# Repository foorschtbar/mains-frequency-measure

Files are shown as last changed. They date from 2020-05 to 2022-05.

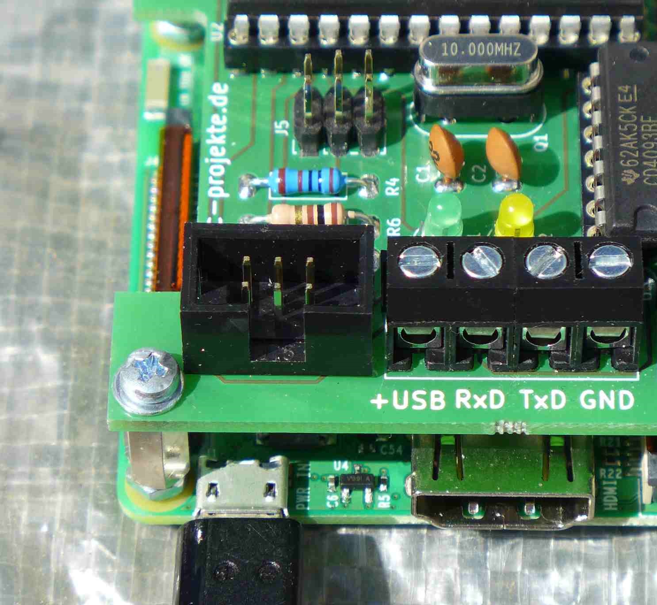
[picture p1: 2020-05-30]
Picture/Pic028.jpg

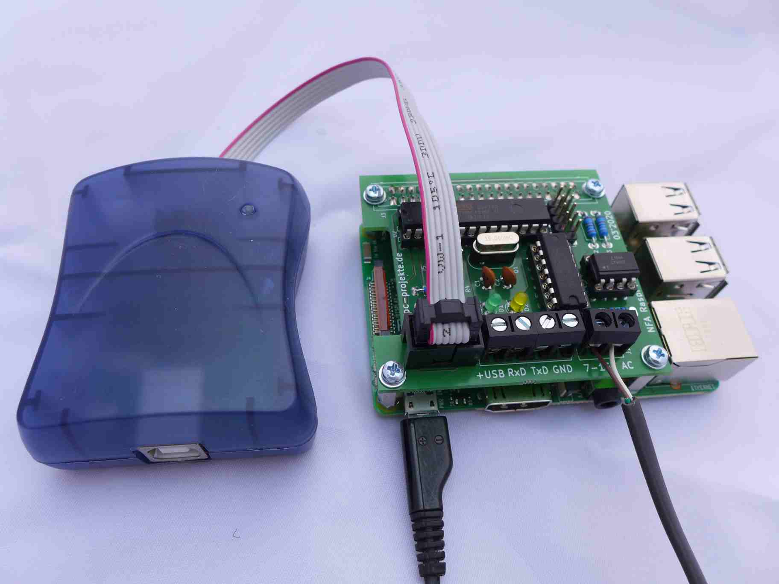
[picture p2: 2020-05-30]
Picture/Pic006.jpg

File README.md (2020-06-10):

# mains frequency measurement unit
for the RaspebrryPi or USB(TTL)Converter.

Simple electronics as a basis for measuring the mains frequency of power networks.
Use in industry, science, education or hobby.

mains frequency measure for RPi and USB mfm base board

## EN
Mains frequency measurement Base board for the RaspberryPi and USB-TTL converter

The circuit board presented here enables the exact mains frequency measurement of the power supply system (50 Hz and 60Hz). It is universally constructed and can be operated with a RaspberryPi 3/4 as well as with a USB-TTL converter.
The output of the measurement data is done via the serial interface of the used ATMega328. The µC software is programmed with the Arduino IDE. The program can be easily extended or adapted. 
The reproduction is very simple.

## DE
Netzfrequenz-Messung Basisplatine für den RaspberryPi und USB-TTL-Konverter

Die hier vorgestelle Platine ermöglicht die genaue Netzfrequenzmessung des Stromnetzes (50 Hz und 60Hz). Sie ist universell aufgebaut und kann sowohl mit einem RaspberryPi 3/4 als auch mit einem USB-TTL-Konverter betrieben werden.
Die Ausgabe der Messdaten erfolgt über die serielle Schnittstelle des verwendetet ATMega328. Die µCSoftware ist programmiert mit der Arduino-IDE. Das Programm lässt sich problemlos erweitern oder anpassen. 
Der Nachbau ist sehr einfach.

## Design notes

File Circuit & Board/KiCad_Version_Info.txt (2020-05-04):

Application: kicad
Version: (5.0.0), release build
Libraries:
    wxWidgets 3.0.3
    libcurl/7.54.1 OpenSSL/1.0.2l zlib/1.2.11 libssh2/1.8.0 nghttp2/1.23.1 librtmp/2.3
Platform: Windows 7 (build 7601, Service Pack 1), 32 bit, Little endian, wxMSW
Build Info:
    wxWidgets: 3.0.3 (wchar_t,wx containers,compatible with 2.8)
    Boost: 1.60.0
    OpenCASCADE Community Edition: 6.8.0
    Curl: 7.54.1
    Compiler: GCC 7.1.0 with C++ ABI 1011

Build settings:
    USE_WX_GRAPHICS_CONTEXT=OFF
    USE_WX_OVERLAY=OFF
    KICAD_SCRIPTING=ON
    KICAD_SCRIPTING_MODULES=ON
    KICAD_SCRIPTING_WXPYTHON=ON
    KICAD_SCRIPTING_ACTION_MENU=OFF
    BUILD_GITHUB_PLUGIN=ON
    KICAD_USE_OCE=ON
    KICAD_USE_OCC=OFF
    KICAD_SPICE=ON

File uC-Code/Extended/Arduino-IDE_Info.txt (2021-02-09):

Information:

the µcontroller software is written in the Arduino IDE and can be easily adapted. 
But for the transmission of the hex file the integrated ISP port must be used, 
because serial communication via the Arduino IDE was abandoned in favour of 
hardware simplification (3.3V µC operating voltage). A detailed description of 
the program transfer can be found in the documentation.

Information:

die µcontroller-Software ist geschrieben in der Arduino-IDE und kann problemlos 
angepasst werden. Zur Übertragung des Hex-Files muss aber der integrierte ISP-
Port verwendet werden, da auf serielle Kommunikation über die Arduino-IDE 
zugunsten der Hardware-vereinfachung (3,3V µC Betriebsspannung) verzichtet wurde. 
Eine detaillierte Beschreibung der Programm-Übertragung finden Sie in der 
Dokumentation.

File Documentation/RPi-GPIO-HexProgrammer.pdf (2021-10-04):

### µController-Programmierung mit dem RaspberryPi (GPIO-Schnittstelle) 5.2.2021

### GPIO - Vorbereitung des RaspberryPi (Raspian)

Raspi-Konsolenfenster öffnen:
Kommandos und Befehle eintragen

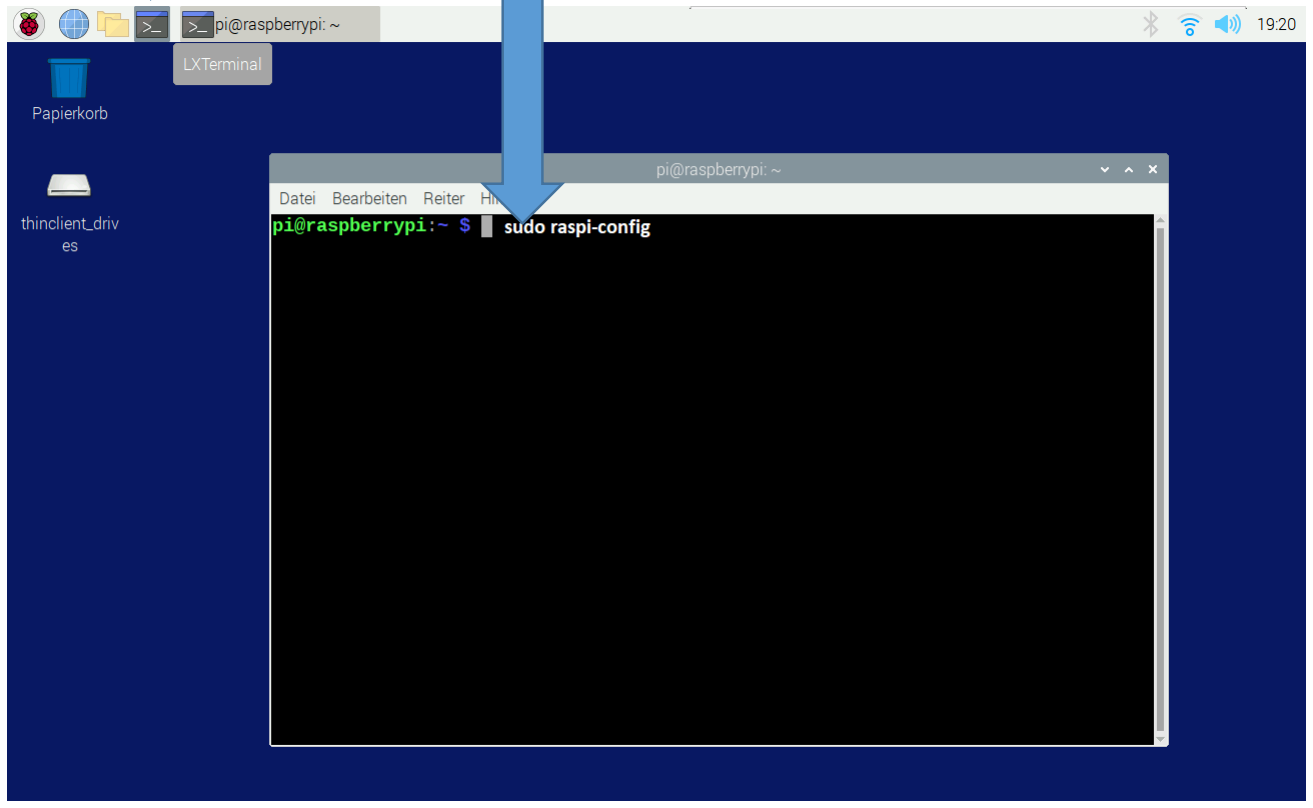
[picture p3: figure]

Diese Beschreibung gibt es auch als Videoanleitung.

Siehe www.pc-projekte.de

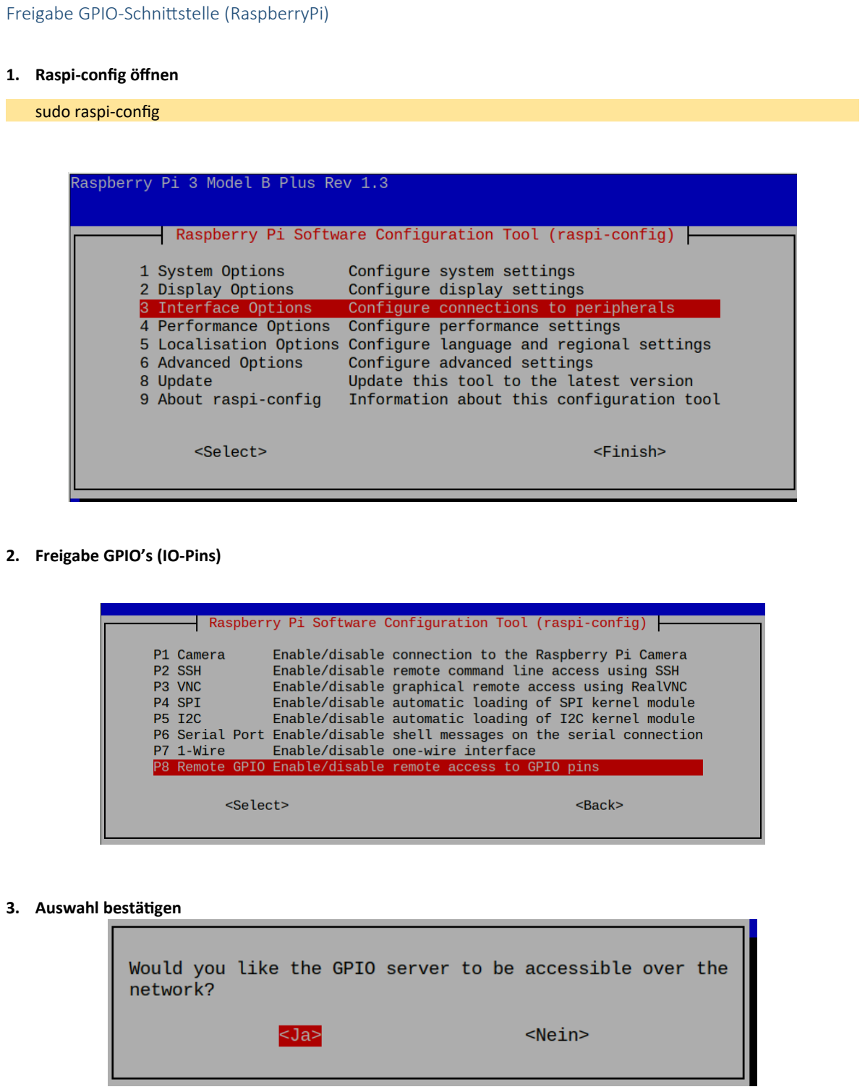
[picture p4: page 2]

Freigabe GPIO-Schnittstelle (RaspberryPi)

### 1. Raspi-config öffnen

sudo raspi-config

### 2. Freigabe GPIO’s (IO-Pins)

### 3. Auswahl bestätigen

### SerialPort - Vorbereitung des RaspberryPi (Raspian)

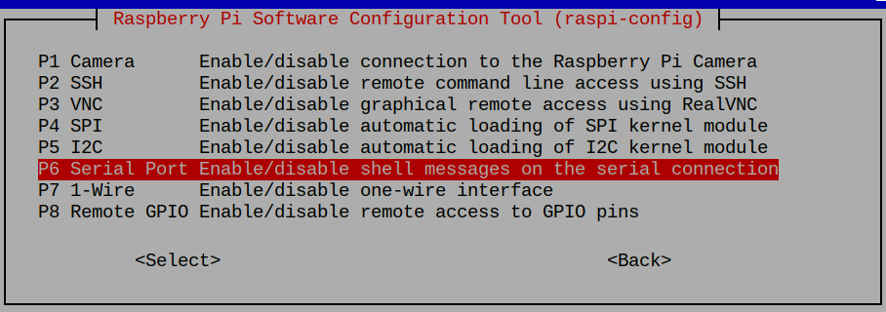
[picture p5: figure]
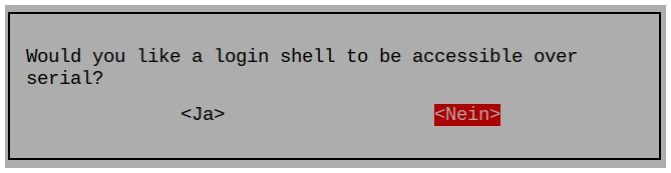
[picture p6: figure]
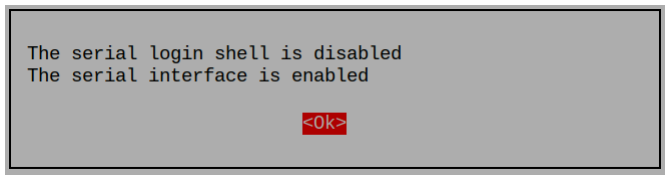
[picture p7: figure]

4. „raspi-config“ schliessen

sudo reboot

Der RaspberryPi ist nach dem Neustart nun für die GPIO (SPI)-Kommunikation und die serielle Datenübertragung vorbereitet.

Zur Übertragung der Software auf den ATMega328P muss nun das Tool „avrdude“ installiert werden.

Übertragung über den RaspberryPi mit AVRDude (HexFile -SPI-Programmer über Raspi GPIO-Port)

### 5. Installation AVRDude auf dem RaspberryPi

sudo apt-get install avrdude

### 6. Anpassung der Einstellungen AVRDude an benötigte Hardwarepins

Öffne AVRDude Konfiguration:
sudo nano /etc/avrdude.conf
Suche Zeile:
# PROGRAMMER DEFINITION

Füge unterhalb folgende Zeilen ein:

#-------------------------------------------------------------------------programmer

id = "spi_mfm";
desc = "Use RPi GPIO for mains frequency monitor unit"; type = "linuxgpio";
reset = 25;
sck = 11;
mosi = 10;
miso = 9;
;

Speichere die geänderten Einstellungen

### 7. Test AVRDude / Auslesen der Fuses

sudo avrdude -c spi_mfm -p m328p -P /dev/spidev0.0 -U lfuse:r:-:b

### 8. Setzen der benötigten Fuses mit folgenden Kommandozeilen:

sudo avrdude -c spi_mfm -p m328p –P /dev/spidev0.0 -U lfuse:w:0b11111111:m

sudo avrdude -c spi_mfm -p m328p –P /dev/spidev0.0 -U hfuse:w:0b11011010:m

sudo avrdude -c spi_mfm -p m328p –P /dev/spidev0.0 -U efuse:w:0b11111111:m

### 9. Übertrage das aktuelle HEX-Programm (z.B. mfm_2.hex)

(aktualisiert mit Arduino-IDE oder als Download von der Projektseite)

sudo avrdude -p m328p -c spi_mfm -P /dev/spidev0.0 -U flash:w:mfm_2.hex

Hexprogramm z.B. „mfm_2.hex“ , oder eigener/neuer Quellcode

Getestet mit dem RaspberryPi 3

This document is part of the project description

MAINS FREQUENCY MONITORING UNIT

Mains frequency measurement and monitoring for the RaspberryPi (and USB-TTL), extended documentation

www.pc-projekte.de

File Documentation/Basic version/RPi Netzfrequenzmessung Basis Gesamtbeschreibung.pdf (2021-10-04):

# MAINS FREQUENCY MONITORING UNIT Netzfrequenzmessung für den RaspberryPi (und USB-TTL) Basisdokumentation

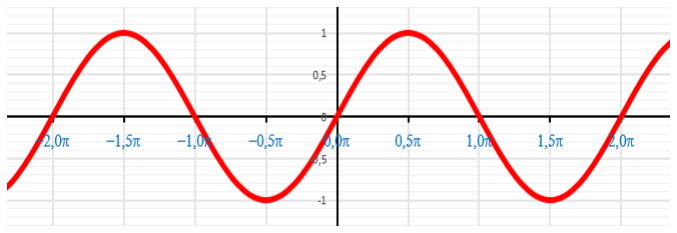
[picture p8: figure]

## Der Blick in unser Stromnetz

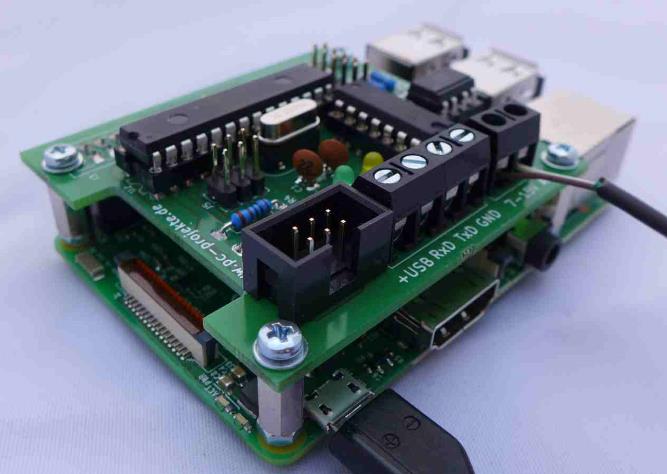
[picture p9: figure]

### Mueller, Jens, www.pc-projekte.de

pc_projekte.de@arcor.de

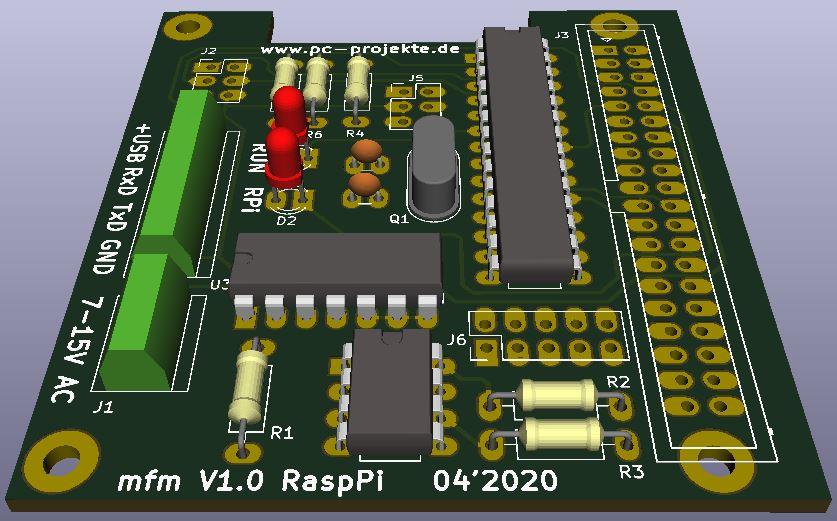
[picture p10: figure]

### Projektbeschreibung MAINS FREQUENCY MONITORING V1.0a

Messen und beobachten Sie Ihre Netzfrequenz. Die Abweichung vom Sollwert stellt einen direkten Qualitätsindikator über die angebotene Momentanleistung der Kraftwerke und die Abnahme der Verbraucher dar. Die Netzfrequenz ist somit ein Garant der Netzstabilität und zeigt Effekte des Intraday- Stromhandels

04.10.2021

Inhaltsverzeichnis

## Lizenz

### Dokumentation

### Creative-Commons-Lizenz

Diese Projektdokumentation steht unter der Creative-Commons-Lizenz Namensnennung - Weitergabe unter gleichen Bedingungen 4.0 International. Um eine Kopie dieser Lizenz zu sehen, besuchen Sie
http://creativecommons.org/licenses/by-sa/4.0/

Dieses Dokument ist ein Basis-Dokument und gehört zur die Veröffentlichung OSHWA Openhardware

Eine Projekt-Extended-Version mit aktuellen Features und Erweiterungen steht in Kürze zum Download bereit.

### OpenHardware (OSHWA)

Die Hardware ist unter einer CERN-Lizenz veröffentlicht als OpenHardware (Open-Source-Hardware)

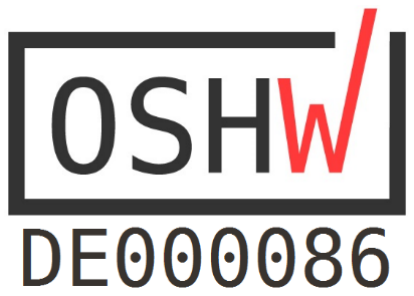
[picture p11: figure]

Das Projekt ist OSHWA- zertifiziert unter Nr. DE000086.

Gesamte Projektdokumentation und alle Lizenzen unter

https://gitlab.com/jm_wtal/mains-frequency-measure

Infos zu Oshwa: https://www.oshwa.org/definition/german

Software / Quellcode

Der Quellcode steht unter der GNU GPL 3-Lizenz:

- Freiheit das Programm für jeden Zweck auszuführen
- Freiheit den Quellcode zu studieren und anzupassen
- Freiheit, das Programm zu kopieren
- Freiheit, das veränderte Programm zu kopieren

Diese Freiheiten sollten auch langfristig sichergestellt werden. Zu diesem Zweck enthält die GPL zwei wesentliche Klauseln:

- Jedes Derivat muss ebenfalls vollständig unter der GPL lizenziert werden.
- Bei Weitergabe des Programmes in Binärform muss der Quellcode des gesamten Programms mitgeliefert oder auf Anfrage ausgehändigt werden.

### Hintergrund

Unser Stromnetz
Die Netzfrequenz in Europa beträgt 50Hz. Eine Abweichung vom Nennwert ist ein direktes Fenster der elektrischen Erzeugung und dem Verbrauch. Der abgegebenen Leistung muss zu jedem Zeitpunkt eine gleich große Leistungsaufnahme gegenüberstehen.

Kommt es zu Abweichungen, führt das zu einer Veränderung der Netzfrequenz: Bei einem Überangebot von elektrischer Leistung kommt es zu einer Steigerung der Netzfrequenz, bei einem Unterangebot zu einer Absenkung. Normalerweise sind diese Abweichungen im westeuropäischen Verbundnetz minimal und bewegen sich im Bereich von 49,80Hz - 50,20Hz. Die Aufgabe der so genannten Leistungsregelung im Stromnetz ist es, die Lastschwankungen auszugleichen und so die Netzfrequenz auf konstantem Nennwert zu halten.

In Europa, Asien, Australien, dem Großteil von Afrika und Teilen von Südamerika wird für das allgemeine Stromnetz, in sogenannten Verbundnetzen, eine Netzfrequenz von 50 Hz verwendet. In Nordamerika verwendet man im öffentlichen Stromnetz eine Netzfrequenz von 60 Hz. Die Unterschiede sind durch die historische Entwicklungsgeschichte der ersten Stromnetze in den 1880er und 1890er Jahren bedingt und haben heute keinen technischen Grund.

Einige Eisenbahnen wie die ÖBB, SBB und die Deutsche Bahn nutzen für ihre Bahnstromversorgung eine nominale Frequenz von 16,7 Hz. Früher betrug die nominale Bahnnetzfrequenz 16 ²
⁄3 Hz, was genau
einem Drittel der im Verbundnetz verwendeten 50 Hz entspricht. Einige Eisenbahnen und auch industrielle Abnehmer in Nordamerika werden aus historischen Gründen mit einer Netzfrequenz von 25 Hz versorgt. Die vergleichsweise niedrigen Netzfrequenzen resultieren aus der technologischen Entwicklung der ersten elektrischen Maschinen: Anfang des 20. Jahrhunderts konnte man elektrische Maschinen größerer Leistung nur mit diesen niedrigen Frequenzen bauen. Wegen des großen Umstellungsaufwandes werden jedoch die damals eingeführten niedrigen Netzfrequenzen auch noch heute beibehalten.

In speziellen Bereichen, z. B. im Bordnetz von Flugzeugen, sind höhere Netzfrequenzen üblich, z. B. 400 Hz, da sich dafür kleinere und leichtere Transformatoren bauen lassen und die Leitungslängen kurz sind.

### Netzfrequenz als Qualitätsindikator

Die Netzfrequenz und deren Abweichung vom Nennwert ist ein direkter Qualitätsindikator über die Relation der über Erzeuger wie Kraftwerke angebotenen elektrischen Momentanleistung und der Abnahme der elektrischen Momentanleistung durch Verbraucher. Elektrische Energie kann in Verbundnetzen kaum gespeichert, sondern nur zwischen Erzeuger und Verbraucher verteilt werden. Der abgegebenen Leistung muss, bis auf die Blindleistung bei Wechselstrom, zu jedem Zeitpunkt eine gleich große Leistungsaufnahme gegenüberstehen.

Kommt es zu Abweichungen, führt das in Wechselspannungsnetzen zu einer Veränderung der Netzfrequenz: Bei einem Überangebot von elektrischer Leistung kommt es zu einer Steigerung der Netzfrequenz, bei einem Unterangebot zu einer Absenkung. Im Normalfall sind diese Abweichungen im westeuropäischen Verbundnetz minimal und bewegen sich unter 0,2 Hz. Eine Frequenzabweichung von 0,2 Hz entspricht im europäischen Verbundsystem einer Leistungsdifferenz von ca. 3 GW, welche auch gleich dem sogenannten Referenzausfall aus dem Continental Europe Operation Handbook entspricht und ca. dem ungeplanten Ausfall von zwei größeren Kraftwerksblöcken entspricht. Die Aufgabe der Leistungsregelung in Verbundnetzen ist es, die zeitlichen Schwankungen auszugleichen und so die

Netzfrequenz auf konstantem Nennwert zu halten. Je kleiner ein Stromversorgungsnetz ist und je schlechter die Netzregelung funktioniert, desto stärkere Schwankungen treten bei der Netzfrequenz auf.

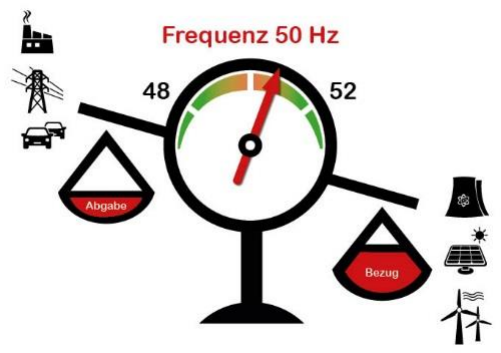
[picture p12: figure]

Unterangebot der Energie | Überangebot der Energie

Diese Schwankung kann man messen:

Ich möchte mit meinem Projekt die Dynamik des Stromnetzes sichtbar machen. Die Elektronik erfasst die Netzfrequenz und ermöglicht, abgeleitet über eine mathematische Funktion, die Anzeige der Netzlastdifferenz in MW (Megawatt). Diese Netzlastdifferenz entspricht der primären Regelleistung.

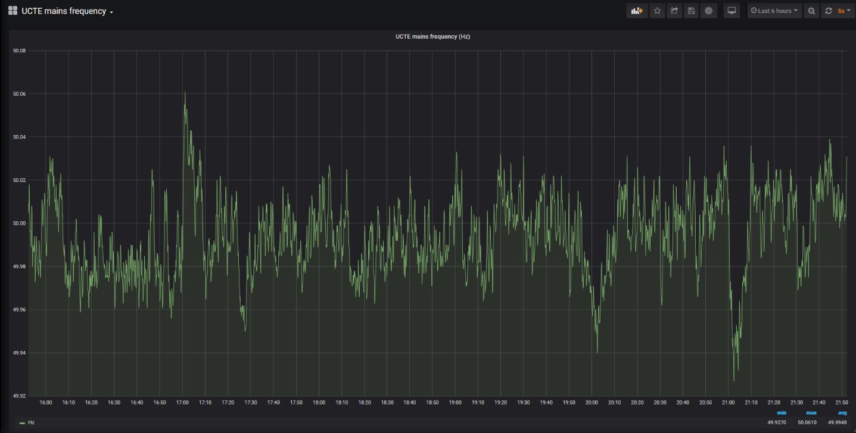
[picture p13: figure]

Bild: Netzfrequenzmessung (Beispiel grafische Auswertung mit Grafana®)

Es handelt sich um ein privates, nicht kommerzielles Projekt. Die Elektronik, µController- und Projektsoftware ist von mir entwickelt (siehe auch Creativ-Commons-Lizenz).

Platinen, Programmierservice und Bauteile siehe Bestellmöglichkeit.

Einsatz der Netzfrequenzplatine

Messplatine zur Aufzeichnung, Informations-, Meldungs-, Alarmierungs-und Beobachtungszwecken der Netzfrequenz

Das Gerät kann flexibel an die Kenndaten eines Stromnetzes angepasst werden (z.B. 60Hz-Netz). Eine Berechnung und Ausgabe der Netzlastdifferenz (primäre Regelleistung) ist in Vorbereitung.

Die Ausgabe erfolgt über die serielle Schnittstelle. Die Platine ist für den RaspberryPi konzipiert, kann aber alternativ auch mit einen USB-TTL-Wandler verwendet werden.

Außerdem sind Output-Ausgaben für Alarmierungs- und Meldesysteme vorbereitet.

Eine Bereitstellung der Messwerte über eine Modbus-TCP-Software steht in Kürze zur Verfügung, weitere Protokolle z.B. MQTT (IoT), IEC60870-4-104 FW-Protokoll oder als Logic-Device einer IEC61850-Anlage sind geplant.

Bauteile (Info)

Es ist keine smd-Technik verwendet, um die Nachbaubarkeit so einfach wie möglich zu gestalten. Die entsprechenden Nachbauanleitungen und Bauteillisten sind ab Seite 20 zu finden (Bestellmöglichkeit der Platine und der Bauteile siehe Seite 27). Eine teilbestückte Platine mit SMD ist in Vorbereitung.

Software
(µController ATMEGA328-16PU DIP-28 8-Bit 10 MHz (Arduino - Kompatibel)

Die aktuelle Software kann auf der Gitlab-Seite oder unter www.pc-projekte.de bzw. http://www.netzfrequenzanzeige.de heruntergeladen werden.

Messspannung

Warnung: Verwenden Sie NIEMALS direkte 230V Netzspannung zur Netzfrequenzmessung!

Messspannung: Netzteil (oder Trafo) mit Wechselspannungsausgang

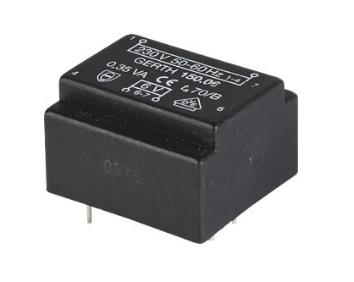
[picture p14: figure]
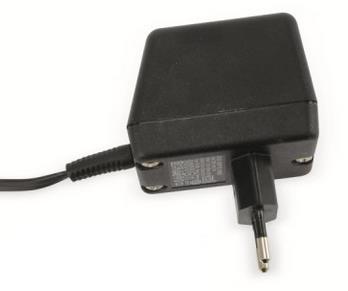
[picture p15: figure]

Bild: | Beispiele für Klingeltrafos | Bild: | Steckernetzteil (AC-AC) | Bild: Printtrafo

Siehe auch Hinweis / Gewährleistungsausschluss.

### Frequenzmessung

Kurzbeschreibung Messablauf

Die Frequenzmessung erfolgt über eine Flankenauswertung des Wechselspannungssignals. Das Signal wird über zwei Optokoppler und einem RS-FlipFlop (4093-Nand-Gatter als RS-FlipFlop) dem µController zugeführt und mit dem 10MHz-Quarz-Takt und des Timer1 (als Counter) des µControllers ausgewertet.

Genauigkeit

Die Messgenauigkeit der Netzfrequenzmessung ist auch ohne Kalibrierung sehr hoch. Ausschlaggebend ist die Genauigkeit des Quarz Q1 (und die korrekte Größe C1 und C2 , abgestimmt auf den Q1 ). Der Messfehler der Frequenzmessung (ohne Kalibrierung oder Netzfrequenztrigger-Vorschaltplatine) liegt unter ± 1 mHz.

Eine Kalibrierung der Messung ist über eine Quellcode-Einstellung möglich.

Temperaturbereich

Die Netzfrequenzanzeige sollte bei Raumtemperatur verwendet werden. Direkte Sonneneinstrahlung auf das Gehäuse oder die Platine und die damit verbundene Temperatureinwirkung können das Messergebnis verfälschen.

Netzrückwirkungen

Die Netzfrequenzanzeige ist im Normalfall unempfindlich gegenüber in der EN50160 beschriebenen Netzrückwirkungen.

Sehr starke elektrische Impulse in der Umgebungen, ungewöhnlich hohe Oberwellenanteile (Netzrückwirkung) oder Rundsteuersignale in der Messspannung können das Messergebnis verfälschen.

Siehe auch Messdatenaufbereitung

Messbereichserkennung bei Programmstart
Beim Programmstart wird eine automatische Netzfrequenzerkennung durchgeführt.

Nach der erfolgreichen Erkennung werden die entsprechenden Grenzbereiche der erkannten Netzfrequenz in den Filterstufen verwendet.

Min/Max | 50Hz-Netz | 60Hz-Netz | 16,7 Hz*
Max f | 45 Hz | 55 Hz | 22 Hz
Min f | 55 Hz | 65 Hz | 12 Hz

*) 16,7 Hz-Netze

Bahnnetzfrequenz z.B. Deutschland, Österreich und Schweiz (Normalspur)

16,7 Hz-Messung ist grundsätzlich möglich, ist aber momentan nicht integriert

Durch die manuelle Einstellung kann die entsprechende Netzfrequenz vorgegeben werden

Automatische Erkennung | 50 Hz / 60 Hz (16,6 Hz) | FA = 0
50 Hz-Netz | 45,000 Hz – 55,000 Hz | FA = 50
60 Hz-Netz | 55,000 Hz – 65,000 Hz | FA = 60
Eine Version für 16,7 Hz ist vorbereitet | 12,000 Hz – 22,000 Hz | FA = 16

### Einstellungen für das Prescale-Messverfahren

Für das Messverfahren können einige Einstellungen vorgenommen werden, um Messdauer und Messperioden an den µController anzupassen bzw. zu optimieren.

Dazu können im µController-Programm einige Parameter einstellt oder geändert werden.

Einstellungen im Arduino-Quellcode:

Einstellung | Voreinstellung (Empfehlung) | Funktion
Prescaler | 64 | Interner Teiler des µC-Taktes (ATMega328-Takt)
Messperiode | 18 | Maximale Periodenzählung (Flankenzähler bis nächste Frequenzberechnung)
Dividend | 2812500 | Konstanter Wert für Frequenzumrechnung (ergibt sich aus dem Prescaler und der Messperiode)
Sperr | 2400 | Sperrzeit nach erkannter Eingangsflanke zur Unterdrückung von Signalprellung
UBRR | 0X40 | Korrekturwert für serielle Schnittstelle (Anpassung der Baud-Rate an den 10MHz-Takt)
DiffMAX | 60 | Maximalwert der zulässigen Frequenzänderung (siehe Differenz-Komperator-Filter)
FA | 0 | Automatische oder manuelle Frequenzbereicheinstellung (Automatische Netzfrequenzerkennung bei Programmstart)
Calibration | 0 | Messwert-Kalibrierung, falls benötigt

Auf den nachfolgenden Seiten sind die Einstellungen detailliert beschrieben.

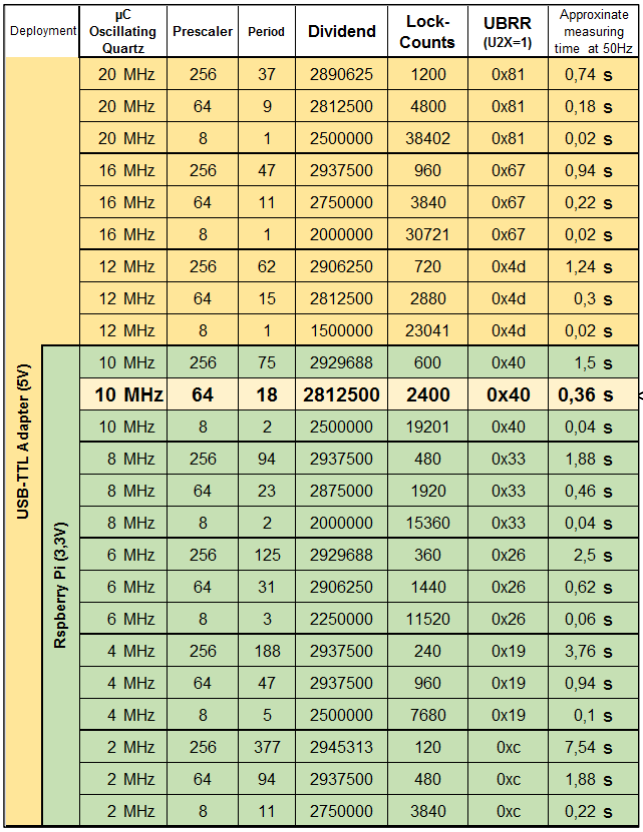
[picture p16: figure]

Tabelle: Übersicht optimierte Einstelldaten für die Netzfrequenzmessung

Einstellungen im Arduino-Programmcode (Basisquellcode):

// Settings / Einstellungen

// ***************************************************************************************************

#define F_CPU 10000000

const word Prescaler = 64; | // Prescaler (0,8,64,256,1024)
const byte Messperiode = 18; | // Period
const unsigned long Dividend = 2812500; | // DIVIDEND Calculation constant
const word Sperr = 2400; | // Lock-Counts
const int UBRR = 0x40; | // Correction serial baud/clock
const int DiffMAX = 60; | // DifferenzMAX
byte FA = 0; | // Selection 0 = Auto, 50=50Hz, 60=60Hz
const short Calibration = 0; | // MeasureCalibration

// ***************************************************************************************************

Alle Programmeinstellungen sind in den Zeilen 10 – 20 im Arduino-Quellcode (Basiscode) zu finden.

<== Empfohlene Einstellung Raspberry Pi

- | Quarz | 10MHz
- | Prescaler | 64
- | Period | 18
- | Dividend | 2812500
- | Lock-Counts | 2400
- | UBRR | 0x40
(Programmierung über ISP-Port)

### Messung der Netzfrequenz

Grundprinzip ist der Timer1 des µControllers, der ohne weitere Verarbeitung mit dem Start des µControllers den festen Takt 10MHz DIV 64 eingestellt ist. Der Timer1 wird mit dieser Einstellung der Referenztakt, aus dem die Netzfrequenz nun abgeleitet wird. Die zeitliche Gesamtlänge des durchlaufenden Timer1 (0… 65535) beträgt 423ms. Die dadurch optimierte Periodenanzahl der Netzfrequenzmessung (für 45 Hz) beträgt 18.

Berechnung
Der Timer 1 läuft im eingestellten Prescaleverfahren mit dem (geteilten) Takt des µControllers als Counter.

Die Netzfrequenz wird über den Optokoppler und dem Schmitt-Trigger dem INT0 des µController zugeführt. Ein erkanntes Triggerereignis führt zum internen Hochzählen des Periodenzählers.

Die Trigger-Sperrzeit (Sperr/ LockCounts 2400) verhindert dabei eine zu schnelle Mehrfachauswertung der Flanke (z.B. durch ein Störsignal).

Ist der maximale Periodenzählwert erreicht, erfolgt die Übernahme des Zählwerts aus Timer1.

Der Counterwert des Timer1 wird als Divisor mit dem konstanten Dividend (2812500) die Berechnungsgrundlage für die Netzfrequenz. Zusätzlich wird noch der Faktor 1000 multipliziert. Die Ausgabe der Netzfrequenz erfolgt dann in mHz. Das hat den Vorteil, dass sämtliche Netzfrequenzberechnungen bis zu diesem Zeitpunkt ausschließlich in Festkomma-Arithmetik ausgeführt werden. Dieser Vorgang wird daher im µC sehr schnell ausgeführt (dadurch sogar lauffähig auf einem ATTiny).

Berechnung:

fMess (Variablenbezeichnung im Quellcode) in mHz (Bsp. 50021 = 50,021 Hz)

Der vorläufige Frequenzwert (fMess) wird nun über einige Filterstufen geführt.

Die Ausgabe (Frequenz) erfolgt als serielles Protokoll auf dem TxD-Port des µControllers

UBRR

Um die 19200Bd-Ausgabe der seriellen Schnittstelle auf den 10MHz-Quarz anzupassen, muss über die Eingabe der UBRR-Registerwert angepasst werden.

Für einen 10MHz-Quarz muss UBRR = 0x40 eingestellt werden.

### Detaillierte Beschreibung der Messung

### Eingangsbeschaltung Schmitt-Trigger

Die Eingangsbeschaltung (Netzfrequenz-Messeingang) ist über 2 Optokoppler galvanisch getrennt. Die Messspannung wird über ein Trafo zugeführt und sollte zwischen 7V- 15 V ~ AC liegen. Der Strom der verwendeten Messspannung beträgt nicht mehr als 20mA. Zur Messung sollte ein kurzschlussfester Trafo oder ein Klingeltrafo verwendet werden. Die Eingangsbeschaltung der Optokoppler U1 (U1a/U1b) wird durch R1 strombegrenzt (siehe auch Informationen Bauteile Seite 20).

Die Optokoppler steuern über ein NAND-Gatter aufgebauten Schmitt-Trigger an (CMOS 4093, IC U3), der dann das Messsignal als Rechtecksignal dem INT0-Eingang des µControllers weiterleitet.

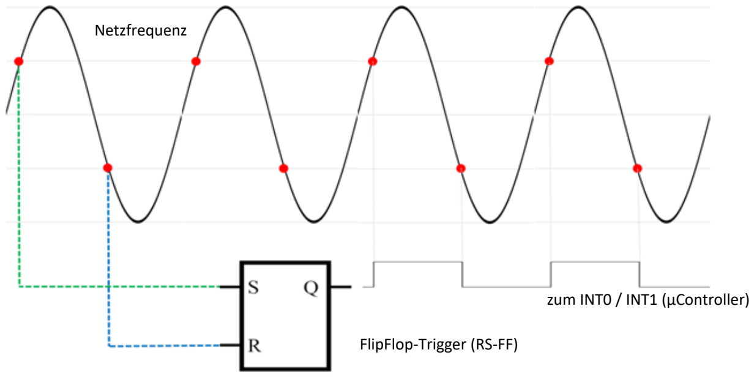
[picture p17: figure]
Netzfrequenz; zum INT0 / INT1 (µController); FlipFlop-Trigger (RS-FF)

Bild: Schematische Darstellung der Flankenauswertung (Schmitt-Trigger)

Vorteil dieser Messdatenaufbereitung ist, dass auch ein sehr verrauschtes Eingangssignal sicher erfasst wird.

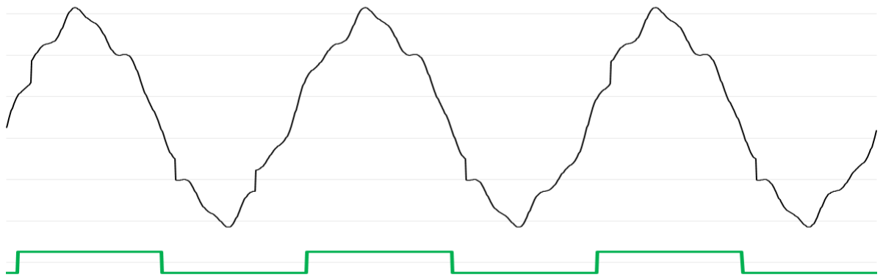
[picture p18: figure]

Bild: Schematische Darstellung eines verrauschtes Eingangssignal und mit Ausgangssignal (hinter dem Schmitt-Trigger)

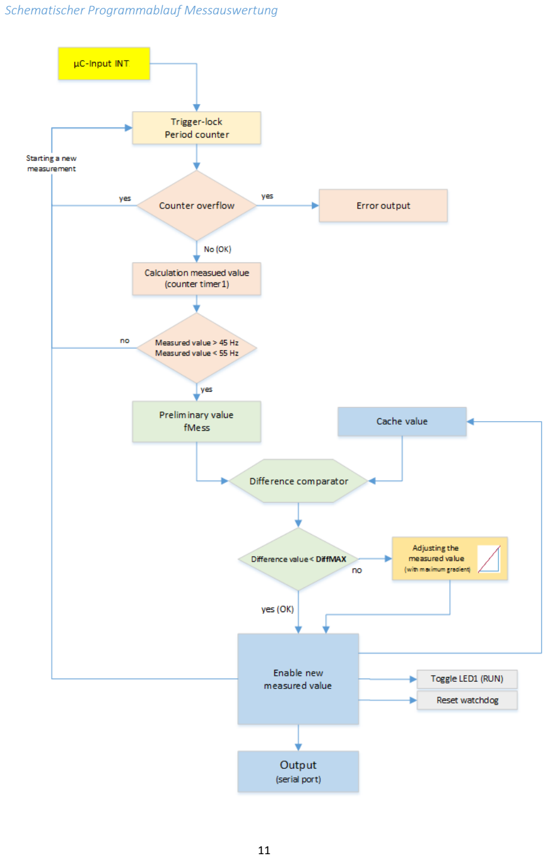
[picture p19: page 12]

Schematischer Programmablauf Messauswertung

Auswertung mit dem µController INT0

Flankenerkennung und Triggersignal-Sperre:

Erkennt der µController eine Flanke, wird sofort eine Sperrzeit (ca. 15ms) gestartet, um nachfolgende Messspitzen zu unterdrücken. Eine mögliche zu frühe Flanke wird durch die nachfolgende Stufe sofort kompensiert, da nun eine Mittelwertbildung folgt.

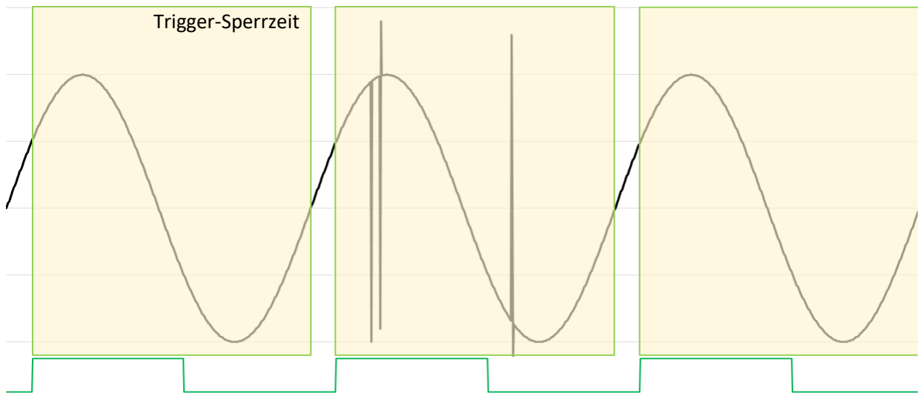
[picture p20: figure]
Trigger-Sperrzeit

Bild: Schematische Darstellung der Trigger-Sperrzeit

Sperrzeit / Lock-Counts

Die Sperrzeit nach einem Impuls ist so gewählt, dass das nächste Triggersignal nur mit einer Frequenz unter 65 Hz passen würde.

Auswertung der Messcounts

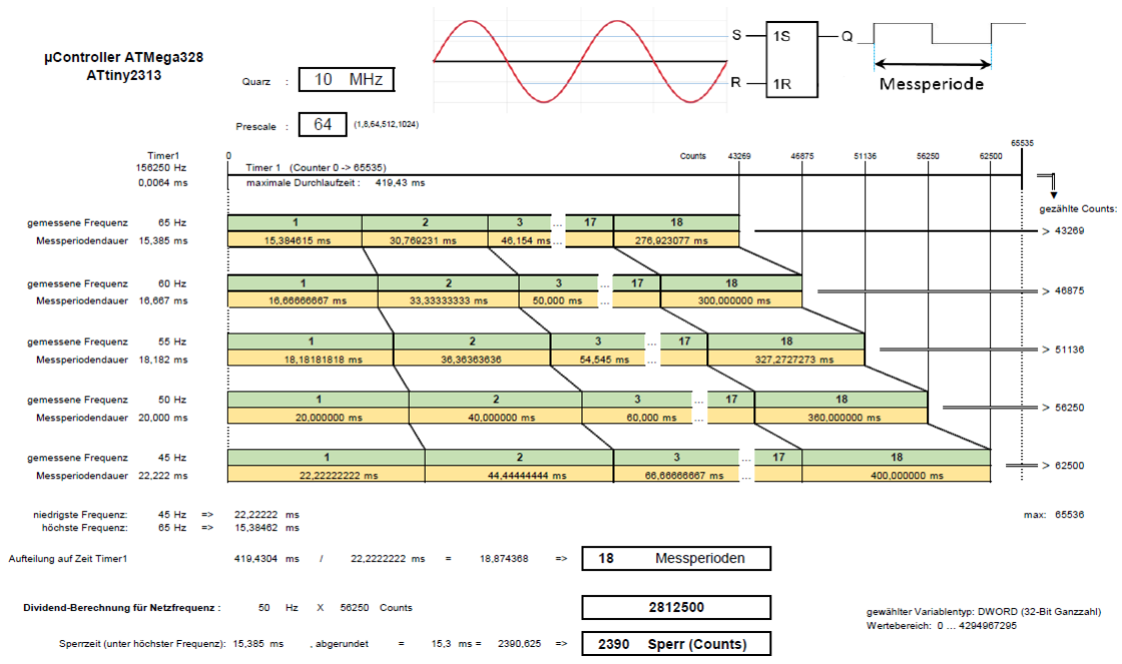
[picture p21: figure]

Plausibilitätsfilter

Bevor der gemessene Netzfrequenzwert weiterverarbeitet wird, durchläuft der vorläufige neue Messwert noch eine zweistufige Prüfung: Dabei wird festgestellt, ob der gemessene Netzfrequenzwert grundsätzlich im zulässigen Bereich liegt:

Messung | 50 Hz-Messung | 60Hz-Messung | 16,7 Hz*
Prüfung f> | f > 45 Hz | f > 55 Hz | 22 Hz
Prüfung f< | f < 55 Hz | f < 65 Hz | 12 Hz

Nach dieser ersten Überprüfung, der unplausible Messwerte ausschließt, geht es weiter zum Differenz-Filter

Differenz-Komperator-Filter

Funktionsweise des Differenz-Komperator-Filters:

Der Differenz-Komperator-Filter verwendet prinzipiell die Vorgabe der maximalen Netzgradiente. Eine Netzfrequenzänderung über der maximalen Netzgradiente wird nur bedingt berücksichtig.
Sollten aber zwei aufeinanderfolgende Messungen die Gültigkeitsprüfung passieren, wird auch eine sehr schnelle Änderung sofort übernommen.

Ablauf: Der vorläufige (neue) Messwert wird mit dem letzten gültigen Messwert verglichen.
Durch die Differenzbildung der beiden Messwerte wird die Differenzgröße ermittelt.

Diff = ABS (fpreliminary − fMess )

Ist die Differenz (Absolutwert) kleiner der Voreinstellung DiffMAX, wird der neue Wert (Preliminary Value) zum gültigen Messwert fMess.

Ist die Differenz größer, wird der aktuelle Messwert fMess in Höhe der Voreinstellung DiffMAX dem neue Wert (Preliminary Value) nachgeführt.

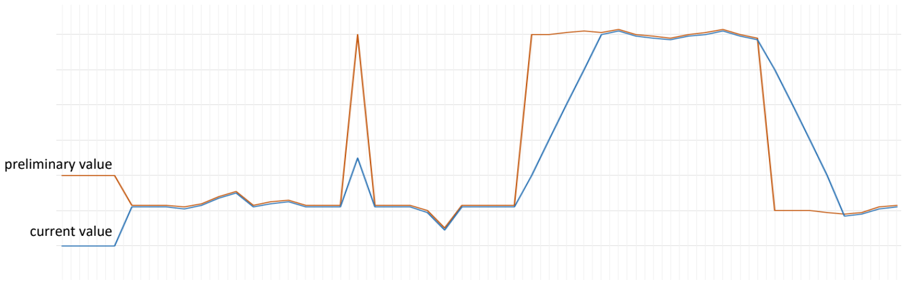
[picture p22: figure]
preliminary value; current value

Bild: schematische Darstellung Verlauf Messdaten Differenz-Komperator-Filter

Die Netzgradiente hängt von vielen Netz-Schaltungszuständen, Einspeisungen, Netzlastsituationen und des Messortes ab. Deshalb ist der nachfolgende DiffMAX-Wert eine Einstellungsempfehlung für das UCTE-Netz.

Die Voreinstellung des DiffMAX-Filters beträgt 60mHz/s (Empfehlung).

Programm Diff-Filter (Arduino-Programm)

word Diff_filter(word filter_wert) | // Messdaten in mHz im WORD-Format
{
int Diff = filter_wert - Cachewert;
if ( abs(Diff) > DiffMAX ) | // bei Überschreitung DiffMAX
{
if ( Diff > 0) filter_wert = Cachewert + DiffMAX; | // Änderung (positive Steigung) max
if ( Diff < 0) filter_wert = Cachewert - DiffMAX; | // Änderung (negative Steigung) max
}
Cachewert = (int)filter_wert;
return filter_wert;
}

Kalibrierung

Normalerweise braucht die Netzfrequenzplatine keine Kalibrierung.

Sollte aber eine Kalibrierung doch erforderlich sein, kann in der Einstellung ein Kalibrierungswert beigefügt werden. In Kürze können verschiedene Einstellungen ein Softwaretool (über eine EEP-Datei) geänderte Einstellung ins EEProm des ATMega328 übertragen werden. Nach einen Neustart werden die geänderten Einstellungen verwendet.

### Frequenz + Calibration → Ausgabe zur seriellen Schnittstelle

Serielles Protokoll

Einstellung der seriellen Schnittstelle

Baudrate: 19200 Baud | Parity: None | Stoppbit: 1 | Handshake: None

UBRR = 0x40

Um die Ausgabe der seriellen Schnittstelle auf den 10MHz-Quarz anzupassen, muss über die Eingabe der UBRR-Registerwert angepasst werden. Für einen 10MHz-Quarz muss UBRR = 0x40 eingestellt werden.

Auswahl der Protokolle

In der Basisversion ist diese Möglichkeit noch nicht realisiert. In der extendend Version können über die Jumperstellung der J5-Schnittstelle die Ausgabeprotokolle ausgewählt werden.

Basisprotokoll 6-Byte-Protokoll (5+1)

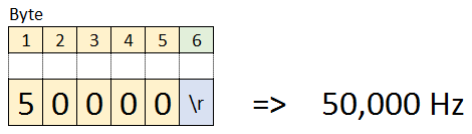
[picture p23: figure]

Bild: Aufbau und Telegrammverlauf 6-Byte-Protokoll

Aus Ausgabe des Basisprotokolls auf der seriellen Schnittstelle erfolgt in mHz.

LEDs

LED 1: RUN-LED

LED1 (RUN) Zustandswechsel (toggle) bei jedem erfolgreichen Filterdurchlauf.

(toggle= wechselt den binären Zustand)

Arduino-Ausgabe : 4 (=Pin6, PD4)

LED 2: RPi-Led

Die LED 2 kann durch ein Programm auf dem RaspberryPi angesteuert werden.

RaspberryPi Ausgabe : GPIO5 (=Pin12)

### Verwendung mit einem USB-TTL-Konverter

Die Netzfrequenzplatine kann auch ohne einem RaspberryPi zur Netzfrequenzmessung verwendet werden. Die Datenausgabe und die Stromversorgung ist dann über die die USB-Schnittstelle (USB-TTL-Konverter) realisiert.

Für diese Betriebsart ist der Anschluss J4 vorbereitet.

JP4: | Dieser Port stellt das serielle Telegramm bereit (Details siehe „serielles Protokoll“)
Pin | Bezeichnung | Funktion | Hinweis
1 | GND | Masse / GND
2 | RxD | Empfangsrichtung (zur USB), TTL-Pegel* | Vom µC (TxD)
3 | TxD | Empfangsrichtung (von USB), TTL-Pegel* | Zum µC (RxD)
4 | +5V | Versorgungsspannung 5V DC

*) siehe TTL-Pegel

Sonstiges / Erweiterungen:

Stiftleiste J5

J5 vorbereitet für Protokollauswahl (serielle Schnittstelle)

Stiftleiste J6

J6 vorbereitet als universelle IO-Schnittstelle (z.B. Relaisausgabe)

## Nachbau

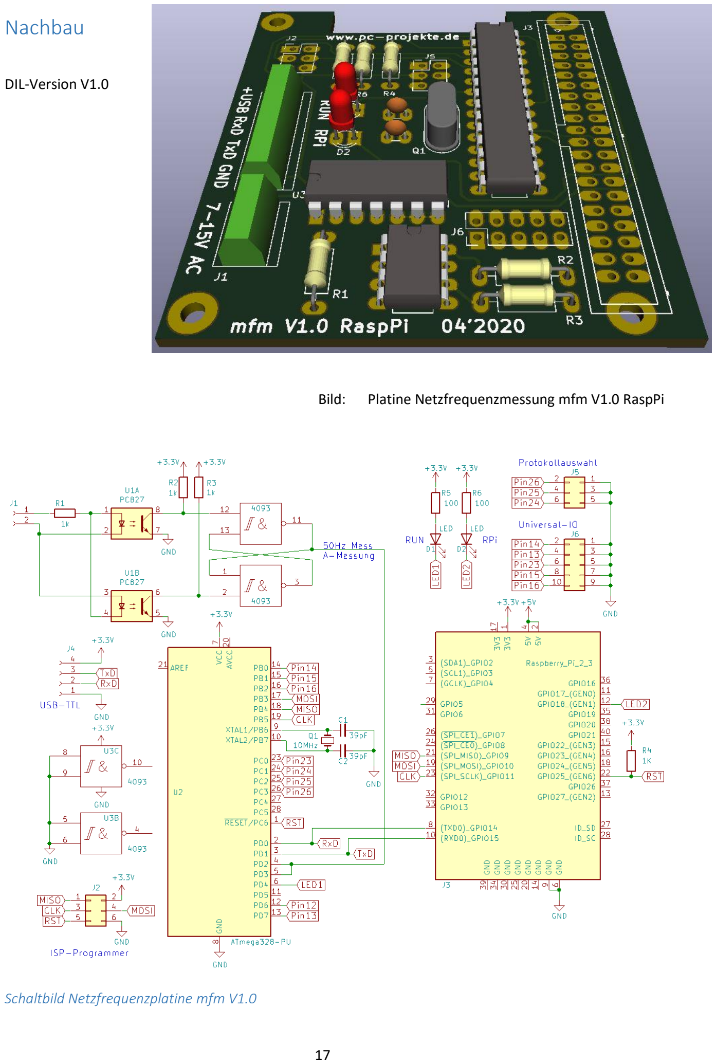
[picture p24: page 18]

DIL-Version V1.0

Bild: Platine Netzfrequenzmessung mfm V1.0 RaspPi

Schaltbild Netzfrequenzplatine mfm V1.0

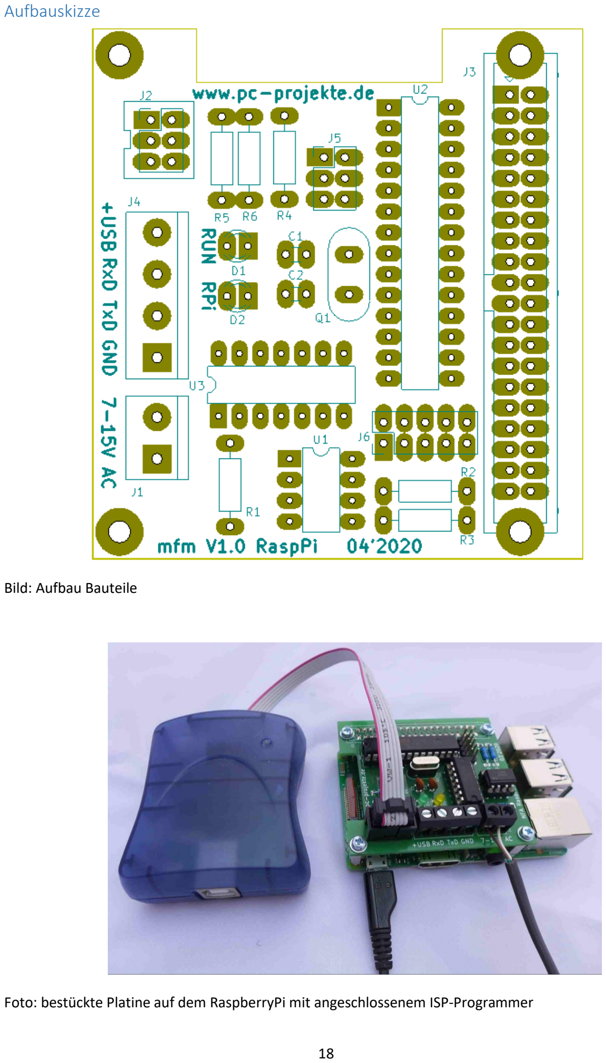
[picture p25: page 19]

### Aufbauskizze

Bild: Aufbau Bauteile

Foto: bestückte Platine auf dem RaspberryPi mit angeschlossenem ISP-Programmer

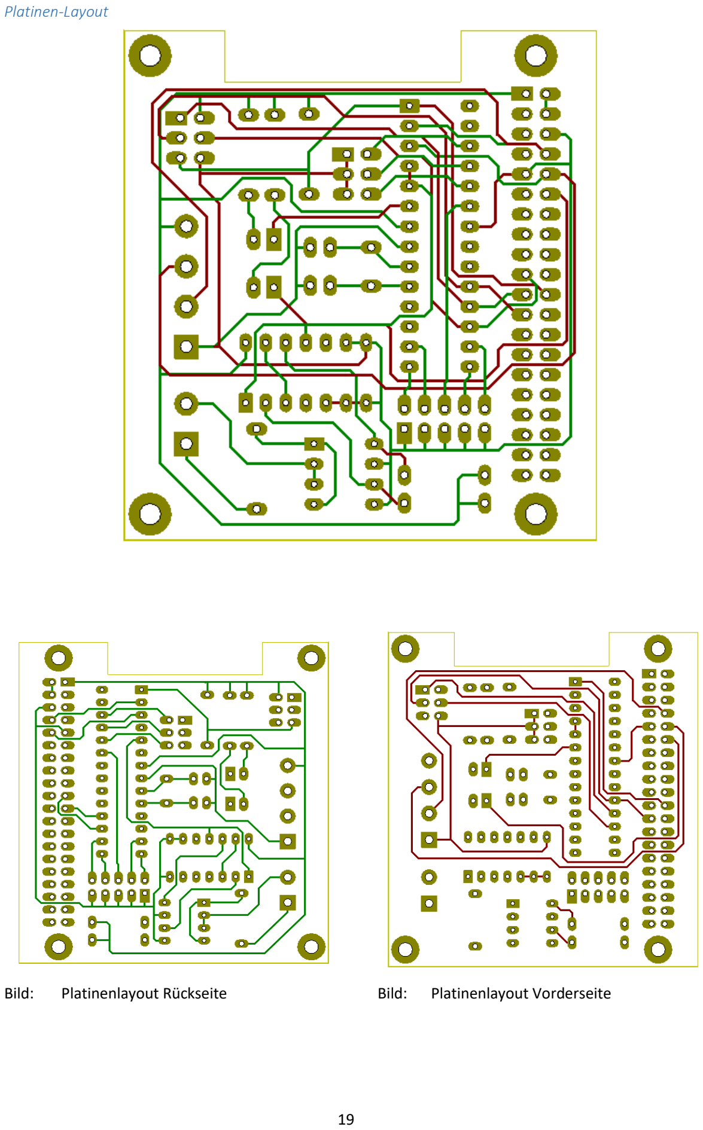
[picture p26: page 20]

Platinen-Layout

Bild: | Platinenlayout Rückseite | Bild: | Platinenlayout Vorderseite

Bauteile:
Bauteile | Wert | Funktion | Info
C1,C2 | 22pF | Kondensator | siehe auch Quarz und C1 / C2
D1,D2 | LED | LowCurrent-LED
R1* | 1k (1000 Ω) | Widerstand siehe Unten | Anpassung an Eingangsspannung
R2,R3,R4 | 1k (1000 Ω) | Widerstand
R5,R6 | R100 (100 Ω) | Widerstand
U1 | PC827 | Optokoppler | Alternativ: 2 Stk. PC817
U2 | ATMega328 | Atmel µController | (Arduino - Kompatibel)
U3 | CMOS4093 | SchmittTrigger (NAND-Gatter)
Q1 | 10MHz | Quarz (HC49U) | Q-Lastkapazität: 30pF
J1 | 2-Pol Schraubklemme | Klemme | Lötbare Schraubklemme 5mm
J2 | Wannenstecker 6-Pol | ISP-Port für ISP-Programmer | WSL 6G gerade (2X3-Pol)
J3 * | Buchsenleiste 2X12 Pol | RaspberrPi Buchsenleiste | RaspPi Connector Pin 1-24
(U1) | IC-Sockel 8-polig | IC-Sockel für U1 | Empfohlenes Zubehör für U1
(U2) | IC-Sockel 28-polig | IC-Sockel für U2 | Empfohlenes Zubehör für U2
(U3) | IC-Sockel 14-polig | IC-Sockel für U3 | Empfohlenes Zubehör für U3
Trafo | 7 – 15 V AC ~ | Netzteil / Trafo
J4 | 4-Pol Schraubklemme | Klemme (2X2 Schraubklemme) | Bei USB-TTL-Verwendung
J5 | Stiftleiste 2X3-Pol | Jumper | Universelle Eingabe-Erweiterung
J6 | Stiftleiste 2X5Pol | Relais-OUT | Universelle Ausgabe-Erweiterung
*) bei der Anwendung für den RaspberryPi

Außerdem

- RaspberryPi 3 oder 4 oder USB-TTL-Konverter
- Abstandshalter für die Netzfrequenzplatine: M2,5 X 12mm, Female-Female + Schrauben 2,5mm X 5
- Gehäuse

*) Empfehlung / Berechnung Eingangswiederstand R1

R1 ≈

(U~) − ULed

ILed

=

UMess − 2V
10mA
Eingangsspannung (AC) | Empfohlene Größe: R1
5V ~ - 7V ~ | 470 Ω
7V ~ - 15V ~ | 1k Ω
15V ~ - 25V ~ | 1,5k Ω


Bei Verwendung mit USB (ohne RPi)

- USB zu TTL serieller UART-Wandler mit 5V (oder 3,3V)
Bild: USB-TTL-Konverter | Bild: Anschlussbeispiel USB-TTL-Konverter (ohne RPi)

Bild: Anschlussschema USB-TTL-Konverter

USB-TTL-Konverter

7-15 V AC ~ Netzfrequenz

Einbauhinweise:; U1 Optokoppler; Bild:; alternative Bestückung 2 Stk. PC817 statt 1 Stk. PC827; Einbaulage J2

Statt eines PC827 (U1) können auch zwei PC817 (U1a, U1b)
verwendet werden.

Die Bestückung muss dann erfolgen wie in auf dem Bild:

Einbaulage LED 1 und LED 2

Die Bestückung / Einbaulage der LEDs muss
wie im Bild rechts angegeben erfolgen.

Infos zum Quarz

Abstand des Quarz zur Platine

Beim Bestücken unbedingt Abstand zur Platine halten, um Kurzschlüsse zu vermeiden

Bild: Quarzabstand zur Platine

Bauteilinformation: Quarz und C1 / C2

10,0000-HC49U-S, Standardquarz im Gehäuse HC49/U-S.

- Frequenz: 10,0000 MHz
- Cl: 32 pF | ==> | C1 / C2 = 22pF | Lastkapazität im Datenblatt beachten!
- Rsmax: 50 Ohm
- Temperaturkoeffizient: ± 30 ppm
- Frequenztoleranz: ± 30 ppm

Gehäuseempfehlung

Die Netzfrequenz-Platine ist für den Einsatz in einem Hutschienengehäuse vorbereitet


Bild: Hutschienengehäuse für RaspberryPi 4 und RaspberryPi 3

### Software / Quellcode

Das Basisprogramm steht in der Arduino-IDE –Variante (C / C++) und als HEX-Code zum Download bereit:

Die Basisversion beinhaltet das einfache Grundprogramm der Netzfrequenzmessung und kann für eigene Projekte verwendet bzw. angepasst werden. Die Erweiterungen sind in Kürze erhältlich (ebenfalls unter den GNU GLP3 Lizenzen).

Wichtiger Hinweis zur Arduino-Kompatiblität:

Die Netzfrequenzplatine arbeitet mit 3,3V (RaspberryPi). Durch die 3,3V kann nur ein maximaler Quarz von 10MHz verwendet werden. Deshalb müssen einige Controller-Fuses umgestellt werden. Eine direkte Arduino-Programmierung über die serielle Schnittstelle ist deshalb in dieser Hardware-Version nicht möglich.

Ein 100% kompatibles Arduino-„Netzfrequenzboard“ (mit serieller Übertragung) ist in Vorbereitung.

µController-Fusebits

Die „System Clock“ und „Clock Otions“ - Fusebits des ATMega328 müssen folgende Einstellungen haben:

LOW Fuses = 0xFF | HIGH Fuses = 0xDA | EXTENDED Fuses = 0xFF

Die korrekten Fusebits können mit AVRDude oder Atmel AVR-Studio eingestellt und übertragen werden. Ohne die korrekte Einstellung läuft das Netzfrequenz-Programm mit 3,3V Betriebsspannung nicht.

Übertragung / Programmierung
Die Übertragung des Quellcodes kann über mehrere Wege erfolgen.

### Information: Aktualisierte Dokumentation zur Programmierung siehe Webseite

Programmierservice
Wer nicht selbst programmieren möchte, für den biete ich einen Programmierservice an.

ISP Port
(RaspberryPi)

ISP Port

Serial Port (USB/TTL)

Messung / Ausgabetest

Überprüfung der Funktion mit einem Terminalprogramm:

Öffnen sie ein Terminalprogramm z.B. PUTTY

Überprüfen Sie die Einstellungen der Serial-Schnittstelle

Serial Line: | /dev/ttyS0 (oder /dev/ttyAMA0)
Baud: 19200 Bd | Databits: 8 | Stopbits: 1 | Parity: NONE Flow Control: NONE

Das Terminalprogramm zeigt nach dem Öffnen den Datenfluss der Netzfrequenzmessung.


### Kommunikation der Netzfrequenzplatine

Das Konsolenprogramm mfmServerTool ermöglicht die Aufzeichnung und die Bereitstellung der Netzfrequenzmessdaten für leittechnische Anbindung z.B. OPC-Server.
Das Konsolenprogramm ist lauffähig auf Windows und Linux (RaspberryPi).

Die Daten können auf dem Web-Server des ioBrockers, dem OpenHAB (Open Home Automation Bus) oder dem OpenMUC (Web-Interface zur Systemkonfiguration und Visualisierung) problemlos visualisiert werden.

Details zur Projekterweiterung finden Sie auf der Webseite www.netzfrequenzanzeige.de. (https://pc-projekte.lima-city.de/netzfrequenzanzeige.html)


Bild: Schema Netzfrequenzmessung und Anbindung an eine Leittechnik

### Infos / Bestellmöglichkeit

- weitere Informationen unter www.netzfrequenzanzeige.de (https://pc-projekte.lima-city.de/nfa_rpi.html)
- Anfrage privater Verkauf Platinen und Wechselspannungsnetzteile (Restposten) pc_projekte.de@arcor.de
- Privater Programmierservice für µController
- | Link für aktuelle Bauteileliste (bei Reichelt) | https://www.reichelt.de/my/1689769

### Hinweis / Gewährleistungsausschluss

Projekthinweis: Das gesamte Projekt ist ein privates, nicht kommerzielles Projekt.

Der Autor übernimmt keinerlei Gewähr für Funktionalität der vorgestellten Hard- und Software. Haftungsansprüche gegen den Autor, welche sich auf Schäden materieller oder ideeller Art beziehen, sind grundsätzlich ausgeschlossen. Die Inhalte der Homepage, der Projektbeschreibung oder der Software werden ohne Anspruch auf Richtigkeit veröffentlicht. Alle Angaben sind ohne Gewähr. Die Verwendung der Texte, Grafiken, Bilder und Programme sind im Rahmen der zum Projekt gehörenden OpenSource-Lizenzen erlaubt. Der Autor behält es sich ausdrücklich vor, Teile der Seiten ohne gesonderte Ankündigung zu verändern, zu ergänzen oder zu löschen.

- Verwendung der Soft- und Hardware auf eigene Verantwortung
- Jegliche Produkthaftung durch die Verwendung der Soft- und Hardware wird ausgeschlossen

Haftungsausschluss nach §1 Abs.2 Z.3 ProdHaftG , (BGBl. I S. 1474 m.W.v. 08.09.2015 der Bundesrepublik Deutschland )

### Information zur Spannungsversorgung

Die Spannungsversorgung muss der Beschreibung entsprechen, da es sonst zu Zerstörung von Bauteilen kommen kann.

### Jens Müller, 04‘2020 www.pc-projekte.de

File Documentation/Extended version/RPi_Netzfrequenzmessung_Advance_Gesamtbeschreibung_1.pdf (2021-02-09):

# MAINS FREQUENCY MONITORING UNIT Netzfrequenzmessung- und Überwachung für den RaspberryPi (und USB-TTL) erweiterte Dokumentation

# (Extendend Version)

## Der Blick in unser Stromnetz


### Mueller, Jens, www.pc-projekte.de

pc_projekte.de@arcor.de


### Projektbeschreibung MAINS FREQUENCY MONITORING V2.0 Extended Version

Messen und beobachten Sie Ihre Netzfrequenz. Die Abweichung vom Sollwert stellt einen direkten Qualitätsindikator über die angebotene Momentanleistung der Kraftwerke und die Abnahme der Verbraucher dar. Die Netzfrequenz ist somit ein Garant der Netzstabilität und zeigt Effekte des Intraday- Stromhandels

09.02.2021

Inhaltsverzeichnis

## Lizenz

### Dokumentation

### Creative-Commons-Lizenz

Diese Projektdokumentation steht unter der Creative-Commons-Lizenz Namensnennung - Weitergabe unter gleichen Bedingungen 4.0 International. Um eine Kopie dieser Lizenz zu sehen, besuchen Sie http://creativecommons.org/licenses/by-sa/4.0/

### OpenHardware (OSHWA)

Die Hardware ist unter einer CERN-Lizenz veröffentlicht als OpenHardware (Open-Source-Hardware)

Das Projekt ist OSHWA- zertifiziert unter Nr. DE000086.

Gesamte Projektdokumentation und alle Lizenzen unter

https://gitlab.com/jm_wtal/mains-frequency-measure

Infos zu Oshwa: https://www.oshwa.org/definition/german

Software / Quellcode

Der Quellcode steht unter der GNU GPL 3-Lizenz:

- Freiheit das Programm für jeden Zweck auszuführen
- Freiheit den Quellcode zu studieren und anzupassen
- Freiheit, das Programm zu kopieren
- Freiheit, das veränderte Programm zu kopieren

Diese Freiheiten sollten auch langfristig sichergestellt werden. Zu diesem Zweck enthält die GPL zwei wesentliche Klauseln:

- Jedes Derivat muss ebenfalls vollständig unter der GPL lizenziert werden.
- Bei Weitergabe des Programmes in Binärform muss der Quellcode des gesamten Programms mitgeliefert oder auf Anfrage ausgehändigt werden.

### Hintergrund

Unser Stromnetz
Die Netzfrequenz in Europa beträgt 50Hz. Eine Abweichung vom Nennwert ist ein direktes Fenster der elektrischen Erzeugung und dem Verbrauch. Der abgegebenen Leistung muss zu jedem Zeitpunkt eine gleich große Leistungsaufnahme gegenüberstehen.

Kommt es zu Abweichungen, führt das zu einer Veränderung der Netzfrequenz: Bei einem Überangebot von elektrischer Leistung kommt es zu einer Steigerung der Netzfrequenz, bei einem Unterangebot zu einer Absenkung. Normalerweise sind diese Abweichungen im westeuropäischen Verbundnetz minimal und bewegen sich im Bereich von 49,80Hz - 50,20Hz. Die Aufgabe der so genannten Leistungsregelung im Stromnetz ist es, die Lastschwankungen auszugleichen und so die Netzfrequenz auf konstantem Nennwert zu halten.

In Europa, Asien, Australien, dem Großteil von Afrika und Teilen von Südamerika wird für das allgemeine Stromnetz, in sogenannten Verbundnetzen, eine Netzfrequenz von 50 Hz verwendet. In Nordamerika verwendet man im öffentlichen Stromnetz eine Netzfrequenz von 60 Hz. Die Unterschiede sind durch die historische Entwicklungsgeschichte der ersten Stromnetze in den 1880er und 1890er Jahren bedingt und haben heute keinen technischen Grund.

Einige Eisenbahnen wie die ÖBB, SBB und die Deutsche Bahn nutzen für ihre Bahnstromversorgung eine nominale Frequenz von 16,7 Hz. Früher betrug die nominale Bahnnetzfrequenz 16 ²
⁄3 Hz, was genau
einem Drittel der im Verbundnetz verwendeten 50 Hz entspricht. Einige Eisenbahnen und auch industrielle Abnehmer in Nordamerika werden aus historischen Gründen mit einer Netzfrequenz von 25 Hz versorgt. Die vergleichsweise niedrigen Netzfrequenzen resultieren aus der technologischen Entwicklung der ersten elektrischen Maschinen: Anfang des 20. Jahrhunderts konnte man elektrische Maschinen größerer Leistung nur mit diesen niedrigen Frequenzen bauen. Wegen des großen Umstellungsaufwandes werden jedoch die damals eingeführten niedrigen Netzfrequenzen auch noch heute beibehalten.

In speziellen Bereichen, z. B. im Bordnetz von Flugzeugen, sind höhere Netzfrequenzen üblich, z. B. 400 Hz, da sich dafür kleinere und leichtere Transformatoren bauen lassen und die Leitungslängen kurz sind.

### Netzfrequenz als Qualitätsindikator

Die Netzfrequenz und deren Abweichung vom Nennwert ist ein direkter Qualitätsindikator über die Relation der über Erzeuger wie Kraftwerke angebotenen elektrischen Momentanleistung und der Abnahme der elektrischen Momentanleistung durch Verbraucher. Elektrische Energie kann in Verbundnetzen kaum gespeichert, sondern nur zwischen Erzeuger und Verbraucher verteilt werden. Der abgegebenen Leistung muss, bis auf die Blindleistung bei Wechselstrom, zu jedem Zeitpunkt eine gleich große Leistungsaufnahme gegenüberstehen.

Kommt es zu Abweichungen, führt das in Wechselspannungsnetzen zu einer Veränderung der Netzfrequenz: Bei einem Überangebot von elektrischer Leistung kommt es zu einer Steigerung der Netzfrequenz, bei einem Unterangebot zu einer Absenkung. Im Normalfall sind diese Abweichungen im westeuropäischen Verbundnetz minimal und bewegen sich unter 0,2 Hz. Eine Frequenzabweichung von 0,2 Hz entspricht im europäischen Verbundsystem einer Leistungsdifferenz von ca. 3 GW. Diese 3 GW Leistungspuffer sind als Referenzausfall (dem Continental Europe Operation Handbook) als Richtwert vorgegeben und beschreibt den ungeplanten Ausfall von zwei größeren Kraftwerksblöcken im europäischen Verbundnetz RG-CE (vormals UCTE). Die Aufgabe der Leistungsregelung in Verbundnetzen ist es, die zeitlichen Schwankungen auszugleichen und so die Netzfrequenz auf konstantem Nennwert zu halten. Je kleiner ein Stromversorgungsnetz ist und je schlechter die Netzregelung funktioniert, desto stärkere Schwankungen treten bei der Netzfrequenz auf.

Unterangebot der Energie | Überangebot der Energie

Diese Schwankung kann man messen:

Ich möchte mit meinem Projekt die Dynamik des Stromnetzes sichtbar machen. Die Elektronik erfasst die Netzfrequenz und ermöglicht, abgeleitet über eine mathematische Funktion, die Anzeige der Netzlastdifferenz in MW (Megawatt). Diese Netzlastdifferenz entspricht der primären Regelleistung.

Bild: Netzfrequenzmessung (Beispiel grafische Auswertung mit Grafana®)

Es handelt sich um ein privates, nicht kommerzielles Projekt. Die Elektronik, µController- und Projektsoftware ist von mir entwickelt (siehe auch Creativ-Commons-Lizenz).

Platinen, Programmierservice und Bauteile siehe Bestellmöglichkeit.

Einsatz der Netzfrequenzplatine

Messplatine zur Aufzeichnung, Informations-, Meldungs-, Alarmierungs-und Beobachtungszwecken der Netzfrequenz.

Das Gerät kann flexibel an die Kenndaten eines Stromnetzes angepasst werden (z.B. 60Hz-Netz). Eine Berechnung und Ausgabe der Netzlastdifferenz (primäre Regelleistung) ist vorbereitet (ENTSO-E RG-CE).

Die Ausgabe erfolgt über die serielle Schnittstelle. Die Platine ist für den RaspberryPi konzipiert, kann aber alternativ auch problemlso mit einen USB-TTL-Wandler verwendet werden.

Außerdem sind Output-Ausgaben für Alarmierungs- und Meldesysteme vorbereitet.

Eine Bereitstellung der Messwerte über eine Modbus-TCP-Software steht in Kürze zur Verfügung, weitere Protokolle z.B. MQTT (IoT), WebAPI (Influx-DB), IEC60870-4-104 FW-Protokoll oder als Logic-Device einer IEC61850-Anlage sind geplant.

Bauteile (Info)

Es ist keine smd-Technik verwendet, um die Nachbaubarkeit so einfach wie möglich zu gestalten. Die entsprechenden Nachbauanleitungen und Bauteillisten sind ab Seite 34 zu finden (Bestellmöglichkeit der Platine und der Bauteile siehe Seite 44). Eine teilbestückte Platine mit SMD ist in Vorbereitung.

Software
(µController ATMEGA328p-16PU DIP-28 8-Bit 10 MHz (Arduino - Kompatibel)

Die aktuelle Software steht auf der Gitlab-Seite als Download bereit.

Weitere Infos unter www.pc-projekte.de bzw. http://www.netzfrequenzanzeige.de.

Messspannung

Warnung: Verwenden Sie NIEMALS direkte 230V Netzspannung zur Netzfrequenzmessung!

Messspannung: Netzteil (oder Trafo) mit Wechselspannungsausgang


Bild: | Beispiele für Klingeltrafos | Bild: | Steckernetzteil (AC-AC) | Bild: Printtrafo

Siehe auch Hinweis / Gewährleistungsausschluss.

### Frequenzmessung

Kurzbeschreibung Messablauf

Die Frequenzmessung erfolgt über eine Flankenauswertung des Wechselspannungssignals. Das Signal wird über zwei Optokoppler und einem RS-FlipFlop (4093-Nand-Gatter als RS-FlipFlop) dem µController zugeführt und mit dem 10MHz-Quarz-Takt und des Timer1 und Timer2 (als Counter) des µControllers ausgewertet.

Genauigkeit

Die Messgenauigkeit der Netzfrequenzmessung ist auch ohne Kalibrierung sehr hoch. Ausschlaggebend ist die Genauigkeit des Quarz Q1 (und die korrekte Größe C1 und C2 , abgestimmt auf den Q1 ). Der Messfehler der Frequenzmessung (ohne Kalibrierung oder Netzfrequenztrigger-Vorschaltplatine) liegt unter ± 1 mHz.

Eine Kalibrierung der Messung ist über eine Quellcode-Einstellung möglich.

Temperaturbereich

Die Netzfrequenzanzeige sollte bei Raumtemperatur verwendet werden. Direkte Sonneneinstrahlung auf das Gehäuse oder die Platine und die damit verbundene Temperatureinwirkung können das Messergebnis verfälschen.

Netzrückwirkungen

Die Netzfrequenzanzeige ist im Normalfall unempfindlich gegenüber in der EN50160 beschriebenen Netzrückwirkungen.

Sehr starke elektrische Impulse in der Umgebungen, ungewöhnlich hohe Oberwellenanteile oder Rundsteuersignale in der Messspannung (Netzrückwirkung) können das Messergebnis verfälschen.

Siehe auch Messdatenaufbereitung

Messbereichserkennung bei Programmstart
Beim Programmstart wird eine automatische Netzfrequenzerkennung durchgeführt.

Nach der erfolgreichen Erkennung werden die entsprechenden Grenzbereiche der erkannten Netzfrequenz in den Filterstufen verwendet.

Min/Max | 50Hz-Netz | 60Hz-Netz | 16,7 Hz*
Max f | 45 Hz | 55 Hz | 22 Hz
Min f | 55 Hz | 65 Hz | 12 Hz

*) 16,7 Hz-Bahnnetzfrequenz z.B. Deutschland, Österreich und Schweiz (Normalspur)

16,7 Hz-Messung ist grundsätzlich möglich, ist aber momentan nicht integriert

Durch die manuelle Einstellung kann die entsprechende Netzfrequenz vorgegeben werden

Automatische Erkennung | 50 Hz / 60 Hz (16,6 Hz) | FA = 0
50 Hz-Netz | 45,000 Hz – 55,000 Hz | FA = 50
60 Hz-Netz | 55,000 Hz – 65,000 Hz | FA = 60
Eine Version für 16,7 Hz ist vorbereitet | 12,000 Hz – 22,000 Hz | FA = 16

### Einstellungen für das Prescale-Messverfahren

Für das Messverfahren können einige Einstellungen vorgenommen werden, um Messdauer und Messperioden an den µController anzupassen bzw. zu optimieren.

Dazu können im µController-Programm einige Parameter einstellt oder geändert werden.

Grundeinstellungen im Arduino-Quellcode:

Einstellung | Voreinstellung (Empfehlung) | Funktion
Prescaler | 64 | Interner Teiler des µC-Taktes (ATMega328-Takt)
Messperiode | 18 | Maximale Periodenzählung (Flankenzähler bis nächste Frequenzberechnung)
Dividend | 2812500 | Konstanter Wert für Frequenzumrechnung (ergibt sich aus dem Prescaler und der Messperiode)
Sperr | 2400 | Sperrzeit nach erkannter Eingangsflanke zur Unterdrückung von Signalprellung
UBRR | 0X40 | Korrekturwert für serielle Schnittstelle (Anpassung der Baud-Rate an den 10MHz-Takt)
DiffMAX | 60 | Maximalwert der zulässigen Frequenzänderung (siehe Differenz-Komperator-Filter)
FA | 0 | Automatische oder manuelle Frequenzbereichseinstellung (Automatische Netzfrequenzerkennung bei Programmstart)
Calibration | 0 | Messwert-Kalibrierung, falls benötigt

Auf den nachfolgenden Seiten sind die Einstellungen detailliert beschrieben.


Tabelle: Übersicht optimierte Einstelldaten für die Netzfrequenzmessung

Einstellungen im Arduino-Programmcode (Basisquellcode):

// Basic-Settings / Grundeinstellungen

// ***************************************************************************************************

#define F_CPU 10000000

const word Prescaler = 64; | // Prescaler (0,8,64,256,1024)
const byte Messperiode = 18; | // Period
const unsigned long Dividend = 2812500; | // DIVIDEND Calculation constant
const word Sperr = 2400; | // Lock-Counts
const int UBRR = 0x40; | // Correction serial baud/clock
const int DiffMAX = 60; | // DifferenzMAX
byte FA = 0; | // Selection 0 = Auto, 50=50Hz, 60=60Hz
const short Calibration = 0; | // MeasureCalibration

// ***************************************************************************************************

Alle Programmeinstellungen sind in den Zeilen 10 – 80 im Arduino-Quellcode (Basiscode und Extenden Version) zu finden.

<== Empfohlene Einstellung Raspberry Pi

- | Quarz | 10MHz
- | Prescaler | 64
- | Period | 18
- | Dividend | 2812500
- | Lock-Counts | 2400
- | UBRR | 0x40
(Programmierung über ISP-Port)

### Messung der Netzfrequenz

Grundprinzip sind die Timer T1 und T2 (T2 als virtueller 16-Bit-Counter) des µControllers, die ohne weitere Verarbeitung mit dem Start des µControllers auf den festen Takt 10MHz DIV 64 eingestellt sind. Die Timer werden mit dieser Einstellung der Referenztakt, aus dem die Netzfrequenz nun abgeleitet wird. Die zeitliche Gesamtlänge eines durchlaufenden Timers (0… 65535) beträgt ca 360ms (bei 50Hz). Die dadurch optimierte Periodenanzahl der Netzfrequenzmessung (für 45 Hz) beträgt 18. Durch die alternierende Auswertung wird eine serielle Ausgabe der Netzfrequenz von ca. 180ms erreicht.

Berechnung der Netzfrequenz
Die Timer laufen im eingestellten Prescale-Verfahren mit dem (geteilten) Takt des µControllers als Counter.

Die Netzfrequenz wird über den Optokoppler und dem Schmitt-Trigger dem INT0 und INT1 des µController zugeführt. Ein erkanntes Triggerereignis führt zum internen Hochzählen des zugehörigen Periodenzählers.

Die Trigger-Sperrzeit (Sperr/ LockCounts 2400) verhindert dabei eine zu schnelle Mehrfachauswertung der Flanke (z.B. durch ein Störsignal).

Ist der maximale Periodenzählwert erreicht, erfolgt die Übernahme des Zählwerts aus Timer1 oder Timer2 (T2 als virtueller 16Bit-Counter)

Der Counterwert der Timer wird als Divisor mit dem konstanten Dividend (2812500) die Berechnungsgrundlage für die Netzfrequenz. Zusätzlich wird noch der Faktor 1000 multipliziert. Die Ausgabe der Netzfrequenz erfolgt dann in mHz. Das hat den Vorteil, dass sämtliche Netzfrequenzberechnungen bis zu diesem Zeitpunkt ausschließlich in Festkomma-Arithmetik ausgeführt werden. Dieser Vorgang wird daher im µC sehr schnell ausgeführt (dadurch ist das Grundprogramm sogar lauffähig auf einem ATTiny).

Berechnung:

fMess (Variablenbezeichnung im Quellcode) in mHz (Bsp. 50021 = 50,021 Hz)

Der vorläufige Frequenzmesswert fMess (MessA / MessB) wird nun über einige Filterstufen geführt.

Die Ausgabe (Frequenz) erfolgt als serielles Protokoll auf dem TxD-Port des µControllers als alternierende Ausgabe der Ergebnisse T1 und T2.

UBRR (Anpassung an 10MHz)

Um die 19200Bd-Ausgabe der seriellen Schnittstelle auf den 10MHz-Quarz anzupassen, muss über die Eingabe der UBRR-Registerwert angepasst werden.

Für einen 10MHz-Quarz muss UBRR = 0x40 eingestellt werden.

### Detaillierte Beschreibung der Messung

### Eingangsbeschaltung Schmitt-Trigger

Die Eingangsbeschaltung (Netzfrequenz-Messeingang) ist über 2 Optokoppler galvanisch getrennt. Die Messspannung wird über ein Trafo zugeführt und sollte zwischen 7V- 15 V ~ AC liegen. Der Strom der verwendeten Messspannung beträgt nicht mehr als 20mA. Zur Messung sollte ein kurzschlussfester Trafo oder ein Klingeltrafo verwendet werden. Die Eingangsbeschaltung der Optokoppler U1 (U1a/U1b) wird durch R1 strombegrenzt (siehe auch Informationen Bauteile Seite 34).

Die Optokoppler steuern über ein NAND-Gatter aufgebauten Schmitt-Trigger an (CMOS 4093, IC U3), der dann das Messsignal als Rechtecksignal dem INT0- und INT1- Eingang des µControllers weiterleitet.

Netzfrequenz; zum INT0 / INT1 (µController); FlipFlop-Trigger (RS-FF)

Bild: Schematische Darstellung der Flankenauswertung (Schmitt-Trigger)

Vorteil dieser Messdatenaufbereitung ist, dass auch ein sehr verrauschtes Eingangssignal sicher erfasst wird.


Bild: Schematische Darstellung eines verrauschtes Eingangssignal und mit Ausgangssignal (hinter dem Schmitt-Trigger)


Schematischer Programmablauf Messauswertung

Arduino-Programm Ablauf (extended Version)

Auswertung mit dem µController INT0 und INT1

Flankenerkennung und Triggersignal-Sperre eines Timers:

Erkennt der µController eine Flanke, wird sofort eine Sperrzeit (ca. 15ms) gestartet, um nachfolgende Messspitzen zu unterdrücken. Eine mögliche zu frühe Flanke wird durch die nachfolgende Stufe sofort kompensiert, da nun eine Mittelwertbildung folgt.

Trigger-Sperrzeit

Bild: Schematische Darstellung der Trigger-Sperrzeit (T1)

Sperrzeit / Lock-Counts

Die Sperrzeit nach einem Impuls ist so gewählt, dass das nächste Triggersignal nur mit einer Frequenz unter 65 Hz passen würde.

Counter T2 als virtueller 16Bit-Counter

Der Counter T2 des ATMega328p ist ein 8-Bit-Counter. Über eine erweiterte Zählfunktion, bei dem die Überlaufereignisse des Counters T2 gezählt und in einem virtuellen T2-Zählerspeicher addiert werden, steht ein weiterer 16Bit-Counter zur Verfügung.

Bild: Schematische Darstellung „virtueller 16-Bit-Counter T2“

Auswertung der Messcounts T1 und T2 (virtuell)


Plausibilitätsfilter

Bevor der gemessene Netzfrequenzwert weiterverarbeitet wird, durchläuft der vorläufige neue Messwert noch eine zweistufige Prüfung: Dabei wird festgestellt, ob der gemessene Netzfrequenzwert grundsätzlich im zulässigen Bereich liegt:

Messung | 50 Hz-Messung | 60Hz-Messung | 16,7 Hz*
Prüfung f> | f > 45 Hz | f > 55 Hz | 22 Hz
Prüfung f< | f < 55 Hz | f < 65 Hz | 12 Hz

Nach dieser ersten Überprüfung, der unplausible Messwerte ausschließt, geht es weiter zum Differenz-Filter

Differenz-Komparator-Filter
Funktionsweise des Differenz-Komparator-Filters:

Der Differenz-Komparator-Filter verwendet prinzipiell die Vorgabe der maximalen Netzgradiente. Eine Netzfrequenzänderung über der maximalen Netzgradiente wird nur bedingt berücksichtig.
Sollten aber zwei aufeinanderfolgende Messungen an der Gültigkeitsprüfung auflaufen, wird auch eine sehr schnelle Änderung sofort übernommen. Die Voreinstellung DiffMAX (100mHz/s) ist zugleich auch die maximale Frequenzausgabeänderung.
Beim letzten großen Frequenzeinbruch am 8.1.2021 lag die Frequenzänderung von 50,020 Hz auf 49.739 Hz innerhalb 13s bei ca. 22mHz/s.

Ablauf: Der vorläufige (neue) Messwert wird mit dem letzten gültigen Messwert verglichen.
Durch die Differenzbildung der beiden Messwerte wird die Differenzgröße ermittelt.

Diff = ABS (fpreliminary − fMess )

Ist die Differenz (Absolutwert) kleiner der Voreinstellung DiffMAX, wird der neue Wert (Preliminary Value) zum gültigen Messwert fMess.

Ist die Differenz größer, wird der aktuelle Messwert fMess in Höhe der Voreinstellung DiffMAX dem neue Wert (Preliminary Value) nachgeführt.

preliminary value; current value

Bild: schematische Darstellung Verlauf Messdaten Differenz-Komparator-Filter

Die Netzgradiente hängt von vielen Netz-Schaltungszuständen, Einspeisungen, Netzlastsituationen und des Messortes ab. Deshalb ist der DiffMAX-Wert vom 100mHz/s eine Einstellungsempfehlung für das RG-CE (UCTE)-Netz.

Die Voreinstellung des DiffMAX-Filters beträgt 100mHz/s (Empfehlung).

Programm Diff-Filter (Arduino-Programm)

word Diff_filter(word filter_wert) | // Messdaten in mHz im WORD-Format
{
int Diff = filter_wert – Cachewert;
if ( abs(Diff) > DiffMAX ) | // bei Überschreitung DiffMAX
{
if ( Diff > 0) filter_wert = Cachewert + DiffMAX; | // Änderung (positive Steigung) max
if ( Diff < 0) filter_wert = Cachewert – DiffMAX; | // Änderung (negative Steigung) max
}
Cachewert = (int)filter_wert;
return filter_wert;
}

Kalibrierung

Normalerweise braucht die Netzfrequenzplatine keine Kalibrierung.

Sollte aber eine Kalibrierung doch erforderlich sein, kann in der Einstellung ein Kalibrierungswert beigefügt werden. In Kürze können verschiedene Einstellungen ein Softwaretool (über eine EEP-Datei) geänderte Einstellung ins EEProm des ATMega328 übertragen werden. Nach einen Neustart werden die geänderten Einstellungen verwendet.

### Frequenz + Calibration → Ausgabe zur seriellen Schnittstelle

Einstrellung serielle Schnittstelle

Einstellung der seriellen Schnittstelle

Baudrate: 19200 Baud | Parity: None | Stoppbit: 1 | Handshake: None

UBRR = 0x40

Um die Ausgabe der seriellen Schnittstelle auf den 10MHz-Quarz anzupassen, muss über die Eingabe der UBRR-Registerwert angepasst werden. Für einen 10MHz-Quarz muss UBRR = 0x40 eingestellt werden.


### Netzfrequenzmessung Extended-Version

Alternierende Messdatenausgabe A- und B-Messung
Die Ausgabe der Messdaten der A- und B-Messung erfolgt alternierend. Während die A-Messung die Berechnung und Ausgabe ausführt, misst die B-Messung bereits im Hintergrund den nächsten Messwert.

Beide Messungen kontrollieren sich gegenseitig und überwachen somit die messfehlerfreie Ausgabe. Zu große Abweichungen im Messdatenvergleich A-Messung/B-Messung blockiert die Ausgabe zur weiteren Verarbeitung.

Erweiterte Einstellungen im Arduino-Quellcode

Einstellung | Variable (Name) | Voreinstellung (Empfehlung) | Funktion
Kennlinientyp | Typ | 1 | Auswahl Kennlinientyp für die Ausgabe der Netzlastdifferenz
Netzlastdifferenz λ | Lamda | 15,333 | Steigung Netzlastdiffernz-Kennlinie
Offset (in mHz) | Offset | 10 (±) | Offset Netzlastdifferenz-Kennlinie
Negierung Kennlinie | Neg | false | Vorzeichennegierung Ausgabe Netzlastdifferenz
f1 > (in mHz) | f1g | 50100 | Frequenzalarm 1 (=> 50,100 Hz)
f1 < (in mHz) | f1k | 49900 | Frequenzalarm 1 (=> 49,900 Hz)
f1 Haltezeit nach Rückfall (in s) | tf1 | 10 | Haltezeit Alarmausgabe nach Anrege-Rückfall Alarm f1
f2 > (in mHz) | f2g | 50200 | Frequenzalarm 2
f2 < (in mHz) | f2k | 49800 | Frequenzalarm 2
f2 Haltezeit nach Rückfall (in s) | tf2 | 10 | Haltezeit Alarmausgabe nach Anrege-Rückfall Alarm f2
f3 > (in mHz) | f3g | 51000 | Frequenzalarm 3
f3 < (in mHz) | f3k | 49000 | Frequenzalarm 3
f3 Haltezeit nach Rückfall (in s) | tf3 | 10 | Haltezeit Alarmausgabe nach Anrege-Rückfall Alarm f3
f4 > (in mHz) | f4g | 52000 | Frequenzalarm 4
f4 < (in mHz) | f4k | 48000 | Frequenzalarm 4
f4 Haltezeit nach Rückfall (in s) | tf4 | 10 | Haltezeit Alarmausgabe nach Anrege-Rückfall Alarm f4
LowAktiv | LowAktiv | true | Änderungsmöglichkeit für eine HighAkive Meldungsausgabe (Binärausgabe J6)
BlinkON | BlinkON | false | Ausgangssignale J6 werden als Blinksignale ausgeführt (z.B. für eine Warnmeldung /Warnlampe usw.)

Auf den nachfolgenden Seiten sind die Einstellungen detailliert beschrieben.

Ausgabe der Netzlastdifferenz

MW-Funktion
Funktionsgleichung MW / mHz mit oder

Unempfindlichkeitsbereich (Offset)

Die Funktion entspricht einer linearen Gleichung, allerdings mit einem Unempfindlichkeitsbereich (Offset / Totbereich), der ebenfalls eingestellt werden kann. Zur besseren Übersicht und Einstellung ist die Kennlinie als Grafik sichtbar.

Kennlinientyp

Die Voreinstellung ist Kennlinientyp 1, λ = 15,333 (Europa)

### 1. Unempfindlichkeitsbereich I / offset range I:

Die lineare Funktion startet außerhalb des Unempfindlichkeitsbereichs (Tot-Bereich) und verläuft parallel zur

λ =

Δ P(MW)
Δf (mHz) ± Offset(mHz)

### in Vorbereitung, noch nicht integriert:

### 2. Unempfindlichkeitsbereich II / offset range II:

Die lineare Funktion startet außerhalb des Unempfindlichkeitsbereichs (Tot-Bereich)

λ =

Δ P(MW)
Δf (mHz) ± Offset(mHz)

(frequency offset / sensitivity range or step behave).


### 3. Rampenfunktion / step behave:

Die Lineare Funktion enthält eine Rampe. Der Offset-Bereich wird nicht zur Berechnung verwendet.

λ =

ΔP (MW)
Δf(mHz)

, Rampe im Offset-Bereich

Kennlinieninvertierung / Invert characteristic

Bei der Aktivierung wird die Leistungskennlinie invertiert, auf der Anzeige wird das Vorzeichen invertiert. Leistungen unter 50 Hz werden negativ dargestellt, über 50Hz positiv.


Diese Art der Darstellung zeigt die Erzeugersicht bzw. die Anforderung an die Erzeugung.

- | Kennlinientyp | 1 | Auswahl Kennlinientyp für die Ausgabe der Netzlastdifferenz
- | Netzlastdifferenz λ | 15,333 Steigung Netzlastdiffernz-Kennlinie
- | Offset (in mHz) ± | 10 | Offset Netzlastdifferenz-Kennlinie
- | Negierung Kennlinie | false | Vorzeichennegierung Ausgabe Netzlastdifferenz

Einstellungen im Arduino-Programm:

// | mains load differenz / Netzlastdifferenz

byte Typ = 1;

float Lamda = 15.33333333;

float Offset = 10;

bool Neg = false;

Tabelle Warnstufen Netzfrequenz

Reaktionen / Meldungen: Netzfrequenz (UCTE Continental Europe, 50Hz)

Hz

55,00 | x
52,00 | | x
51,00 | | | x
50,20 | | | | x
50,10 | | | | | x
50,02 | | | | | | x
50,00 | | | | | | | x
49,98 | | | | | | | | x
49,90 | | | | | | | | | x
49,80 | | | | | | | | | | x
49,00 | | | | | | | | | | | x
48,00 | | | | | | | | | | | | x
45,00 | | | | | | | | | | | | | x

Messbereichsende Netzfrequenzanzeige

Stabilitätsgrenze überschritten

Warnmel

dung Netzfrequenzanzeige Stufe 3

Warnmel

dung Netzfrequenzanzeige Stufe 2

Warnmel

dung Netzfrequenzanzeige Stufe 1

Beginn Einspeiseabwurf EEG

positive primäre Regelleistung (Netzsicht)

Nennfrequenz

negative primäre Regelleistung (Netzsicht)

Warnmel

dung Netzfrequenzanzeige Stufe 1
Warnmeldung Stromnetze (ÜNBs / VNBs)

Warnmel

dung Netzfrequenzanzeige Stufe 2
Lastabwurf nach Frequenzabwurfplan
Stabilitätsgrenze unterschritten

Warnmel

dung Netzfrequenzanzeige Stufe 3
Messbereichsende Netzfrequenzanzeige
Alarmausgabe Netzfrequenzmessung

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
Einstellung Frequenzmeldungen

Alarm | Einstellung *) | Alarm-Byte | Relaisausgabe
f1 > | 50,100 Hz | Bit 0 | Relais 1
f1 < | 49,900 Hz
f2 > | 50,200 Hz | Bit 1 | Relais 2
f2 < | 49,800 Hz
f3 > | 51,000 Hz | Bit 2 | Relais 3
f3 < | 49,000 Hz
f4 > | 52,000 Hz | Bit 3 | Relais 4
f4 < | 48,000 Hz
Res. | Vorbereitet für Alarm Netzfrequenzsprung | Bit 4
Res. | Vorbereitet für Alarm Netzfrequenzpendelung | Bit 5
Res. | | Bit 6
Sammelalarm | Sammelalarm (alle Meldungen) | Bit 7 | Relais 5
// Alert mains frequency / Frequenzalarme | *)
word f1g = 50020; | // fmax Alert
word f1k = 49980; | // fmin Alter
word tf1 = 10; | // Alert RelapseTime
…

Alarmausgabe im Protokoll

Byte | Sammelalarm | Res. | Res. | Res. | Alarm f4 | Alarm f3 | Alarm f2 | Alarm f1
| Bit 7 | Bit 6 | Bit 5 | Bit 4 | Bit 3 | Bit 2 | Bit 1 | Bit 0
Wert | 2^7 = 128 | 64 | 32 | 16 | 8 | 4 | 2 | 1
0 | - | | - | | - | - | - | -
129 | X | | | | | | | X
147 | X | | | X | | | X | X
135 | X | | | | | X | X | X
143 | X | | | | X | X | X | X
161 | X | | X | | | | | X
Tabelle: Berechnungsbeispiele für Alarmmeldungen

*) 60 Hz Trigger :

Die Anpassungen der Trigger-Einstellungen für 60Hz-Netze erfolgt im Unterprogramm „Settings_60Hz()“.

Alarmausgabe J6

J6 vorbereitet als universelle Ausgabe-Schnittstelle (Low-Aktiv, z.B. Relaisausgabe)

Einsatz als Melde/Alarmierungssystem
Die Ausgabe sollte ausschließlich zu Meldungs- oder Alarmierungszwecken dienen. Netzschutzfunktionalitäten (z.B. Unterfrequenzabwurf) sollte nicht über die Netzfrequenzmessung ausgeführt werden.

Funktion der Schnittstelle J6:

Ausgänge:

SP1 als Ausgang.

Im Einstellprogramm sind die Alarmausgänge aktiviert. Alarme werden als Binärinformation an den Ausgängen bereitgestellt. Angeschlossene Relais, LED’s oder Optokoppler können die Alarme an Meldesysteme übergeben.

f <> Alarmausgabe mit Rückfallverhalten (J6 und Protokoll)


Skizze: Beispielhafte Alarmausgabe mit Rückfallverhalten

Die Haltezeit (das Rückfallverhalten) verhindert ein „Meldungsflattern“ im Anregebereich z.B. bei angeschlossenen Relais.

J6 Ausgabeverhalten
Ausgabe High/Low-Aktiv
Die Voreinstellung LowAktiv = false negiert die Ausgabe, die Pins sind dann im Alarmzustand HighAktiv;

Blinkende Ausgabe
BlinkON = true erzeugt bei einer aktiven Meldung ein Blinksignal am Ausgangsport JP1 (für alle Ausgänge)

//Alert Output // Alarmausgaben

bool LowAktiv = true; // Output Alarmausgabe LowAktiv

bool BlinkON = true; // Blinkende Ausgabe z. B. LEDs

Alarm | J6 | Pin
f1 | Rel1 Pin14 (Port PB.0) | 2 | 1 | GND
f2 | Rel2 Pin13 (Port PD.7) | 4 | 3 | GND
f3 | Rel3 Pin23 (Port PC.0) | 6 | 5 | GND
f4 | Rel4 Pin15 (Port PB.1) | 8 | 7 | GND
SA | Rel5 Pin16 (Port PB.2) | 10 | 9 | GND


Ausgang mit LED-Beschaltung

Beispiel für den Anschluss von LowCurrent-LED’s an der Schnittstelle J6

Die Ausgabe der LED‘s in diesem Beispiel erfolgt LOW-Aktiv.

- „0“ => 0V Meldung Aktiv,
- „1“ => 5V Meldung nicht Aktiv

Beispiel: Ausgang mit Relais-Beschaltung

Die Ausgabe der Relais in diesem Beispiel erfolgt LOW-Aktiv (Voreinstellung).

- „0“ | => 0V Meldung Aktiv,
- „1“ | => 5V Meldung nicht Aktiv

Hinweis:

Ich empfehle, eine angeschlossene Relaisplatine über eine externe Stromversorgung zu versorgen.

RPi / USB

Relais Output

LEDs

LED 1: RUN-LED

LED1 (RUN) Zustandswechsel (toggle) bei jedem erfolgreichen Filterdurchlauf.

(toggle= wechselt den binären Zustand)

Arduino-Ausgabe : 4 (=Pin6, PD4)

LED 2: RPi-Led

Die LED 2 kann durch ein Programm auf dem RaspberryPi angesteuert werden.

RaspberryPi Ausgabe : GPIO5 (=Pin12)

### Verwendung mit einem USB-TTL-Konverter

Die Netzfrequenzplatine kann auch ohne einem RaspberryPi zur Netzfrequenzmessung verwendet werden. Die Datenausgabe und die Stromversorgung ist dann über die die USB-Schnittstelle (USB-TTL-Konverter) realisiert.

Für diese Betriebsart ist der Anschluss J4 vorbereitet.

JP4: | Dieser Port stellt das serielle Telegramm bereit (Details siehe „serielles Protokoll“)
Pin | Bezeichnung | Funktion | Hinweis
1 | GND | Masse / GND
2 | RxD | Empfangsrichtung (zur USB), TTL-Pegel* | Vom µC (TxD)
3 | TxD | Empfangsrichtung (von USB), TTL-Pegel* | Zum µC (RxD)
4 | +5V | Versorgungsspannung 5V DC

*) siehe TTL-Pegel

Auswahl der Protokolle

J5.1 und J5.2 vorbereitet für Protokollauswahl (serielle Schnittstelle)

Für die Protokollverarbeitung stehen in kürze einige Beispielprogramme bereit.

Protokoll | Frequenz | Netzlastdifferenz* | Alarm* f <> | Hardware | Netzfrequenz-Server-Tool*
1 : 7-Byte | Ja | Nein | Nein | RPi | Ja
2 : 17-Byte | Ja | Ja | Ja | RPi | Ja
3 : 24-Byte | Ja | Ja | Ja | RPi + NFA | Ja
4 : 29.Byte | Ja | Ja | Ja | RPi | Nein

*) Eine softwareseite Auswertung der Netzlastdifferenz, der Frequenzalarme und der Netzpendelerkennung ist mit dem gewählten Netzfrequenz-Protokoll auch auf dem Modbus/MQTT-Server möglich.

Basisprotokoll 7-Byte-Protokoll (5+2)

Protokollauswahl 1

Jumperstellung J5 :

Protokoll

Bild: Aufbau und Telegrammverlauf 6-Byte-Protokoll

(Byte 6 und 7 sind ASCII- bzw. C0-Steuerzeichen: \n = LineFeed \r = Carriage Return)

Aus Ausgabe des Basisprotokolls auf der seriellen Schnittstelle erfolgt in mHz.

Protokoll 17-Byte-Protokoll

Protokollauswahl 2

Jumperstellung J5:

Protokoll

Byte
1 | 2 | 3 | 4 | 5 | 6 | 7 | 8 | 9 | 10 | 11 | 12 | 13 | 14 | 15 | 16 | 17
5 | 0 | 0 | 0 | 0 | ; | ± | 9 | 9 | 9 | 9 | ; | 2 | 5 | 5 | \r | \n
f (mHz) | MW | Alarm
Bild: | Aufbau und Telegrammverlauf 17-Byte-Protokoll

Byte 7 :

f < 50000 mHz | f = 50000 mHz | f > 50000 mHz
Byte 7 = „-“ | Byte 7 = „0“ | Byte 7 = „+“

(Byte 16 und 17 sind ASCII- bzw. C0-Steuerzeichen: \n = LineFeed \r = Carriage Return)

Das 17-Byte-Protokoll benötigt die Angabe des Netzlastkoeffizienten, Energierichtung (Kennlinieninvertierung), Ptot und der Grenzwerte der Alarmierungsfunktion.

Das Protokoll ermöglicht die einfache Weiterverarbeitung (z.B. mit einem Zeitstempel) zur Speicherung in eine CSV-Datei und späteren Auswertung z.B. mit Excel.

Protokoll 24-Byte-Protokoll

Protokollauswahl 3

Jumperstellung J5:

Protokoll

Byte
1 | 2 | 3 | 4 | 5 | 6 | 7 | 8 | 9 | 10 | 11 | 12 | 13 | 14 | 15 | 16 | 17 | 18 | 19 | 20 | 21 | 22 | 23 | 24
N | F | A | 5 | 0 | 0 | 0 | 0 | f | ± | 9 | 9 | 9 | 9 | P | 2 | 5 | 5 | M | 2 | 5 | C | \r | \n
Header | Hz | f | ± MW | P | Alarm | M | Parity | C | \r | \n
| Parity Prüfsummenberechnung | | | | | | Partity
1 | 2 | 3 | 4 | 5 | 6 | 7 | 8 | 9 | 10 | 11 | 12 | 13 | 14 | 15 | 16
Bild: | Aufbau und Telegrammverlauf 24-Byte-Protokoll

Byte 10 :

f < 50000 mHz | f = 50000 mHz | f > 50000 mHz
Byte 10 = „-“ | Byte 10 = „0“ | Byte 10 = „+“

(Byte 23 und 24 sind ASCII- bzw. C0-Steuerzeichen: \n = LineFeed \r = Carriage Return)

Das 24-Byte-Protokoll benötigt die Angabe des Netzlastkoeffizienten, Energierichtung (Kennlinieninvertierung), Ptot und der Grenzwerte der Alarmierungsfunktion.

LED- 7-Seg Netzfrequenzanzeige V4

Das 24-Byte-Protokoll wird auch von der Netzfrequenzanzeige V4 Ausgabe unterstützt.

Protokoll 29-Byte-Protokoll

Protokollauswahl 4

Jumperstellung J5:

Protokoll

Byte 7 :

f < 50000 mHz | f = 50000 mHz | f > 50000 mHz
Byte 10 = „-“ | Byte 10 = „0“ | Byte 10 = „+“
f1 = Frequenzalarm 1 | (Zusätzlich auch Ausgabe Bin/Rel. 1)
f2 = Frequenzalarm 2 | (Zusätzlich auch Ausgabe Bin/Rel. 2)
f3 = Frequenzalarm 3 | (Zusätzlich auch Ausgabe Bin/Rel. 3)

f4 = Frequenzalarm 4

FS = Frequenzsprung (vorbereitet)

PA = Pendelalarm (vorbereitet)

SA = Sammelalarm

(Byte 28 und 29 sind ASCII- bzw. C0-Steuerzeichen: \n = LineFeed \r = Carriage Return)

Die Ausgabe der Alarmmeldungen im Protokoll erfolgt „High-Aktiv“

=> „1“ = Alarm aktiv, „0“ = kein Alarm

Dieses Protokoll ist für eine Aufzeichnung der Messdaten z.B. durch ein Terminalprogramm vorgesehen. Die Auswertung ist als CSV-Datei möglich.

HINWEIS: Zur weiteren genauen Verarbeitung muss ein zusätzlicher Zeitstempel eingefügt werden.

## Nachbau


DIL-Version V1.0

Bild: Platine Netzfrequenzmessung mfm V1.0 RaspPi

Eingang: Int0, Int1 = A/B-Messung


Schaltbild Netzfrequenzplatine mfm V1.0

### Aufbauskizze

Bild: Aufbau Bauteile

Foto: bestückte Platine auf dem RaspberryPi mit angeschlossenem ISP-Programmer


Platinen-Layout

Bild: | Platinenlayout Rückseite | Bild: | Platinenlayout Vorderseite

Bauteile:
Bauteile | Wert | Funktion | Info
C1,C2 | 22pF | Kondensator | siehe auch Quarz und C1 / C2
D1,D2 | LED | LowCurrent-LED
R1* | 1k (1000 Ω) | Widerstand siehe Unten | Anpassung an Eingangsspannung
R2,R3,R4 | 1k (1000 Ω) | Widerstand
R5,R6 | R100 (100 Ω) | Widerstand
U1 | PC827 | Optokoppler | Alternativ: 2 Stk. PC817
U2 | ATMega328P | Atmel µController | (Arduino - Kompatibel)
U3 | CMOS4093 | SchmittTrigger (NAND-Gatter)
Q1 | 10MHz | Quarz (HC49U) | Q-Lastkapazität: 30pF
J1 | 2-Pol Schraubklemme | Klemme | Lötbare Schraubklemme 5mm
J2 | Wannenstecker 6-Pol | ISP-Port für ISP-Programmer | WSL 6G gerade (2X3-Pol)
J3 * | Buchsenleiste 2X40 Pol | RaspberrPi Buchsenleiste | RaspPi Connector Pin 1-40
(U1) | IC-Sockel 8-polig | IC-Sockel für U1 | Empfohlenes Zubehör für U1
(U2) | IC-Sockel 28-polig | IC-Sockel für U2 | Empfohlenes Zubehör für U2
(U3) | IC-Sockel 14-polig | IC-Sockel für U3 | Empfohlenes Zubehör für U3
Trafo | 7 – 15 V AC ~ | Netzteil / Trafo | Messsignal-Trafo
J4 | 4-Pol Schraubklemme | Klemme (2X2 Schraubklemme) | Bei USB-TTL-Verwendung
J5 | Stiftleiste 2X3-Pol | Jumper | Universelle Eingabe-Erweiterung
J5.1, J5.2 | Jumper | Jumper (Kurzschlussbrücke) | Für die Auswahl Protokollausgabe
J6 | Stiftleiste 2X5Pol | Relais-OUT | Universelle Ausgabe-Erweiterung
*) bei der Anwendung für den RaspberryPi

Außerdem

- RaspberryPi 3 oder 4 oder USB-TTL-Konverter
- Abstandshalter für die Netzfrequenzplatine: M2,5 X 12mm, Female-Female + Schrauben 2,5mm X 5
- Gehäuse

*) Empfehlung / Berechnung Eingangswiederstand R1

R1 ≈

(U~) − ULed

ILed

=

UMess − 2V
10mA
Eingangsspannung (AC) | Empfohlene Größe: R1
5V ~ - 7V ~ | 470 Ω
7V ~ - 15V ~ | 1k Ω
15V ~ - 25V ~ | 1,5k Ω


Bei Verwendung mit USB (ohne RPi)

- USB zu TTL serieller UART-Wandler mit 5V (oder 3,3V)
Bild: USB-TTL-Konverter | Bild: Anschlussbeispiel USB-TTL-Konverter (ohne RPi)

Bild: Anschlussschema USB-TTL-Konverter

USB-TTL-Konverter

7-15 V AC ~ Netzfrequenz

Einbauhinweise:; U1 Optokoppler; Bild:; alternative Bestückung 2 Stk. PC817 statt 1 Stk. PC827; Einbaulage J2

Statt eines PC827 (U1) können auch zwei PC817 (U1a, U1b)
verwendet werden.

Die Bestückung muss dann erfolgen wie in auf dem Bild:

Einbaulage LED 1 und LED 2

Die Bestückung / Einbaulage der LEDs muss
wie im Bild rechts angegeben erfolgen.

Infos zum Quarz

Abstand des Quarz zur Platine

Beim Bestücken unbedingt Abstand zur Platine halten, um Kurzschlüsse zu vermeiden

Bild: Quarzabstand zur Platine

Bauteilinformation: Quarz und C1 / C2

10,0000-HC49U-S, Standardquarz im Gehäuse HC49/U-S.

- Frequenz: 10,0000 MHz
- Cl: 32 pF | ==> | C1 / C2 = 22pF | Lastkapazität im Datenblatt beachten!
- Rsmax: 50 Ohm
- Temperaturkoeffizient: ± 30 ppm
- Frequenztoleranz: ± 30 ppm

Gehäuseempfehlung

Die Netzfrequenz-Platine ist für den Einsatz in einem Hutschienengehäuse vorbereitet


Bild: Hutschienengehäuse für RaspberryPi 4 und RaspberryPi 3

### Software / Quellcode

Das Basisprogramm und die extended-Version stehen in der Arduino-IDE –Variante (C / C++) und als HEX-Code zum Download bereit:

Wichtiger Hinweis zur Arduino-Kompatiblität:

Die Netzfrequenzplatine V1.0 arbeitet mit 3,3V (RaspberryPi). Durch die 3,3V kann der ATMega328p nur ein maximaler Quarz von 10MHz verwenden. Deshalb müssen einige Controller-Fuses umgestellt werden. Eine direkte Arduino-Programmierung über die serielle Schnittstelle (USB) ist deshalb in dieser Hardware-Version nicht möglich. Eine Programmierung des ATMega328p ist über den vorbereiteten ISP-Port oder über den RaspberryPi (ISP-Schnittstelle) möglich.

Ein 100% kompatibles Arduino-„Netzfrequenzboard“ (mit serieller Übertragung) ist in Vorbereitung.

µController-Fusebits

Die „System Clock“ und „Clock Otions“ - Fusebits des ATMega328 müssen folgende Einstellungen haben:

LOW Fuses = 0xFF | HIGH Fuses = 0xDA | EXTENDED Fuses = 0xFF

Die korrekten Fusebits können mit AVRDude oder Atmel AVR-Studio eingestellt und übertragen werden. Ohne die korrekte Einstellung läuft das Netzfrequenz-Programm mit 3,3V Betreibspannung nicht.

Übertragung / Programmierung
Die Übertragung des Quellcodes kann über mehrere Wege erfolgen. Ich beschreibe auf der nächsten Seite eine beispielhafte Möglichkeit. Weitere Programmiermöglichkeiten siehe Projektseite.

Programmierservice
Wer nicht selbst programmieren möchte, für den biete ich einen Programmierservice an.

ISP (SPI) Port
(RaspberryPi)

ISP Port

Serial Port (USB/TTL)

Arduino Quellcode compilieren

Das aktuelle oder geänderte Arduino-Projekt (Quellcode) kann einfach als Hex-Datei kompiliert werden.

Im Arduino-Projektordner stehen nun (nach der fehlerfreien Comilierung) zwei kompilierte Hex-Files zur Verfügung.

Bitte verwenden Sie nicht das Hexfile mit dem vorbereiteten Arduino-Bootloader, sondern das File mit der Bezeichung „projektname.ino.standard.hex“.

Dieses Hexfile kann nun über die ISP-Schnittstelle auf den µController übertragen werden.

Zur Vereinfachung sollten sie das neue Arduino-Hexfile umbenennen z.B. „mfm_2.hex“

Die nächste Seite beschreibt die Vorbereitung der ISP(SPI)-Schnittstelle, Installation und Übertagung von AVRDude und dem RaspberryPi


SPI - Vorbereitung des RaspberryPi

### 1. Freigabe SPI-Schnittstelle (RaspberryPi)

Raspi-config öffnen

sudo raspi-config

2. Freigabe SPI-Schnittstelle
3. Auswahl bestätigen
4. „raspi-config“ schliessen

Der RaspberryPi ist nun für die SPI-Kommunikation vorbereitet.

Zur Übertragung der Software auf den ATMega328p muss noch das Tool „avrdude“ installiert werden.

Übertragung über den RaspberryPi mit AVRDude (Hex-File über Raspi ISP-Port)

### 1. Installation AVRDude auf dem RaspberryPi

sudo apt-get install avrdude

### 2. Anpassung der Einstellungen AVRDude an benötigte Hardwarepins

Öffne AVRDude Konfiguration:

sudo nano /etc/avrdude.conf

Suche Zeile:

# PROGRAMMER DEFINITION

Füge unterhalb folgende Zeilen ein:

#-------------------------------------------------------------------------programmer

id = "spi_mfm";
desc = "Use RPi SPI for mains frequency monitor unit"; type = "linuxspi";
reset = 25;
baudrate = 100000;
;

Speichere die geänderten Einstellungen

### 3. Test AVRDude / Auslesen der Fuses

sudo avrdude -c spi_mfm -p m328p –P /dev/spidev0.0 -U lfuse:r:-:b

### 4. Setzen der benötigten Fuses mit folgenden Kommandozeilen:

sudo avrdude -c spi_mfm -p m328p –P /dev/spidev0.0 -U lfuse:w:0b11111111:m

sudo avrdude –c spi_mfm -p m328p –P /dev/spidev0.0 -U hfuse:w:0b11011001:m

sudo avrdude -c spi_mfm -p m328p –P /dev/spidev0.0 -U efuse:w:0b11111111:m

### 5. Übertrage das aktuelle HEX-Programm

(aktualisiert mit Arduino-IDE oder als Download von der Projektseite)

sudo avrdude –p m328p –c spi_mfm –P /dev/spidev0.0 –U flash:w:“mfm_2.hex“

Hexprogramm „mfm_2.hex“ , oder eigener/neuer Quellcode

Getestet mit dem RaspberryPi 3 und einem ATMega328p

weitere Übertragungsmöglichkeiten finden Sie in Kürze auf der Projektseite…

Messung / Ausgabetest

Überprüfung der Funktion mit einem Terminalprogramm:

- Öffnen sie ein Terminalprogramm z.B. PUTTY
- Überprüfen Sie die Einstellungen der Serial-Schnittstelle
- | Serial Line: | /dev/ttyS0 (oder /dev/ttyAMA0)
Baud: 19200 Bd | Databits: 8 | Stopbits: 1 | Parity: NONE Flow Control: NONE

Das Terminalprogramm zeigt nach dem Öffnen den Datenfluss der Netzfrequenzmessung.

Protokollausgabe 1 | Protokollausgabe 2 | Protokollausgabe 3 | Protokollausgabe 4


Die Aufzeichnung habe ich an meinem Linux-Laptop und einem USB-TTL-Adapter mit der universellen Netzfrequenzmessung RPi/USB gemacht.

### Kommunikation der Netzfrequenzplatine

Das Konsolenprogramm mfmServerTool ermöglicht die Aufzeichnung und die Bereitstellung der Netzfrequenzmessdaten für leittechnische Anbindung z.B. OPC-Server.
Das Konsolenprogramm ist lauffähig auf Windows und Linux (RaspberryPi).

Die Daten können auf dem Web-Server des ioBrokers, dem OpenHAB (Open Home Automation Bus) oder dem OpenMUC (Web-Interface zur Systemkonfiguration und Visualisierung) problemlos visualisiert werden.

Das ServerTool-Programm steht in Kürze zur Verfügung.

Details zur Projekterweiterung finden Sie auf der Webseite www.netzfrequenzanzeige.de.


Bild: Schema Netzfrequenzmessung und Anbindung an eine Leittechnik

Sonstiges : Freigabe GPIOs

### Infos / Bestellmöglichkeit

### - weitere Informationen unter www.netzfrequenzanzeige.de

- Anfrage privater Verkauf Platinen und Wechselspannungsnetzteile (Restposten) pc_projekte.de@arcor.de
- Privater Programmierservice für µController
- | Link für aktuelle Bauteileliste (bei Reichelt) | https://www.reichelt.de/my/1689769

### Hinweis / Gewährleistungsausschluss

Projekthinweis: Das gesamte Projekt ist ein privates, nicht kommerzielles Projekt.

Der Autor übernimmt keinerlei Gewähr für Funktionalität der vorgestellten Hard- und Software. Haftungsansprüche gegen den Autor, welche sich auf Schäden materieller oder ideeller Art beziehen, sind grundsätzlich ausgeschlossen. Die Inhalte der Homepage, der Projektbeschreibung oder der Software werden ohne Anspruch auf Richtigkeit veröffentlicht. Alle Angaben sind ohne Gewähr. Die Verwendung der Texte, Grafiken, Bilder und Programme sind im Rahmen der zum Projekt gehörenden OpenSource-Lizenzen erlaubt. Der Autor behält es sich ausdrücklich vor, Teile der Seiten ohne gesonderte Ankündigung zu verändern, zu ergänzen oder zu löschen.

- Verwendung der Soft- und Hardware auf eigene Verantwortung
- Jegliche Produkthaftung durch die Verwendung der Soft- und Hardware wird ausgeschlossen

Haftungsausschluss nach §1 Abs.2 Z.3 ProdHaftG , (BGBl. I S. 1474 m.W.v. 08.09.2015 der Bundesrepublik Deutschland )

### Information zur Spannungsversorgung

Die Spannungsversorgung muss der Beschreibung entsprechen, da es sonst zu Zerstörung von Bauteilen kommen kann.

### Jens Müller, 02‘2021 www.pc-projekte.de

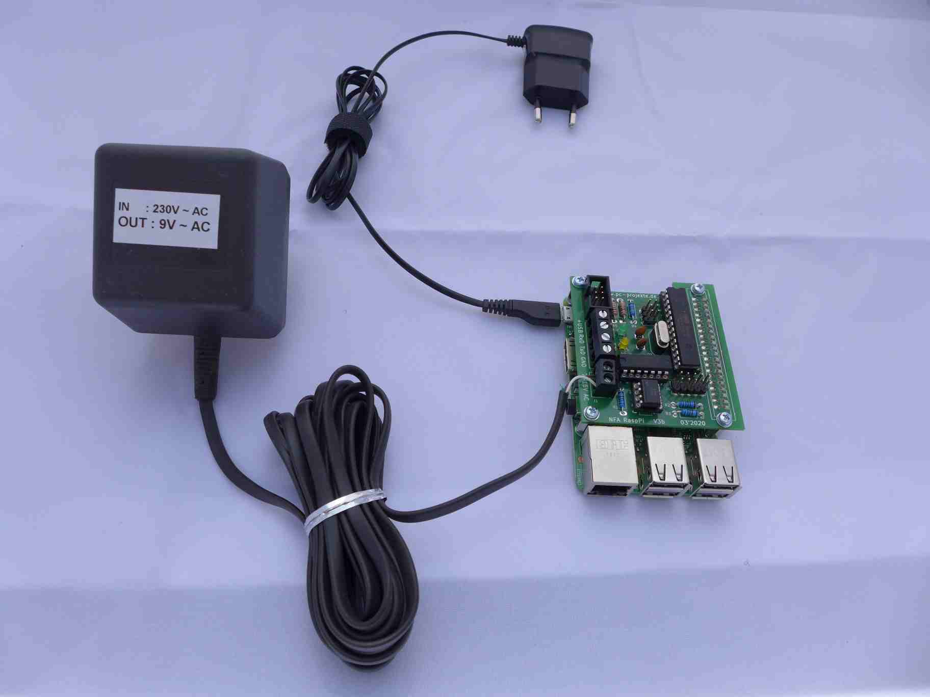
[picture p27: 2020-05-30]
Picture/Pic002.jpg

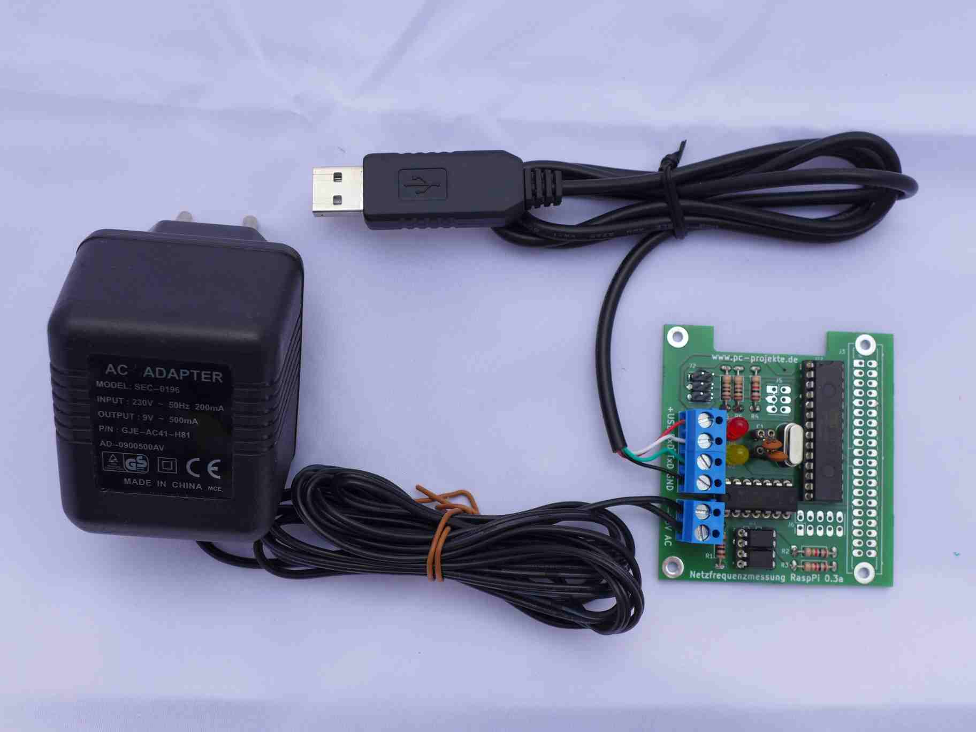
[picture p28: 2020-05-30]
Picture/Pic020.jpg

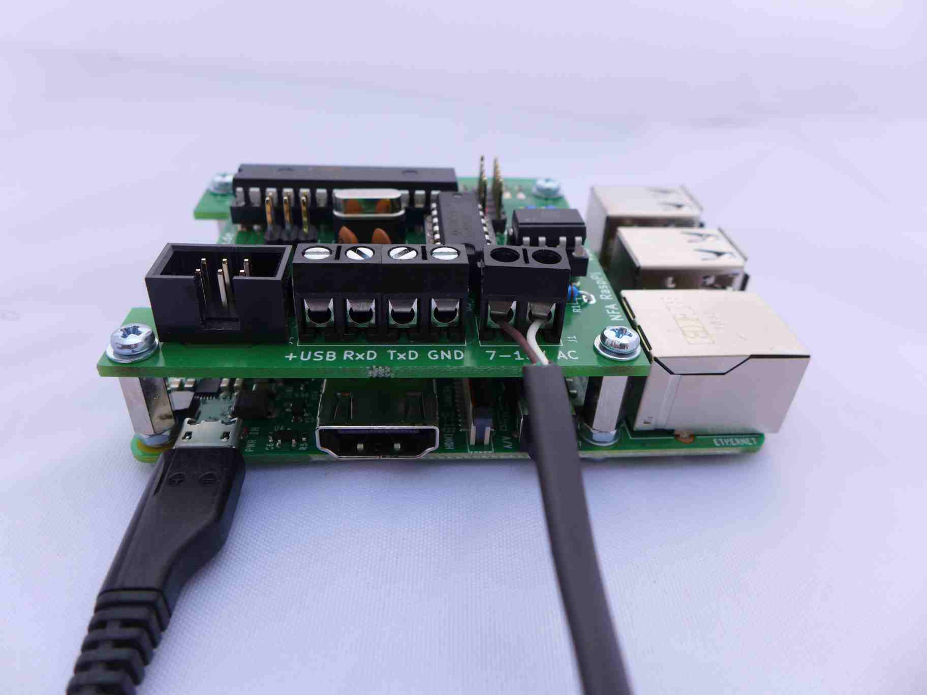
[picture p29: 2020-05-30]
Picture/Pic004.jpg

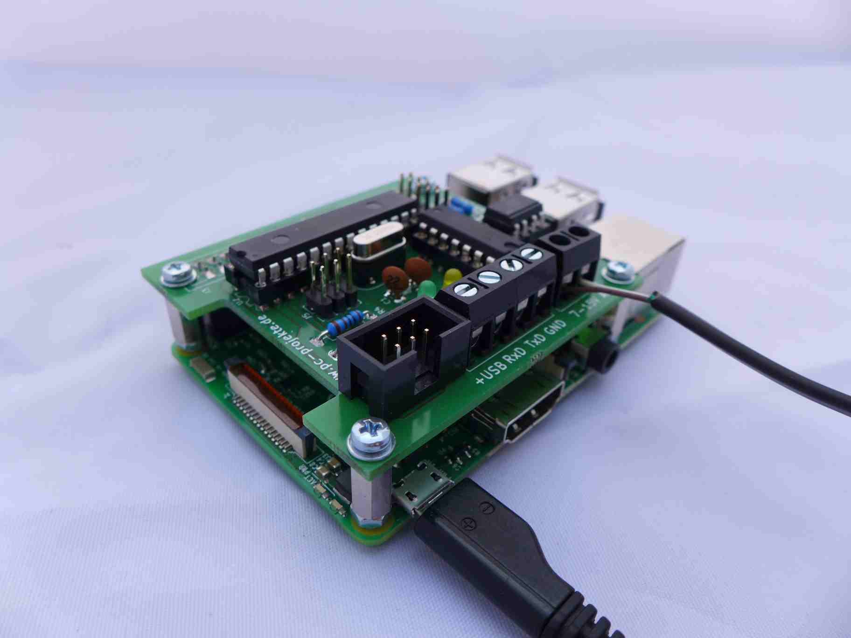
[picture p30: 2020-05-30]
Picture/Pic005.jpg

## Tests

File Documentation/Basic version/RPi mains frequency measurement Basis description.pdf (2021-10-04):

# MAINS FREQUENCY MONITORING UNIT Mains frequency measurement for the RaspberryPi (and USB-TTL converter) Basic documentation

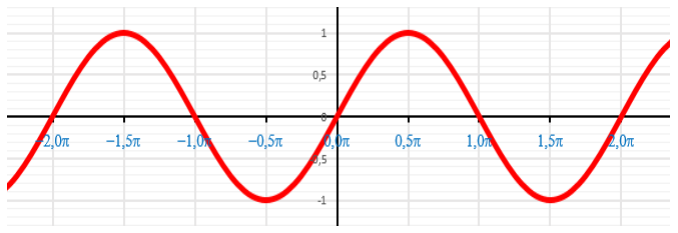
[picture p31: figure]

## The view into our power grid


### Mueller, Jens, www.pc-projekte.de

pc_projekte.de@arcor.de

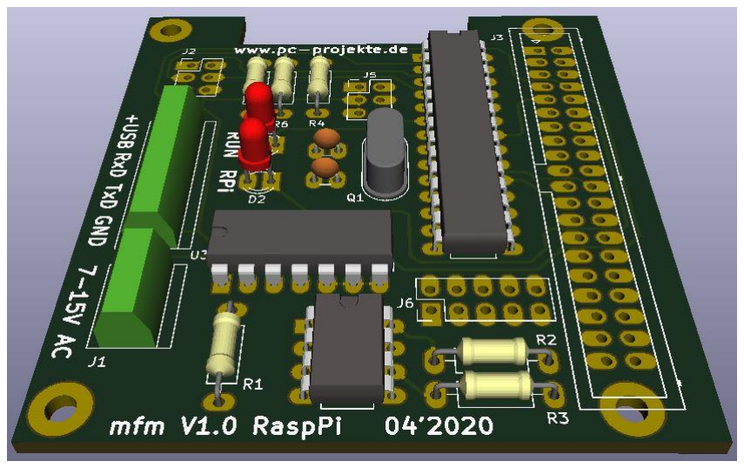
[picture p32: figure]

### Project description MAINS FREQUENCY MONITORING UNIT V1.0

Measure and monitor your mains frequency. The deviation from the Setpoint provides a direct quality indicator of the instantaneous power offered of the power plants and consumer demand. The grid frequency is therefore a Guarantor of grid stability and shows effects of intraday electricity trading

30.6.2020

Inhaltsverzeichnis

## License

### Documentation

### Creative-Commons-License

This project documentation is licensed under the Creative Commons Attribution - Distribution under Equal Conditions 4.0 International. To view a copy of this license, visit

http://creativecommons.org/licenses/by-sa/4.0/

This document is a base document and is part of the OSHWA Openhardware
release.

A project extended version with current features and extensions will be available for download soon.

### OpenHardware (OSHWA)

The hardware is published under a CERN license as OpenHardware (Open Source Hardware)

The project is OSHWA certified under no. DE000086.

Complete project documentation and all licenses under

https://gitlab.com/jm_wtal/mains-frequency-measure

Information about Oshwa: https://www.oshwa.org/definition

### Software / source code license

The source code is under the GNU GPL 3 license:

- Freedom to run the program for any purpose
- Freedom to study and adapt the source code
- Freedom to copy the program
- Freedom to copy the modified program

These freedoms should also be guaranteed in the long term. To this end, the GPL contains two essential clauses:

- Every derivative must also be fully licensed under the GPL.
- If the program is distributed in binary form, the source code of the entire program must be provided or handed over on request.

### Background

Our power grid
The mains frequency in Europe is 50Hz. A deviation from the nominal value is a direct window of electrical generation and consumption. The power output must be matched by an equal power consumption at all times.

If there are deviations, this leads to a change in the grid frequency: If there is an oversupply of electrical power, the grid frequency increases, if there is an undersupply, the frequency decreases. Normally, these deviations are minimal in the Western European interconnected grid and range from 49.80Hz - 50.20Hz. The task of the so-called power control in the electricity grid is to compensate for the load fluctuations and thus to keep the grid frequency at a constant nominal value.

In Europe, Asia, Australia, most of Africa and parts of South America, a grid frequency of 50 Hz is used for the general electricity grid, in so-called interconnected grids. In North America, a grid frequency of 60 Hz is used in the public power grid. The differences are due to the historical development history of the first power grids in the 1880s and 1890s and have no technical reason today.

Some railways, such as the ÖBB, SBB and Deutsche Bahn use a nominal frequency of 16.7 Hz for their traction power supply. In the past, the nominal railway network frequency was 16 2⁄3 Hz, which is exactly one third of the 50 Hz used in the interconnected network. Some railways and also industrial customers in North America are supplied with a grid frequency of 25 Hz for historical reasons. The comparatively low grid frequencies result from the technological development of the first electrical machines: At the beginning of the 20th century, it was only possible to build electrical machines of greater power with these low frequencies. However, due to the great effort involved in the conversion, the low mains frequencies introduced at that time are still used today.

In special areas, e.g. in the on-board power supply system of aircraft, higher mains frequencies are common, e.g. 400 Hz, as smaller and lighter transformers can be built for this purpose and the cable lengths are short.

Mains frequency as a quality indicator
The grid frequency and its deviation from the nominal value is a direct quality indicator of the relationship between the instantaneous electrical power offered by producers such as power plants and the decrease in instantaneous electrical power by consumers. Electrical energy can hardly be stored in interconnected networks, but only distributed between the producer and the consumer. With the exception of the reactive power of alternating current, the power output must be balanced by an equally high power consumption at all times.

If there are deviations, this leads to a change in the grid frequency in AC voltage grids: If there is an oversupply of electrical power, the grid frequency increases; if there is an undersupply, it decreases. Normally, these deviations are minimal in the Western European interconnected grid and are below 0.2 Hz. A frequency deviation of 0.2 Hz corresponds to a power difference of approx. 3 GW in the European interconnected system, which also corresponds to the so-called reference failure from the Continental Europe Operation Handbook and is approximately equivalent to the unplanned outage of two larger power plant units. The task of power control in interconnected grids is to balance out the temporal fluctuations and thus to keep the grid frequency at a constant nominal value. The smaller an electricity supply network is and the worse the network control functions, the greater the fluctuations in the network frequency.

Undersupply of energy | Oversupply of energy

This fluctuation can be measured:

With my project, I would like to make the dynamics of the power grid visible. The electronics record the grid frequency and, derived via a mathematical function, enables the grid load difference to be displayed in MW (megawatts). This grid load difference corresponds to the primary control power.


Picture: Mains frequency measurement (example graphic evaluation with Grafana®)

This is a private, non-commercial project. The electronics, µController and project software is developed by me (see also Creative Commons License).

Boards, programming service and components see ordering option (page 27).

Using the mains frequency board

Measuring board for recording, information, message, alarm and monitoring purposes of the mains frequency

The device can be flexibly adapted to the characteristics of a power grid (e.g. 60Hz grid). A calculation and output of the network load difference (primary control power) is in preparation.

The output is via the serial interface. The board is designed for the RaspberryPi, but can alternatively be used with a USB-TTL converter.

Furthermore, output outputs for alarm and message systems are prepared.

A provision of the measured values via a Modbus-TCP software will be available soon, further protocols e.g. MQTT (IoT), IEC60870-4-104 FW protocol or as logic device of an IEC61850 system are planned.

Components (Information)

No smd technology is used to make it as easy as possible to reproduce. The corresponding reproduction instructions and component lists can be found from page 20 onwards (for ordering the board and components, see page 26). A partially populated board with SMD is in preparation.

Software
µController ATMEGA328-16PU DIP-28 8-Bit 10 MHz (Arduino - compatible)

The latest software can be downloaded from the Gitlab site or from www.pc-projekte.de or http://www.netzfrequenzanzeige.de.

Measuring voltage

Warning: NEVER use direct 230V mains voltage for mains frequency measurement!

Measuring voltage: power supply unit (or transformer) with AC voltage

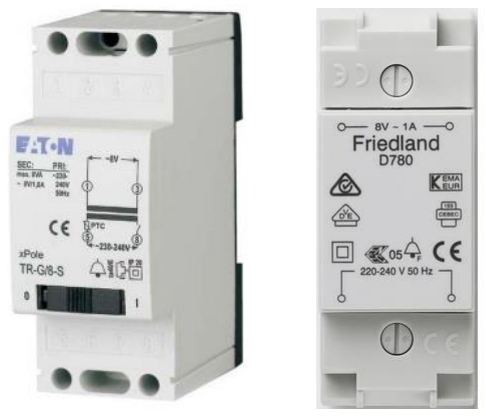
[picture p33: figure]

Picture: bell transformers | Plug-in power supply unit (AC-AC) | Print transformer

See also note / exclusion of warranty.

### Frequency measurement

Description of measuring procedure

The frequency measurement is carried out via an edge evaluation of the AC voltage signal. The signal is fed to the µController via two optocouplers and an RS-FlipFlop (4093-nand gate as RS-FlipFlop) and evaluated with the 10MHz quartz clock and the Timer1 (as counter) of the µController

Measurement accuracy

The accuracy of the mains frequency measurement is very high even without calibration. Decisive is the accuracy of the quartz Q1 (and the correct size C1 and C2, matched to Q1 ).

The measurement error of the frequency measurement (without calibration or mains frequency trigger circuit board) is less than ± 1 mHz.

A calibration of the measurement is possible via a source code setting.

Temperature range
The mains frequency display should be used at room temperature. Direct sunlight on the housing or the board and the associated temperature effect can falsify the measurement result.

Powerquality

The mains frequency display is normally insensitive to mains feedback described in EN50160.

Very strong electrical pulses in the environment, unusually high harmonic content or ripple control signals in the measurement voltage (mains feedback) can falsify the measurement result.

See also Measurement data preparation

Measuring range recognition at program start

An automatic mains frequency recognition is carried out when the program is started.

After successful detection, the corresponding limit ranges of the detected mains frequency are used in the filter stages.

Min/Max | 50Hz-Netz | 60Hz-Netz | 16,7 Hz*
Max f | 45 Hz | 55 Hz | 22 Hz
Min f | 55 Hz | 65 Hz | 12 Hz

*) 16.7 Hz networks

Rail network frequency e.g. Germany, Austria and Switzerland (standard gauge)

16.7 Hz measurement is basically possible, but is not integrated at the moment

The corresponding mains frequency can be set manually

automatic frequency detection | 50 Hz / 60 Hz (16,7 Hz ) | FA = 0
50 Hz mains frequency | 45,000 Hz – 55,000 Hz | FA = 50
60 Hz mains frequency | 55,000 Hz – 65,000 Hz | FA = 60
A version for 16.7 Hz is prepared | 12,000 Hz – 22,000 Hz | FA = 16

### Settings for the prescale measuring method

Some settings can be made for the measurement procedure in order to adapt or optimize the measurement duration and measurement periods to the µcontroller.

For this purpose some parameters can be set or changed in the µController program.

Settings in the Arduino source code:

Setting name | Default setting | Function
Prescaler | 64 | Internal divider of the µC clock (ATMega328 clock)
Messperiode | 18 | Maximum period count
Dividend | 2812500 | (edge counter until next frequency calculation)
Sperr | 2400 | Constant value for frequency conversion
UBRR | 0X40 | (results from the prescaler and the measuring period)
DiffMAX | 60 | Blocking time after detected input edge to suppress signal bounce
FA | 0 | Correction value for serial interface
Calibration | 0 | (adaptation of the baud rate to the 10MHz clock)

The settings are described in detail on the following pages.

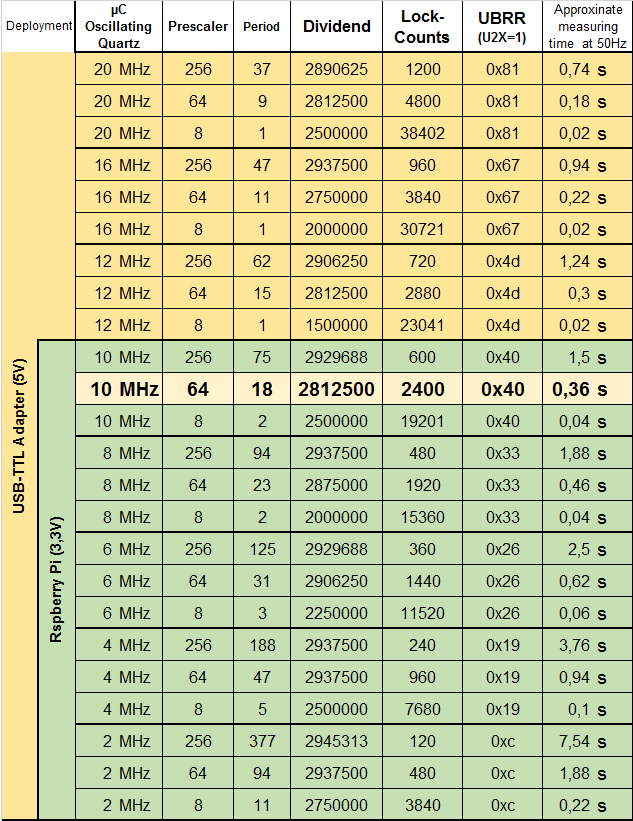
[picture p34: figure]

Table: optimized setting data for mains frequency measurement

Settings in the Arduino program code (basic source code):

// Settings / Einstellungen

// ***************************************************************************************************

#define F_CPU 10000000

const word Prescaler = 64; | // Prescaler (0,8,64,256,1024)
const byte Messperiode = 18; | // Period
const unsigned long Dividend = 2812500; | // DIVIDEND Calculation constant
const word Sperr = 2400; | // Lock-Counts
const int UBRR = 0x40; | // Correction serial baud/clock
const int DiffMAX = 60; | // DifferenzMAX
byte FA = 0; | // Selection 0 = Auto, 50=50Hz, 60=60Hz
const short Calibration = 0; | // MeasureCalibration

// ****************************************************************************************************

All program settings can be found in lines 10 - 20 in the Arduino source code (base code)

<== Recommended setting Raspberry Pi

- Crystal 10MHz
- Prescaler 64
- Period 18
- Dividend 2812500
- Lock counts 2400
- UBRR 0x40

Programming via ISP port

Measurement of the mains frequency

Basic principle is the timer1 of the µController, which is set to the fixed clock 10MHz DIV 64 without further processing when the µController is started. With this setting, Timer1 becomes the reference clock from which the mains frequency is now derived. The total time length of the passing Timer1 (0 ... 65535) is 423ms.

This optimizes the number of periods for mains frequency measurement (for 45 Hz) to 18.

Calculation

Timer 1 runs in the set prescale mode with the (divided) clock of the µcontroller as counter.

The mains frequency is fed to the INT0 of the µcontroller via the optocoupler and the Schmitt trigger. A recognized trigger event leads to an internal incrementing of the period counter.

The trigger inhibit time (inhibit/lockcounts 2400) prevents a too fast multiple evaluation of the edge (e.g. due to an interference signal).

When the maximum period counter value is reached, the counter value from Timer1 is taken over.

The counter value of Timer1 becomes the basis for calculating the grid frequency as a divisor with the constant dividend (2812500). In addition, the factor 1000 is multiplied. The mains frequency is then output in mHz. This has the advantage that all mains frequency calculations up to this point are performed exclusively in fixed-point arithmetic. This process is therefore carried out very quickly in the µC (thus even executable on an ATTiny).

Calculation:

fMess (variable name in source code) in mHz (Ex. 50021 = 50.021 Hz)

The preliminary frequency value (fMess) is now passed through several filter stages.

The output (frequency) is a serial protocol on the TxD port of the µController

UBRR

To adapt the 19200Bd output of the serial interface to the 10MHz crystal, the UBRR register value must be adjusted by input.

For a 10MHz crystal UBRR = 0x40 must be set.

### Detailed description of the measurement

### Input circuit Schmitt trigger

The input circuitry (mains frequency measuring input) is electrically isolated via 2 optocouplers. The measuring voltage is supplied via a transformer and should lie between 7V- 15 V ~ AC. The current of the used measuring voltage is not more than 20mA. A short-circuit-proof transformer or a bell transformer should be used for the measurement. The input circuitry of the optocouplers U1 (U1a/U1b) is current limited by R1 (see also Information Components page 20).

The optocouplers drive Schmitt triggers (CMOS 4093, IC U3) via a NAND gate, which then forwards the measurement signal as a square wave to the INT0 input of the µcontroller.

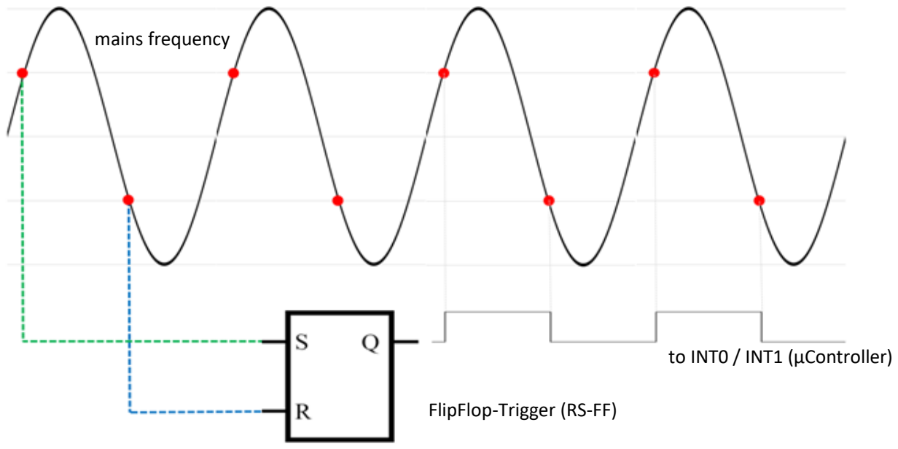
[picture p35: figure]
mains frequency; to INT0 / INT1 (µController); FlipFlop-Trigger (RS-FF)

Figure: Schematic representation of edge evaluation (Schmitt trigger)

The advantage of this measurement data processing is that even a very noisy input signal is reliably detected.


Figure: Schematic representation of a noisy input signal and with output signal (behind the Schmitt trigger)

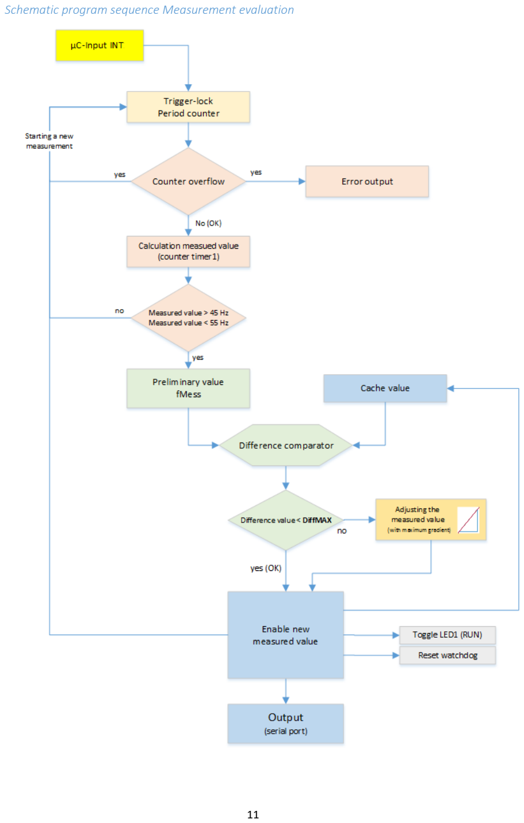
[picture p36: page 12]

Schematic program sequence Measurement evaluation

Evaluation with the µController INT0 / INT1

Edge detection and trigger signal inhibit:

If the µcontroller detects an edge, a blocking time (approx. 15ms) is immediately started to suppress subsequent measurement peaks. A possible too early edge is immediately compensated by the subsequent stage, since an averaging process now follows.

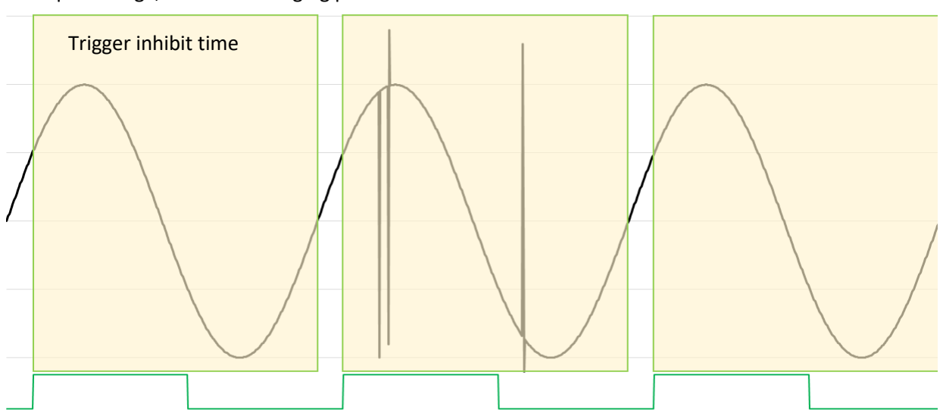
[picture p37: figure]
Trigger inhibit time

Figure: Schematic representation of the trigger inhibit time

Lock-Counts

The blocking time after a pulse is selected so that the next trigger signal would only fit with a frequency below 65 Hz.

Evaluation of the measurement counters


Plausibility filter

Before the measured mains frequency value is further processed, the preliminary new measured value is subjected to a two-stage test: This determines whether the measured mains frequency value is basically within the permissible range:

Measurement | 50 Hz measurement | 60 Hz measurement | 16.7 Hz*
Test f> | f > 45 Hz | f > 55 Hz | 22 Hz
Test f< | f < 55 Hz | f < 65 Hz | 12 Hz

After this first check, which excludes implausible measured values, it continues to the differential filter

Difference Comperator Filter

Functionality of the differential compensator filter:

The difference-comperator filter uses the default maximum mesh gradient. A mains frequency change above the maximum mains gradient is only partially taken into account.
However, if two consecutive measurements pass the validity check, even a very fast change is immediately accepted.

Procedure: The preliminary (new) measured value is compared with the last valid measured value. The difference between the two measured values is determined by calculating the difference.

Diff = ABS (fpreliminary − fMess )

If the difference (absolute value) is smaller than the default setting DiffMAX, the new value (Preliminary Value) becomes the valid measured value fMess.

If the difference is greater, the current measured value fMess is adjusted to the new value (Preliminary Value) at the level of the default setting DiffMAX.

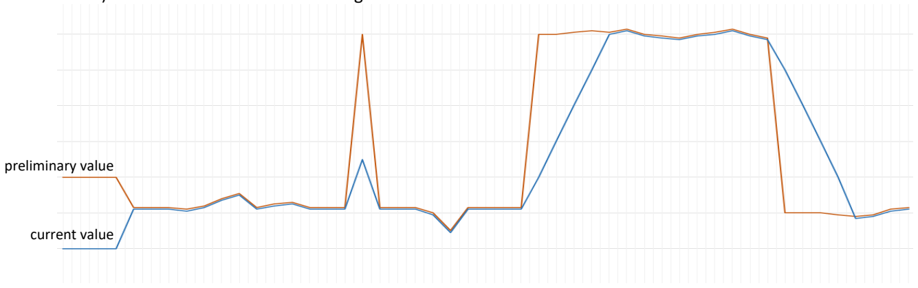
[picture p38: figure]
preliminary value; current value

Figure: Schematic representation of the course of measurement data Difference-comparator-filter

The network gradients depend on many network circuit states, feeders, network load situations and the measurement location. Therefore, the following DiffMAX value is a recommended setting for the UCTE network.

The default setting of the DiffMAX filter is 60mHz/s (recommendation).

Programm Diff-Filter (Arduino-Programm)

word Diff_filter(word filter_wert) | // Measurement data in mHz in WORD format
{
int Diff = filter_wert - Cachewert;
if ( abs(Diff) > DiffMAX ) | // if DiffMAX is exceeded
{
if ( Diff > 0) filter_wert = Cachewert + DiffMAX; | // Change (positive slope) max
if ( Diff < 0) filter_wert = Cachewert - DiffMAX; | // Change (negative slope) max
}
Cachewert = (int)filter_wert;
return filter_wert;
}

Calibration

Normally the mains frequency board does not need calibration.

However, if calibration is required, a calibration value can be added to the setting. Shortly different settings a software tool (via an EEP file) can transfer changed settings to the EEProm of the ATMega328. After a restart the changed settings are used.

### Frequency + Calibration → Output to serial interface

Serial protocol

serial interface settings

Baudrate: 19200 Baud | Parity: None | Stoppbit: 1 | Handshake: None

UBRR = 0x40

In order to adapt the output of the serial interface to the 10 MHz crystal, the UBRR register value must be adapted via the input. For a 10 MHz crystal UBRR = 0x40 must be set.

Selection of protocols

In the basic version this possibility is not yet realized. In the extendend version the output protocols can be selected via the jumper setting of the J5 interface.

Basic protocol 6-byte protocol (5+1)

Figure: Structure and telegram sequence 6-byte protocol

From Output of the basic protocol on the serial interface is in mHz.

LEDs
LED 1: RUN LED

LED1 (RUN) Status change (toggle) at each successful filter run.

(toggle= changes the binary state)

Arduino output : 4 (=Pin6, PD4)

LED 2: RPi-Led

LED 2 can be controlled by a program on the RaspberryPi.

RaspberryPi output : GPIO5 (=Pin12)

### Use with a USB-TTL converter

The mains frequency board can also be used without a RaspberryPi for mains frequency measurement. The data output and the power supply is then realized via the USB interface (USB-TTL converter).

For this operating mode the connector J4 is prepared.

JP4: This port provides the serial telegram (details see "serial protocol")

Pin | Bezeichnung | Funktion | Hinweis
1 | GND | Ground / GND
2 | RxD | Receive direction (to USB), TTL level* | Vom µC (TxD)
3 | TxD | Receive direction (from USB), TTL level* | Zum µC (RxD)
4 | +5V | Supply voltage 5V DC

*) see TTL level

Miscellaneous / Extensions:

Pin J5
J5 prepared for protocol selection (serial interface)

Pin J6
J6 prepared as universal IO interface (e.g. relay output)

## Elektronic kit

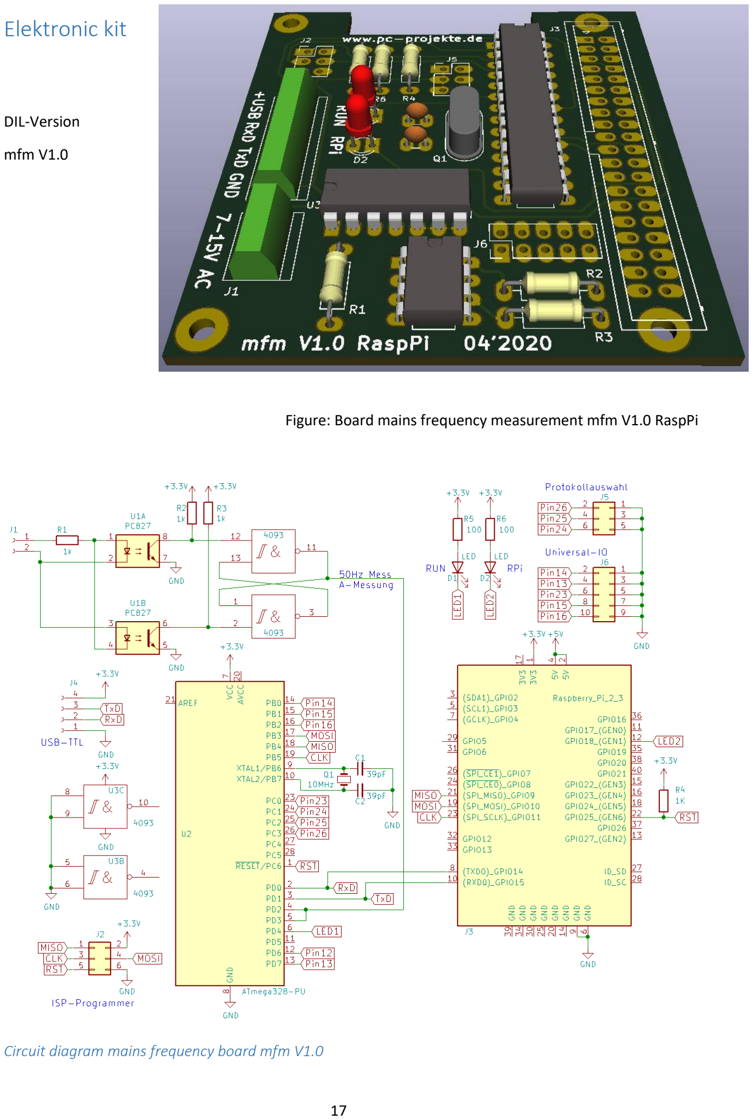
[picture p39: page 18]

DIL-Version

mfm V1.0

Figure: Board mains frequency measurement mfm V1.0 RaspPi

Circuit diagram mains frequency board mfm V1.0

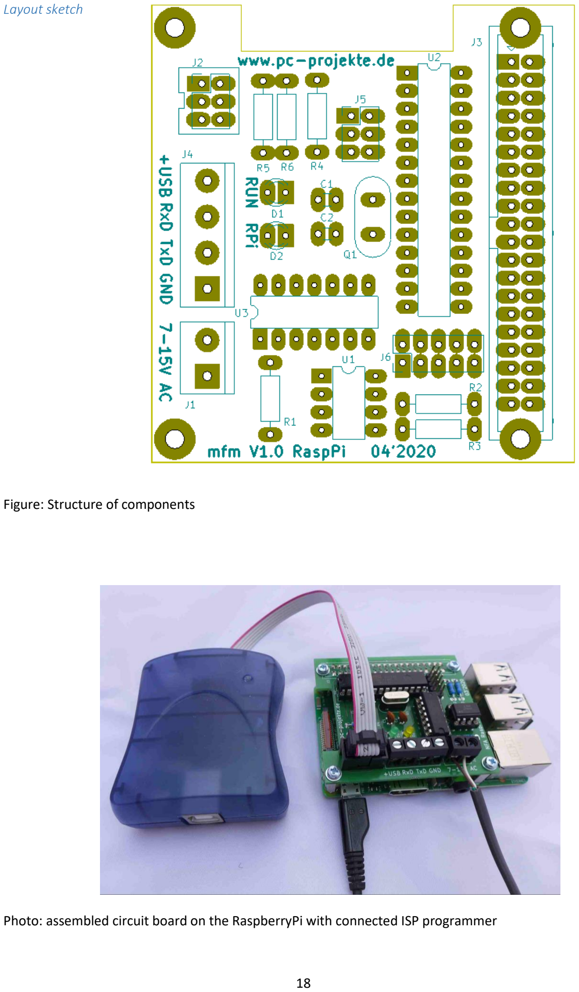
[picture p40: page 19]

Layout sketch

Figure: Structure of components

Photo: assembled circuit board on the RaspberryPi with connected ISP programmer


Board layout

Picture: Board layout back side | Picture: Board layout front

Components:
Components | Value | Function | Info
C1,C2 | 22pF | Capacitor | see also quartz and C1 / C2
D1,D2 | LED | LowCurrent-LED
R1* | 1k (1000 Ω) | Resistance see below | Adaptation to input voltage
R2,R3,R4 | 1k (1000 Ω) | Resistance
R5,R6 | R100 (100 Ω) | Resistance
U1 | PC827 | Optocoupler | Alternative: 2 pcs. PC817
U2 | ATMega328 | Atmel µController | (Arduino - Compatible)
U3 | CMOS4093 | SchmittTrigger (NAND gate)
Q1 | 10MHz | Quartz (HC49U) | Q-load capacity: 30pF
J1 | 2-Pol Schraubklemme | Terminal | Solderable screw terminal 5mm
J2 | Wannenstecker 6-Pol | ISP port for ISP programmers | WSL 6G straight (2X3-pin)
J3 * | Buchsenleiste 2X12 Pol | RaspberrPi female connector strip | RaspPi Connector Pin 1-24
(U1) | IC-Sockel 8-polig | IC Socket for U1 | Recommended accessories for U1
(U2) | IC-Sockel 28-polig | IC Socket for U2 | Recommended accessories for U2
(U3) | IC-Sockel 14-polig | IC Socket for U3 | Recommended accessories for U3
Trafo | 7 – 15 V AC ~ | Power supply unit / transformer
J4 | 4-Pol Schraubklemme | Terminal (2X2 screw terminal) | When using USB-TTL
J5 | Stiftleiste 2X3-Pol | Jumper | Universal input extension
J6 | Stiftleiste 2X5Pol | Function | Universal output extension
(*) in the case of the application for RaspberryPi

Also

- RaspberryPi 3 or 4 or USB-TTL converter
- Spacer for the mains frequency board: M2.5 X 12mm, female-female + screws 2.5mm X 5
- Housing

*) Recommendation / calculation Input resistance R1

R1 ≈

(U~) − ULed

ILed

=

UMess − 2V
10mA
Input voltage (AC) | Recommended size: R1
5V ~ - 7V ~ | 470 Ω
7V ~ - 15V ~ | 1k Ω
15V ~ - 25V ~ | 1,5k Ω

When used with USB (without RPi)

- USB to TTL serial UART converter with 5V (or 3.3V)


Figure: USB-TTL converter | Figure: Connection example USB-TTL converter (without RPi)


Figure: Connection diagram USB-TTL converter

USB-TTL-Converter

7-15 V AC ~ mains frequency

Installation instructions:; U1 Optocoupler; Mounting position J2

Two PC817 (U1a, U1b) can be used instead of one

In this case the assembly must be done as shown in
the following figure:

Picture: alternative assembly of 2 pcs. PC817 instead of 1 pc. PC827

Mounting position LED 1 and LED 2

The assembly/mounting position of the LEDs must
as shown in the picture on the right.

Information about the quartz

Distance of the quartz to the board

Picture: Quartz distance to the board

Component information: Quartz and C1 / C2

10.0000-HC49U-S, standard quartz in housing HC49/U-S.

- Frequency: 10.0000 MHz
- Cl: 32 pF | ==> C1 / C2 = 22pF | Note load capacitance in the data sheet!
- Rsmax: 50 Ohm
- Temperature coefficient: ± 30 ppm
- Frequency tolerance: ± 30 ppm

Housing recommendation

The mains frequency board is prepared for use in a DIN rail housing


Picture: DIN rail housing for RaspberryPi 4 and RaspberryPi 3

Always keep a distance from the board during assembly to avoid short circuits
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

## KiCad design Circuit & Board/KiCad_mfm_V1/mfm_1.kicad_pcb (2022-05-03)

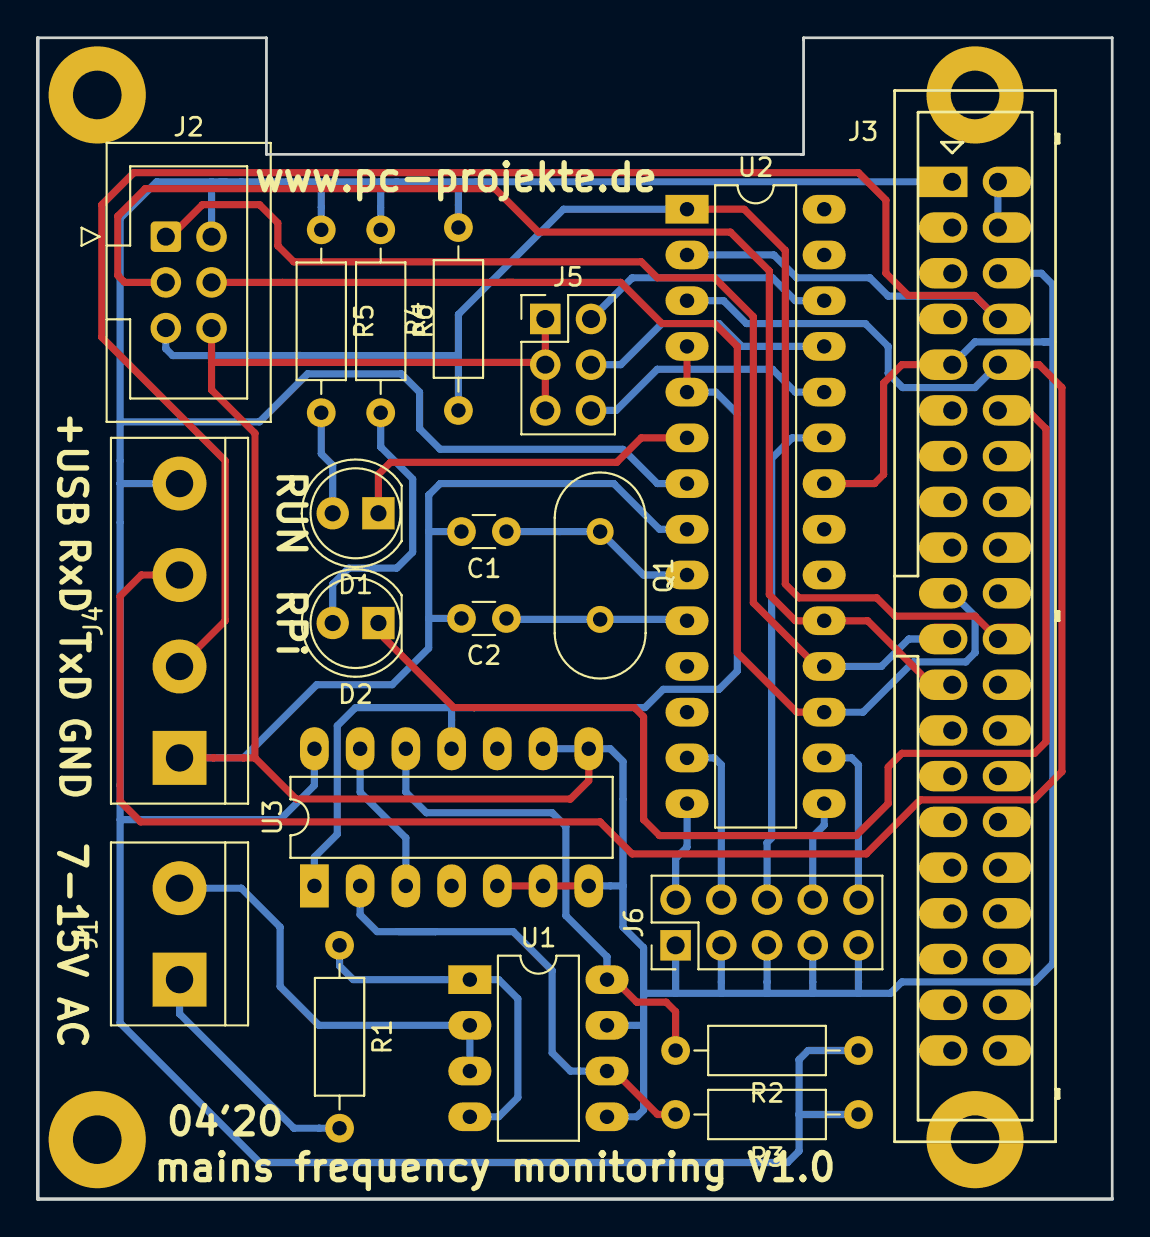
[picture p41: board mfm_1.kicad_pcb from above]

Board: 2 copper layers, 59.7 x 64.5 mm, 20 parts (0 on the bottom side), 30 nets.

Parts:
C1, C2: 39pF; C_Disc_D3.0mm_W1.6mm_P2.50mm
D1, D2: LED; LED_D5.0mm_Clear
J1: Conn_01x02_Female; TerminalBlock_bornier-2_P5.08mm
J2: Conn_02x03_Odd_Even; IDC-Header_2x03_P2.54mm_Vertical
J3: Raspberry_Pi_2_3; Multicomp_MC9A12-4034_2x20x2.54mm_Straight
J4: Conn_01x04_Female; TerminalBlock_bornier-4_P5.08mm
J5: Conn_02x03_Odd_Even; PinHeader_2x03_P2.54mm_Vertical
J6: Conn_02x05_Odd_Even; PinHeader_2x05_P2.54mm_Vertical
Q1: 10MHz; Crystal_HC49-4H_Vertical
R1, R2, R3: 1k; R_Axial_DIN0207_L6.3mm_D2.5mm_P10.16mm_Horizontal
R4: 1K; R_Axial_DIN0207_L6.3mm_D2.5mm_P10.16mm_Horizontal
R5, R6: 100; R_Axial_DIN0207_L6.3mm_D2.5mm_P10.16mm_Horizontal
U1: PC827; DIP-8_W7.62mm_LongPads
U2: ATmega328-PU; DIP-28_W7.62mm_LongPads
U3: 4093; DIP-14_W7.62mm_LongPads

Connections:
+3V3: J2.2, J3.1, J4.4, R2.1, R3.1, R4.2, R5.1, R6.1, U2.7, U3.14
+5V: J3.2, J3.4
CLK: J2.3, J3.23, U2.19
GND: C1.2, C2.2, J2.6, J3.6, J3.9, J4.1, J5.1, J5.3, J5.5, J6.1, J6.3, J6.5, J6.7, J6.9, U1.5, U1.7, U2.8, U2.22, U3.5, U3.6, U3.7, U3.8, U3.9
LED1: D1.1, U2.6
LED2: D2.1, J3.12
MISO: J2.1, J3.21, U2.18
MOSI: J2.4, J3.19, U2.17
unnamed: C1.1, Q1.1, U2.9
unnamed: C2.1, Q1.2, U2.10
unnamed: D1.2, R5.2
unnamed: D2.2, R6.2
unnamed: J1.1, R1.2
unnamed: J1.2, U1.2, U1.3
unnamed: R1.1, U1.1, U1.4
unnamed: R2.2, U1.8, U3.12
unnamed: R3.2, U1.6, U3.2
unnamed: U2.4, U2.5, U3.1, U3.11
unnamed: U3.3, U3.13
Pin13: J6.4, U2.13
Pin14: J6.2, U2.14
Pin15: J6.8, U2.15
Pin16: J6.10, U2.16
Pin23: J6.6, U2.23
Pin24: J5.6, U2.24
Pin25: J5.4, U2.25
Pin26: J5.2, U2.26
RST: J2.5, J3.22, R4.1, U2.1
RxD: J3.8, J4.2, U2.2
TxD: J3.10, J4.3, U2.3

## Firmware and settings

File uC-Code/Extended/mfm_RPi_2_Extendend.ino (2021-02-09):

/*
  lauffähiges Programm Netzfrequenzmessung Serial-Output RPi-Board oder USB-TTL-Konverter
  OpenSource Basisversion,  10'2020 J. Müller
  Software unter GNU GPL3-Lizenz
  freie Verwendung für kommerzielle und private Projekte unter gleichen Bedingungen
  Programming languange: Arduino IDE (1.8.12)
  www.netzfrequenzanzeige.de  
  www.pc-projekte.de
  Version mit Differenz-Filter
  erweiterte Version A- und B-Messung
  DeltaFilter
  Version mit Protokollauswahl
  Lastdifferenzanzeige
  bereinigte autom. Frequenzerkennung Start
  Protokoll 1,2,3,4
  Binärausgabe Low/HighAktiv
  Blinkfunktion
  erste finale Version für Dauertest mit Einstellungen
*/

/*
 * Wichtig ! Die µControler-Fuses müssen korrekt eingestellt sein!
   Low lfuse = 0xFF; (B11111111)
   High fuse = 0xDA; (B11011110)
   Extended fuse = 0xFF; (B00000101)
 */

// Settings / Einstellungen*****************************************************************************
#define F_CPU 10000000
const word          Prescaler = 64;        // Prescaler (0,8,64,256,1024)    Prescaler-Auswahl (0,8,64,256,1024)
const byte          Messperiode = 18;      // Period                         Periodendurchläufe
const unsigned long Dividend = 2812500;    // DIVIDEND Calculation constant  Dividend Berechnungskonstante
const word          Sperr = 2000;          // Lock-CountAs                    Vorgabe SperrCount
const int           UBRR = 0x40;           // Correction serial baud/clock   Anpassung Baud an Systemtakt
const int           DiffMAX = 100;          // DifferenzMAX                   maximal zulässiger Differenzwert zwischen den Messperioden
byte                FA = 0;                // Selection 0 = Auto, 50=50Hz, 60=60Hz     
const short         Calibration = 0;       // Korrekturwert                  Kalibrierung,Angaben in mHz.

// *****************************************************************************************************

// ********** Settings /Einstellungen ****************

//mains load differenz / Netzlastdifferenz
byte  Typ = 1;
float Lamda = 15.33333333;
float Offset = 10;
bool Neg = false;

// Alert mains frequency / Frequenzalarme
word f1g = 50070;       // fmax Alert
word f1k = 49930;       // fmin Alter
word tf1 = 10;          // Alert RelapseTime in s

word f2g = 50100;       // fmax Alert
word f2k = 49900;       // fmin Alter
word tf2 = 10;          // Alert RelapseTime in s

word f3g = 50200;       // fmax Alert
word f3k = 49800;       // fmin Alter
word tf3 = 10;          // Alert RelapseTime in s

word f4g = 51000;       // fmax Alert
word f4k = 49000;       // fmin Alter
word tf4 = 10;          // Alert RelapseTime in s


//Alert Output / Alarmausgaben
bool LowAktiv = true;   // Output Alarmausgabe LowAktiv
bool BlinkON = true;    // Blinkende Ausgabe z. B. LEDs


// ********** Settings /Einstellungen ****************


// *****************************************************************************************************


word FrequenzA;                             // mains frequency as WORD (mHz)  Netzfrequenz-Messwert als WORD in mHz A-Messung
word FrequenzB;                             // mains frequency as WORD (mHz)  Netzfrequenz-Messwert als WORD in mHz B-Messung
word Frequenz = 0;                      // mains frequency as WORD (mHz)  Netzfrequenz-Messwert als WORD in mHz
word MessA;                                 // preliminary measurement        vorläufiger Messwert
word MessB;                                 // preliminary measurement        vorläufiger Messwert
//double f;
//int Diff;                                 // Difference measurement         Differenzmesswert
word TriggersperrA = Sperr;                 // Lockout-Counter (presetting)   Trigger-SperrCount mit Vorgabe
word TriggersperrB = Sperr;                 // Lockout-Counter (presetting)   Trigger-SperrCount mit Vorgabe

bool AuswertungA = false;                   // Evaluation                     starte Auswertung aus Rohdaten AMessung
bool AuswertungB = false;                   // Evaluation                     starte Auswertung aus Rohdaten BMessung
bool CheckA = false;                        // Measure Evaluation CheckA      Ergebniss 1.Prüfung AMessung
bool CheckB = false;                        // Measure Evaluation CheckA      Ergebniss 1.Prüfung BMessung

byte PeriodeA = 0;                          // Period Counter                 Perioden-Durchlaufzähler
byte PeriodeB = 0;                          // Period Counter                 Perioden-Durchlaufzähler
word CountA = 0;                            // Raw Data Buffer                Zwischenspeicher Messwerte AMessung (Rohdaten)
word CountB = 0;                            // Raw Data Buffer                Zwischenspeicher Messwerte BMessung (Rohdaten)
word T2Counter = 0;
word BTriggerCounter = 0;

const byte LED = 4;                         // Output LED RUN                 Ausgabe LED RUN
bool Toggle;                                // toggle auxiliary bit           Toggle-Hilfsbit

byte Ueberlauf = 0;                         // Overflow Counter               Überlaufs-Zähler
byte ResetCounter = 0;
bool Reset_OK = false;


#include<avr/wdt.h>                         // Watchdog Vorbereitung...


// '********** Hilfsvariablen  ****************// 

//Hilfsvariablen int Cachewert ;//As Long                                     ' 
int CacheA = 50000;                                //  Hilfsspeicher für Differenzfilter A-Messung
int CacheB = 50000;                                //  Hilfsspeicher für Differenzfilter B-Messung
bool DeltaA = false;                                //  Hilfsvariable Delta A-Messung erkannt
bool DeltaB = false;                                //  Hilfsvariable Delta B-Messung erkannt

//Binäreingänge Protokolleinstellungen
const byte Jumper51 =  A3;                  // Pin26 A3
const byte Jumper52 =  A2;                  // Pin25 A2
const byte Jumper53 =  A1;                  // Pin24 A1
byte Protokoll;

// Binärausgaben
const byte Relay1 = 8;                      // Pin 14
const byte Relay2 = 7;                      // Pin 13
const byte Relay3 = A0;                     // Pin 23
const byte Relay4 = 9;                      // Pin 15 // prepared for mains frequency fast change alarm
const byte Relay5 = 10;                     // Pin 16 // prepared for mains frequency oscillation alarm 

// Hilfsvariblen Alarmausgaben
int AlarmCounter1 = 0;
int AlarmCounter2 = 0;
int AlarmCounter3 = 0;
int AlarmCounter4 = 0;
byte Alarm = 0;

// Hilfsvariable Blink
bool Blink = true;                          // Hilfsvariable

//Hilfsvariablen Sekundenmesstakt
int sc;                                     // Hilfsvariable

// ****************************************************************************************************



void setup()
{

  noInterrupts();                           // Alle Interrupts temporär abschalten

  // serial init
  Serial.begin(19200, SERIAL_8N1);
  UBRR0 = UBRR;                             // Korrekturwert/Anpassung an den 10MHz-Quarz

  // RUN-LED init
  pinMode(LED, OUTPUT);                     // LED Ausgabe vorbereiten

  //init Interrupt input    A-MESSUNG
  const byte interruptPinA = 2;
  attachInterrupt(digitalPinToInterrupt(interruptPinA), AMess, FALLING ); // neg- Flanke
  
  //init Interrupt input    B-MESSUNG
  const byte interruptPinB = 3;
  attachInterrupt(digitalPinToInterrupt(interruptPinB), BMess, RISING );  // pos- Flanke

  //Init Timer1
  TCCR1A = 0;
  TCCR1B = 0;
  TCNT1 = 0;                // Timer nach obiger Rechnung vorbelegen
  if (Prescaler == 1024) TCCR1B |= (1 << CS12) | (1 << CS10);
  if (Prescaler == 256)  TCCR1B |= (1 << CS12);
  if (Prescaler == 64)   TCCR1B |= (0 << CS12) | (1 << CS11) | (1 >> CS10);
  if (Prescaler == 8)    TCCR1B |= (1 << CS11);
  if (Prescaler == 0)    TCCR1B |= (1 << CS10);
  TIMSK1 |= (1 << TOIE1);   // Timer Overflow Interrupt aktivieren

  //Init Timer2
  TCCR2A = 0;
  TCCR2B = 0;
  TIMSK2 = 0;     // Reset Interrupts
  TCNT2 = 0;
  //  TCCR0 |= (1<<CS02) | (1<<CS00); // PRESCALER 1024
  if (Prescaler == 1024) TCCR2B  |= (1 << CS22) | (1 << CS20);
  if (Prescaler == 256)  TCCR2B  |= (1 << CS22);
  if (Prescaler == 64)   TCCR2B  |= (0 << CS22) | (1 << CS21) | (1 >> CS20);
  if (Prescaler == 64)   TCCR2B  = (1 << CS22);  
  if (Prescaler == 8)    TCCR2B  |= (1 << CS21);
  if (Prescaler == 0)    TCCR2B  |= (1 << CS20);
  TIMSK2 = (1 << TOIE2);   // Timer Overflow Interrupt aktivieren

  // Jumper-Input => Auswahl Protokolle
  pinMode(Jumper51,   INPUT_PULLUP);     // PIN = Eingang
  pinMode(Jumper52,   INPUT_PULLUP);     // PIN = Eingang
  pinMode(Jumper53,   INPUT_PULLUP);     // PIN = Eingang

  // Ausgang/Output
  pinMode(Relay1, OUTPUT);               // Alarm-Ausgabe vorbereiten
  pinMode(Relay2, OUTPUT);               // Alarm-Ausgabe vorbereiten
  pinMode(Relay3, OUTPUT);               // Alarm-Ausgabe vorbereiten
  pinMode(Relay4, OUTPUT);               // Alarm-Ausgabe vorbereiten
  pinMode(Relay5, OUTPUT);               // Alarm-Ausgabe vorbereiten

  interrupts();             // alle Interrupts scharf schalten

  wdt_enable(WDTO_8S);      //watchdog 8-Sekunden => Start-Watchdog


  Serial.write(27);       // ESC command
  Serial.print("[2J");    // clear screen command
  Serial.write(27);
  Serial.print("[H"); 

  Serial.println("NFA-RPi 2.0 extendend mfm (@Arduino)");
  Serial.println("02'2021 J.Müller www.pc-projekte.de");

  if ( !(FA == 50) && !(FA == 60 ))
  {    
  Serial.print("Auto-Detect");

  int diff;  
  int d = 0;
  bool fOK = false;
  do 
  {
    for (d; d < 5; d++)
    {
      delay(500);
      Serial.print('.');  
    }
    MessA = (Dividend * 1000) / CountA;   // Berechne vorläufige Netzfrequenz
    MessB = (Dividend * 1000) / CountB;   // Berechne vorläufige Netzfrequenz
    diff = (int)abs(MessA-MessB);
    d = 4;
    fOK = (diff < 10) && (MessA > 45000) && (MessA < 65000);
    if (!fOK) Serial.print("*");  
  }  
  while ( !fOK );
  
  delay(500);
  
  if ((MessA > 45000) && (MessA < 65000))
  {
   
    if ((MessA > 45000) && (MessA < 55000))  // Messwertauswahl 50Hz
    {
      FA = 50;
      Serial.println("  => detect 50Hz    ");
      delay(1000); 
    };
    
     if ((MessA > 55000) && (MessA < 65000))     // Messwertauswahl 60Hz
     {
      FA = 60;
      Serial.println("  => detect 60Hz    ");
      delay(1000);
     } 
     CacheA = MessA;
     CacheB = MessB;   
    }     
  } 
  else // Voreinstellung Netzfrequenz
  {
    if (FA == 50) Serial.println("User setting : 50Hz mains frequency");
    if (FA == 60) Serial.println("User setting : 60Hz mains frequency");
  }

  Protokoll = Protokollauswahl();
  if (FA == 60) Settings_60Hz();  
  
  Serial.print("Output protocol: "); Serial.println(Protokoll);
  delay(500);
  Serial.println("Start mains frequency measurement...");
  Serial.write(7);
  delay(500);
 

  wdt_enable(WDTO_1S);      //watchdog 1-Sekunde => Programm-Watchdog nach Start-Phase
  ResetCounter = 0;
 
}



void loop()
{

    Reset_OK = false;
    
  // A-MESSUNG
  if ( AuswertungA == true)
  {

    MessA = (Dividend * 1000) / CountA;           // Berechne vorläufige Netzfrequenz   ... X 1000 = mHz

    // Prüfung: Messwert im Gültigkeitsbereich
    CheckA = false;
    if ( (MessA >= 45000) && (MessA <= 55000) && (FA == 50)) CheckA = true;
    if ( (MessA >= 55000) && (MessA <= 65000) && (FA == 60)) CheckA = true;

    // Wenn der CheckA ok, dann weiter zum Differenzfilter / Ausgabe
    if ( CheckA == true)
    {
      FrequenzA = Diff_filterA(MessA);
      Reset_OK = true;
    } 
  }

  // B-MESSUNG
  if ( AuswertungB == true)
  {

    MessB = (Dividend * 1000) / CountB;           // Berechne vorläufige Netzfrequenz   ... X 1000 = mHz
 
    // Prüfung: Messwert im Gültigkeitsbereich
    CheckB = false;
    if ( (MessB >= 45000) && (MessB <= 55000) && (FA == 50)) CheckB = true;
    if ( (MessB >= 55000) && (MessB <= 65000) && (FA == 60)) CheckB = true;

    // Wenn der CheckB ok, dann weiter zum Differenzfilter / Ausgabe
    if ( CheckB == true)
    {
      FrequenzB = Diff_filterB(MessB);  
      Reset_OK = true;   
    }
  }


  if (AuswertungA)
  {
    if ( Delta_filter(FrequenzA,FrequenzB) || (DeltaA && DeltaB) )
    {
      Frequenz = FrequenzA + Calibration;
    }
    //else ;//Serial.println("Delta-Fehler A-Messung");
  }
  
  if (AuswertungB)
  {    
    if ( Delta_filter(FrequenzA,FrequenzB)  || (DeltaA && DeltaB)  )
    {
      Frequenz = FrequenzB + Calibration;
    }
    //else ;// Serial.println("Delta-Fehler B-Messung");
  }

  // Hier kommt die Frequenzauswertung---
  if (AuswertungA || AuswertungB)
  {
    AuswertungA = false;
    AuswertungB = false;
//      DeltaA = false;
//      DeltaB = false;

    // Frequenzalarm
    Frequenzalarm(Frequenz);

    //Protokollauswahl // Hier kommt die Protokollauswahl...
    Protokoll = Protokollauswahl();
  
    switch (Protokoll) 
    {
    case 1:    //Protokoll1  // 7-Byte
    {
          Serial.print(Frequenz);// Ausgabe des gemessenen Netzfrequenzwertes Messung + Kalibrierungswer 
          Serial.print('\r');
          Serial.print('\n');
          //Serial.println();
          break;
    } // case1
    
    case 2:    //Protokoll2  17-Byte    
    //                      0         1       
        {                 //012345678901234567
          char Str17[18] = "50000;00000;000";   
          word Freq2 = Frequenz;
          int NLD = MWAusgabe(Frequenz);
          byte Alb = Alarm;
          byte Parity = 0;
          Str17[15] = '\r'; // Carrige Return für SerialOutput
          Str17[16] = '\n'; // Carrige Return für SerialOutput          
          Str17[17] = '\0'; // String Ende         
          byte b;
          
          // Ausgabe Frequenz       
          for (int d = 5; d > 0; d--)
          {
            b = Freq2 % 10;
            Str17[d-1] = (b+48);
            Freq2 = Freq2 / 10;
          }

          // Ausgabe Netzlastdifferenz
          if (NLD > 9999) NLD = 9999;   // maxmimale Grenze Netzlastdifferenz Ausgabe
          if (NLD < -9999) NLD = -9999; // minimale Grenze  Netzlastdifferenz Ausgabe
          if (FA == 50)
          {
            if (Frequenz < 50000) Str17[6] = '-'; // negatives Vorzeichen 
            if (Frequenz > 50000) Str17[6] = '+'; // positives Vorzeichen   
          }
          if (FA == 60)
          {
            if (Frequenz < 60000) Str17[6] = '-'; // negatives Vorzeichen 
            if (Frequenz > 60000) Str17[6] = '+'; // positives Vorzeichen   
          }
          
          NLD = abs(NLD);
          for (int d = 10; d > 6; d--)
          {
            b = NLD % 10;
            Str17[d] = (b+48);
            NLD = NLD / 10;
          }

          // Ausgabe Alarme          
          Alb = Alarm;     
          for (int d = 14; d > 11; d--)
          {
            b = Alb % 10;
            Str17[d] = (b+48);
            Alb = Alb / 10;
          }

          // Sende 17-Bit-String
          Serial.print(Str17);           
      
          break;
        }// case2
         
      
    case 3:    //Protokoll3 24-Byte
    //                      0         1         2
        {                 //01234567890123456789012
          char Str22[24] = "NFA50000f00000P000M00C";   
          word Freq3 = Frequenz;
          int NLD = MWAusgabe(Frequenz);
          byte Alb = Alarm;
          byte Parity = 0;    
          byte b;
          
          // Ausgabe Frequenz       
          for (int d = 7; d > 2; d--)
          {
            b = Freq3 % 10;
            Str22[d] = (b+48);
            Freq3 = Freq3 / 10;
          }

          // Ausgabe Netzlastdifferenz
          if (NLD > 9999) NLD = 9999;   // maxmimale Grenze Netzlastdifferenz Ausgabe
          if (NLD < -9999) NLD = -9999; // minimale Grenze  Netzlastdifferenz Ausgabe
          if (FA == 50)
          {
            if (Frequenz < 50000) Str22[9] = '-'; // negatives Vorzeichen 
            if (Frequenz > 50000) Str22[9] = '+'; // positives Vorzeichen   
          }
          if (FA == 60)
          {
            if (Frequenz < 60000) Str22[9] = '-'; // negatives Vorzeichen 
            if (Frequenz > 60000) Str22[9] = '+'; // positives Vorzeichen   
          }
          NLD = abs(NLD);
          for (int d = 13; d > 9; d--)
          {
            b = NLD % 10;
            Str22[d] = (b+48);
            NLD = NLD / 10;
          }

          // Ausgabe Alarme          
          Alb = Alarm;     
          for (int d = 17; d > 14; d--)
          {
            b = Alb % 10;
            Str22[d] = (b+48);
            Alb = Alb / 10;
          }

          // Berechnung Prüfsumme
          for (int d = 3; d < 19; d++)
          {
            Parity = Parity ^ (byte)Str22[d];
          }

          byte k = Parity;
          
          // Ausgabe Prüfsumme
          for (int d = 20; d > 18; d--)
          {
            b = Parity % 10;
           // if (b <= 9) Str22[d] = (b+48); else Str22[d] = (b+55);
           Str22[d] = (b+48);
           Parity = Parity / 10;
          }

          Str22[0] = 'N';
          Str22[1] = 'F';
          Str22[2] = 'A';
          Str22[22] = '\r'; // Carrige Return für SerialOutput
          Str22[23] = '\n'; // Carrige Return für SerialOutput          
          Str22[24] = '\0'; // String Ende   

          // Sende 22-Bit-String
          Serial.print(Str22);            
         
          break;
        }// case4

    case 4:    //Protokoll4 29Bit Teilstring CSV-Datei
    //                      0         1         2         3 
        {                 //0123456789012345678901234567890
          char Str28[29] = "50000;00000;0;0;0;0;0;0;0;0";   
          word Freq4 = Frequenz;
          int NLD = MWAusgabe(Frequenz);
          byte Alc = Alarm;
          byte Parity = 0;
          Str28[27] = '\r'; // Carrige Return für SerialOutput
          Str28[28] = '\n'; // Carrige Return für SerialOutput         
          Str28[29] = '\0'; // String Ende         
          byte b;
          
          // Ausgabe Frequenz       
          for (int d = 5; d > 0; d--)
          {
            b = Freq4 % 10;
            Str28[d-1] = (b+48);
            Freq4 = Freq4 / 10;
          }

          // Ausgabe Netzlastdifferenz
          if (NLD > 9999) NLD = 9999;   // maxmimale Grenze Netzlastdifferenz Ausgabe
          if (NLD < -9999) NLD = -9999; // minimale Grenze  Netzlastdifferenz Ausgabe
          if (FA == 50)
          {
            if (Frequenz < 50000) Str28[6] = '-'; // negatives Vorzeichen 
            if (Frequenz > 50000) Str28[6] = '+'; // positives Vorzeichen
          }
          if (FA == 60)
          {
            if (Frequenz < 60000) Str28[6] = '-'; // negatives Vorzeichen 
            if (Frequenz > 60000) Str28[6] = '+'; // positives Vorzeichen
          }
             
          NLD = abs(NLD);
          for (int d = 10; d > 6; d--)
          {
            b = NLD % 10;
            Str28[d] = (b+48);
            NLD = NLD / 10;
          }

          // Ausgabe Alarme         
           if ( (Alarm & 1) == 1) Str28[12] = '1' ; else Str28[12] = '0' ; 
           if ( (Alarm & 2) == 2) Str28[14] = '1' ; else Str28[14] = '0' ; 
           if ( (Alarm & 4) == 4) Str28[16] = '1' ; else Str28[16] = '0' ; 
           if ( (Alarm & 8) == 8) Str28[18] = '1' ; else Str28[18] = '0' ; 
           if ( (Alarm & 16) == 16) Str28[20] = '1' ; else Str28[20] = '0' ; 
           if ( (Alarm & 32) == 32) Str28[22] = '1' ; else Str28[22] = '0' ; 
           if ( (Alarm & 64) == 64) Str28[24] = '1' ; else Str28[24] = '0' ; 
           if ( (Alarm & 128) == 128) Str28[26] = '1' ; else Str28[26] = '0' ; 
           
          Serial.print(Str28);
        
          break;
        }// case4      
    } // Switch

    if (sc > 50) // Sekundendurchlauf...
    {
      sc = 0;
            
      Alarm = Alarmausgabe();      
    }
        
    // LED 1
    Toggle = !Toggle;                       // toggle ausführen  LED-Ausgabe
    if (Toggle == true) digitalWrite(LED, HIGH); else digitalWrite(LED, LOW);

    // Watchdog- Reset
    if ( (FA == 50) && ((Frequenz > 44999) && (Frequenz < 55001))) wdt_reset();  
    if ( (FA == 60) && ((Frequenz > 54999) && (Frequenz < 65001))) wdt_reset();  
  } // if AuswertungA || AuswertungB

  // Überlauf Fehlererkennung...
  if (Reset_OK) ResetCounter = 0;
  else
  {
    ResetCounter++;
    if (ResetCounter >= 200)
    {
      Serial.println("failt / Error measurement (Trigger ResetCounter)");
      while (true) { delay(100); } // provoke watchdog reset
    }
  } 
  
  delay(5); // 5ms warten... bis Rücksprung Loop Anfang
 }


// Diff-Filter

word Diff_filterA(word filter_wert)
{

  int Diff = (int)filter_wert - CacheA;
  DeltaA = false;
  // bei Überschreitung DiffMAX    
  if ( abs(Diff) > DiffMAX )
  {
    if ( Diff > 0) filter_wert = CacheA + DiffMAX;  // Änderung (positive Steigung) max 
    if ( Diff < 0) filter_wert = CacheA - DiffMAX;  // Änderung (negative Steigung) max 
    DeltaA = true;
  } 
  
  CacheA = (int)filter_wert;
  return filter_wert;
}

word Diff_filterB(word filter_wert)
{

  int Diff = (int)filter_wert - CacheB;
  DeltaB = false;
  // bei Überschreitung DiffMAX    
  if ( abs(Diff) > DiffMAX )
  {
    if ( Diff > 0) filter_wert = CacheB + DiffMAX;  // Änderung (positive Steigung) max 
    if ( Diff < 0) filter_wert = CacheB - DiffMAX;  // Änderung (negative Steigung) max 
    DeltaB = true;
  } 
  
  CacheB = (int)filter_wert;
  return filter_wert;
}

// Delta Filter
bool Delta_filter(word FreqA, word FreqB)
{
  int xDiff = (int)FreqA - (int)FreqB;
  bool OK;

  // bei Überschreitung DeltaMAX    
  if ( abs(xDiff) >= 10 ) 
  {
    OK = false;
  }
  else OK = true;
  return OK;
}
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

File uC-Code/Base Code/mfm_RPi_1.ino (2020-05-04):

/*
  lauffähiges Programm Netzfrequenzmessung Serial-Output RPi-Board oder USB-TTL-Konverter
  OpenSource Basisversion,  03'2020 J. Müller
  Software unter GNU GPL3-Lizenz
  freie Verwendung für kommerzielle und private Projekte unter gleichen Bedingungen
  Programming languange: Arduino IDE (1.8.12)
  www.netzfrequenzanzeige.de  
  www.pc-projekte.de
  Version mit Differenz-Filter
*/

/*
 * Wichtig ! Die µControler-Fuses müssen korrekt eingestellt sein!
   Low lfuse = 0xFF; (B11111111)
   High fuse = 0xDA; (B11011110)
   Extended fuse = 0xFF; (B00000101)
 */

// Settings / Einstellungen*****************************************************************************
#define F_CPU 10000000
const word          Prescaler = 64;        // Prescaler (0,8,64,256,1024)    Prescaler-Auswahl (0,8,64,256,1024)
const byte          Messperiode = 18;      // Period                         Periodendurchläufe
const unsigned long Dividend = 2812500;    // DIVIDEND Calculation constant  Dividend Berechnungskonstante
const word          Sperr = 2400;          // Lock-Counts                    Vorgabe Sperrcounter
const int           UBRR = 0x40;           // Correction serial baud/clock   Anpassung Baud an Systemtakt
const int           DiffMAX = 60;          // DifferenzMAX                   maximal zulässiger Differenzwert zwischen den Messperioden
byte                FA = 0;                // Selection 0 = Auto, 50=50Hz, 60=60Hz     
const short         Calibration = 0;       // Korrekturwert                  Kalibrierung,Angaben in mHz.

// *****************************************************************************************************


word Frequenz;                              // mains frequency as WORD (mHz)  Netzfrequenz-Messwert als WORD in mHz
word fMess;                                 // preliminary measurement        vorläufiger Messwert
//double f;
//int Diff;                                 // Difference measurement         Differenzmesswert
word Triggersperr = Sperr;                  // Lockout-Counter (presetting)   Trigger-Sperrcounter mit Vorgabe


bool Auswertung = false;                    // Evaluation                     starte Auswertung aus Rohdaten
bool Check = false;                         // Measure Evaluation Check      Ergebniss 1.Prüfung

byte Periode = 0;                           // Period Counter                 Perioden-Durchlaufzähler
word Count = 0;                             // Raw Data Buffer                Zwischenspeicher Messwerte (Rohdaten)

const byte LED = 2;                         // Output LED RUN                 Ausgabe LED RUN
bool Toggle;                                // toggle auxiliary bit           Toggle-Hilfsbit

byte Ueberlauf = 0;                         // Overflow Counter               Überlaufs-Zähler

#include<avr/wdt.h>                         // Watchdog Vorbereitung...


// // '********** Einstellungen ****************

int Cachewert ;//As Long                                     'Ungefilterter Wert vom Sensor

//******************************************************

// // '********** Einstellungen ****************

int Sensor_wert ;//As Long                                     'Ungefilterter Wert vom Sensor 


//******************************************************




void setup()
{
  noInterrupts();                           // Alle Interrupts temporär abschalten

  // serial init
  Serial.begin(19200, SERIAL_8N1);
  UBRR0 = UBRR;                             // Korrekturwert/Anpassung an den 10MHz-Quarz

  // RUN-LED init
  pinMode(LED, OUTPUT);                     // LED Ausgabe vorbereiten

  //init Interrupt input 
  const byte interruptPin = 3;
  attachInterrupt(digitalPinToInterrupt(interruptPin), Mess, FALLING );

  //it inTimer1
  TCCR1A = 0;
  TCCR1B = 0;
  TCNT1 = 0;                // Timer nach obiger Rechnung vorbelegen
  if (Prescaler == 1024) TCCR1B |= (1 << CS12) | (1 << CS10);
  if (Prescaler == 256)  TCCR1B |= (1 << CS12);
  if (Prescaler == 64)   TCCR1B |= (0 << CS12) | (1 << CS11) | (1 >> CS10);
  if (Prescaler == 8)    TCCR1B |= (1 << CS11);
  if (Prescaler == 0)    TCCR1B |= (1 << CS10);
  TIMSK1 |= (1 << TOIE1);   // Timer Overflow Interrupt aktivieren

  interrupts();             // alle Interrupts scharf schalten

  wdt_enable(WDTO_4S);      //watchdog

  Serial.println("NFA-RPi 1.0 Basisprogramm (@Arduino)");
  Serial.println("05'2020 J.Müller www.pc-projekte.de");
  Auswertung = false;
  

  if ( !(FA == 50) && !(FA == 60 ))
  {    
  Serial.print("Auto-Detect...");
  delay(1000);

  while (Auswertung == false)
  {
  };
  
  if (Auswertung == true)
  {
    Auswertung = false;    
    //Check1 Messdifferrenzüberprüfung      
    fMess = (Dividend * 1000) / Count;   // Berechne vorläufige Netzfrequenz
    
    if ((fMess > 45000) && (fMess < 55000))  // Messwertauswahl 50Hz
    {
      Cachewert = fMess;
      FA = 50;
      Serial.println("  50Hz-Netz    ");
      delay(1000); 
    };
    
     if ((fMess > 55000) && (fMess < 65000))     // Messwertauswahl 60Hz
     {
      FA = 60;
      Serial.println("  60Hz-Netz    ");
      delay(1000);
     } 
    }
  } 
  //FA = 50;
  Serial.println("Start Netzfrequenzmessung...");
  Serial.write(7);
}


void loop()
{

  if ( Auswertung == true)
  {
    Auswertung = false;
    fMess = (Dividend * 1000) / Count;           // Berechne vorläufige Netzfrequenz   ... X 1000 = mHz
  //  f =   (double)fMess / 1000;

    // Prüfung: Messwert im Gültigkeitsbereich
    Check = false;
    if ( (fMess > 45000) && (fMess < 55000) && (FA == 50)) Check = true;
    if ( (fMess > 55000) && (fMess < 65000) && (FA == 60)) Check = true;

    // Wenn der Check ok, dann weiter zum Differenzfilter / Ausgabe
    if ( Check == true)
    {
      Frequenz = Diff_filter(fMess);
      Toggle = !Toggle;                       // toggle ausführen  LED-Ausgabe
      if (Toggle == true) digitalWrite(LED, HIGH); else digitalWrite(LED, LOW);
      wdt_reset();
    }
    
    Serial.println(Frequenz + Calibration ); // Ausgabe des gemessenen Netzfrequenzwertes + Kalibrierungswert

  };
  delay(50);
}

word Diff_filter(word filter_wert)
{

  int Diff = filter_wert - Cachewert;

  // bei Überschreitung DiffMAX    
  if ( abs(Diff) > DiffMAX )
  {
    if ( Diff > 0) filter_wert = Cachewert + DiffMAX;  // Änderung (positive Steigung) max 
    if ( Diff < 0) filter_wert = Cachewert - DiffMAX;  // Änderung (negative Steigung) max 
  }
  
  Cachewert = (int)filter_wert;
  return filter_wert;
}



ISR(TIMER1_OVF_vect) 
{
  Ueberlauf ++;
  if (Ueberlauf >= 10)
  {
    Serial.println("XXXXX");
    Ueberlauf = 10;
  }
}
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

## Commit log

2020-05-04 Upload µC File (Arduino)
2020-05-04 Upload New File
    [mfm_1.kicad_pcb]
2020-05-04 Update Circuit &amp; Board/KiCad_mfm_V1/.gitkeep, Circuit &amp; Board/KiCad_mfm_V1/mfm_1-cache.lib, Circuit &amp; Board/KiCad_mfm_V1/mfm_1-rescue.lib, Circuit &amp; Board/KiCad_mfm_V1/mfm_1.kicad_pcb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
    [mfm_1.kicad_pcb, mfm_1.sch]
2021-10-04 Update uC-Code/Base Code/.gitkeep, uC-Code/Base Code/Arduino-IDE_Info.txt, uC-Code/Base Code/mfm_RPi_1.ino, uC-Code/Base Code/mfm_RPi_1.ino.standard.hex, uC-Code/Extended/.gitkeep, uC-Code/Extended/A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
2022-05-03 Migrated to KiCAD v6 and updated footprints
    [mfm_1.kicad_pcb]

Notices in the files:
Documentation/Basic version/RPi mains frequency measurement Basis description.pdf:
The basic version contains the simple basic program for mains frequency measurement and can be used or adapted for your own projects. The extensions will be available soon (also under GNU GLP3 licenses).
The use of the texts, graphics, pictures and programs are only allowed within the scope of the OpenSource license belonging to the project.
